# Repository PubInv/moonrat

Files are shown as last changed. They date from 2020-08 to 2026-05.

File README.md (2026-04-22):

DOI: [10.5281/zenodo.17694076](https://zenodo.org/records/17694076) for Release V1.0.1

<h1 align="center">MoonRatII, A Tote-Size Portable Incubator for Rapid Field Work</h1>

Aliases used by other developers include [Moonrat](https://github.com/PubInv/moonrat/tree/main/legacy/moonrat), [Rice MiniCubator](https://github.com/PubInv/moonrat/tree/main/legacy/RiceMiniCubator), and [Rice Petri FI](https://github.com/PubInv/moonrat/tree/main/legacy/RicePetriFI). Visit the [Legacy](https://github.com/PubInv/moonrat/tree/main/legacy) folder for the work of volunteers prior to December 2022 and the hand built prototype.
**MoonratII** development effort began January 2023.   

# Status, March 01, 2026 
| Milestone | Target Date | Status |  
|---|---|---|
| Write and submit paper to *Hardware X*  | Feb 26, 2026  | 🟢 Completed  | 
| Project Closure  | Feb 28, 2026 | 🟢 Completed |

# Status, December 01, 2025  
| Milestone | Target Date | Status |  
|---|---|---|
| Write and submit paper to *Hardware X*  | Dec 04, 2025  | 🟢 Planned  | 
| Project Closure  | Dec 10, 2025 | 🟢 Planned |

# Status, November 17, 2025  
| Milestone | Target Date | Status |  
|---|---|---|
| New 3D printed controller enclosure top ordered from Xometry | Nov 18, 2025  | 🟢 Completed  | 
| Changes to controller enclosure top  | Nov 17, 2025  | 🟢 Completed  | 
| Write and submit paper to *Hardware X*  | Nov 25, 2025  | 🟢 Planned  | 

### Updated controller enclosure top design
- Realigned power port opening with enclosure bottom.
- Shifted and enlarged key cap holes for improved clearance.
Untitled design

# Status, November 02, 2025  
The project build is complete. 




| Milestone | Target Date | Status |  
|---|---|---|
| Write and submit paper to *Hardware X*  | Nov 20, 2025  | 🟢 Planned  | 
| Project Closure  | Nov 21, 2025 | 🟢 Planned |

Screenshot 2025-08-28 at 5 58 10 PM

# Status, August 2025  

The mechanical design phase for the MoonRat II enclosure is officially complete. All recent updates, including finalizing mounting holes, component spacing, and structural parameters, have been committed. The finalized design files are now being test printed. 
Pending a successful print, the enclosure will be ready for assembly.

**Latest Progress -> We’re finalizing all updated FreeCAD 3D models by next week!** This includes:  
- New enclosure design - improved insulation/portability 
- Redesigned controller mounts - 3D-printed, better cable management
- Mechanical optimizations - easier assembly/maintenance

### Next Steps  
| Milestone | Target Date | Status |  
|---|---|---|
| FreeCAD model completion | Aug 20, 2025  | 🟡 In progress |  
| MVP prototype build | Aug 27, 2025 | 🟢 Planned |  
| Write and submit paper to *Hardware X*  | Nov 15, 2025  | 🟢 Planned |  

---  
**Hardware X Paper Focus**:  
- Open-source medical hardware  
- Low-cost neonatal incubator design  
- Reproducibility documentation ([Journal guidelines](https://www.journals.elsevier.com/hardware-x))  

# Status, April 28, 2025  
Created a standalone schematic for heaterboard PCB.

# Status, January 2025  
#### Project presentation on YouTube (Click image to watch)

Watch the video (https://www.youtube.com/watch?v=yTW_BcTsaGw&t=22s)
#### Updated Experiment.com succesful project funding round
In January 2023, 13 generous patrons funded the production of five complete MoonRatII prototypes. we updated them with the [project results](https://experiment.com/projects/tote-size-portable-incubator-for-rapid-field-work
).
#### 2024 field testing resulted in future unit changes:
- Heater board redesign with a Dallas One wire digital temperature thermometer and a 4.7 ohm pull up resistor.
- Design a universal heater board cage to secure the heater board beneath the container lid in any external enclosure.
- Adjust top button spacing in KiCad.
- Add bottom mounting holes to the enclosure.

# Status, November 2024 
A scientific research paper is tentatively scheduled for March 2025 in the HardwareX journal.

# Status, September 2024  
Prototypes of the MoonratII were field tested in two locations - the Galapagos Islands by researcher Auja Bywater and in Tanzania by Dr. Robert Read. The heater features the TMP36 low voltage temperature sensor. A HardwareX scientific research paper is slated for October 2024 publication.

# Status, April 2024  
The MoonRatII team has produced five Printed Circuit Assemblies (Control and Heater) of the Rev 1 PWB for use by the USA team and five Printed Circuit Assemblies (Control and Heater) of the Rev 2 PWB for use by  the Mexico team. Enclosure design for the Controller Assembly of Rev 3 PWB is underway TBA. 

# Status January 2024
[Dr. Robert Read](https://www.pubinv.org) and [Melanie Laporte](https://github.com/melanielaporte) presented the MoonRatII project. Watch the [presentation](https://www.youtube.com/watch?v=yTW_BcTsaGw&t=22s). 

# Current Design Summary
In one schematic and PCB, we have developed a "Control Assembly" and a "Heater Assembly".  
- The Control Assembly will be in an enclosure detachable from the incubation chamber.  
- The Heater Assembly will mounted internal to the incubation assembly under the unit top. Current to a heating pad or pads has changed from the previously used TMP36 low voltage temperature sensor to a digital temperature sensor. 
- A rechargable battery with its recharging station will complete a MoonRatII incubator system.
  
## Image Gallery - Current FreeCAD Assembly Designs
|A |B |C |
| --- | --- | --- |
|  |  | |
|  |  |  |
|  |  |  |  

# 2023 MoonRatII Design

### Fundamental Modularity: The 6-wire appliance 
The connections from the controller to the heater needs only 6 wires:
1. GND (ground, nominally voltage 0).
2. +12V PWR (the heating elements requires approximately 12V power).
3. HEAT ON (Vin).
4. +5V (for the thermometer).
5. SIG - data from the digital "one-wire" format.
6. UNK - a final wire is included for future functionality that is unknown right now.  It is connected as a redundant ground in Rev 1 and Rev 2.

These (esp. the power) should probably be rated for 2 amps, but in practice 1 amp is probably good enough.

## Initial Design Approach Block Diagram
From the 2020 design.  
<a
href="https://user-images.githubusercontent.com/5296671/86680945-b470ad80-bfc4-11ea-9ef6-19c4f70aceba.png">https://user-images.githubusercontent.com/5296671/86680945-b470ad80-bfc4-11ea-9ef6-19c4f70aceba.png  
Basic Structure of Portable Incubator (1)
</a> 

## Motivation
By building a small, portable, intelligent incubator that can maintain constant elevated temperature, a variety of biological experiments and assays can be
performed "in the field" without having access to a electric grid power.

## Origin
This is an offshoot of the [Rapid E. coli project](https://github.com/PubInv/rapid-e-coli). It is an attempt to build a better, smaller, more intelligent
portable incubator that the Armadillo, described [elsewhere](http://jhe.ewb.org.au/index.php/jhe/article/view/127) and buildable from an [instructable](https://www.instructables.com/id/Portable-Petrifilm-Incubator-for-Inexpensive-In-Fi/).

## References (Incomplete)
- Petrifilms [https://www.3m.com/3M/en_US/company-us/all-3m-products/~/ECOLICT-3M-Petrifilm-E-coli-Coliform-Count-Plates/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](https://www.3m.com/3M/en_US/company-us/all-3m-products/~/ECOLICT-3M-Petrifilm-E-coli-Coliform-Count-Plates/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)
- EPA Guidelines [https://19january2017snapshot.epa.gov/sites/production/files/2015-11/documents/drinking_water_sample_collection.pdf](https://19january2017snapshot.epa.gov/sites/production/files/2015-11/documents/drinking_water_sample_collection.pdf)
- Original Incubator Paper [http://jhe.ewb.org.au/index.php/jhe/article/view/127](http://jhe.ewb.org.au/index.php/jhe/article/view/127)
- Construction of a Low-cost Mobile Incubator for Field and Laboratory Use [https://www.jove.com/t/58443/construction-low-cost-mobile-incubator-for-field-laboratory](https://www.jove.com/t/58443/construction-low-cost-mobile-incubator-for-field-laboratory)
- Solar Powered Portable Culture Incubator [https://www.jscimedcentral.com/Pediatrics/pediatrics-3-1063.pdf](https://www.jscimedcentral.com/Pediatrics/pediatrics-3-1063.pdf)
- World Health Organization
- Fuzzy Logic - 

## Acknowledgements
Thanks to [Dr. Sabia Abidi](https://profiles.rice.edu/faculty/sabia-abidi) of Rice University for input and references.

## MoonratII Team
[Robert L. Read - Founder of Public Invention](https://github.com/PubInv/) 

[F. Lee Erickson](https://github.com/ForrestErickson)

[Melanie Laporte](https://github.com/MelanieLaporte)  

[Silvia Castillas](https://github.com/SilviaKarbid)  

[Harshit Kumar](https://github.com/harshit9602)

[Enrique Ruiz](https://github.com/kurama79) 

[Horacio Garcia](https://github.com/HJGV05) 

<hr>
<h6><i> Updated by Melanie Laporte, 20240512</i></h6>

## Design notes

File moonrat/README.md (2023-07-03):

This folder contains information, files and folders, for the hand build Moonrat of 2020.

This folder has work Halimat did including soldering together the board of the incubator which Robert Read took to Tanzania.

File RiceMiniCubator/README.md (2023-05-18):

# RiceMiniCubator  
This folder contains the Moonrat development effort artifacts of Rice University students of 2020.

The RiceMiniCubator  
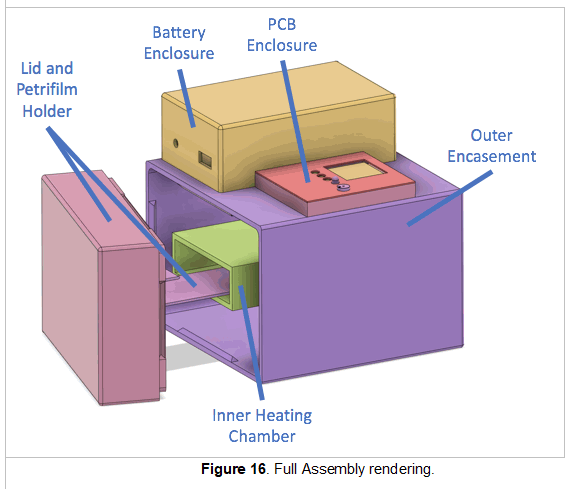
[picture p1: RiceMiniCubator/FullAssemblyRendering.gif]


## Project Summary
Implimented with an Arduino NANO this effort included design of a 3D printed incubation chamber. 
The chamber was insulated with polyurathan expanding foam.

### Electronic Details
The electronics include
* Arduino Nano, Embedded controller assembly
* OLED display, 128x128., User output
* Three buttons, User input
* Piezo Buzzer, User alert
* Termistor, for temprature measurement
* IRLB8721 MOSFET, to switch heater current
* Battery, ???

See: [CircuitHardware_MinicubatorTeam_Cycle5.pdf](CircuitHardware_MinicubatorTeam_Cycle5.pdf) for schematic and PCB screen shots
See: [AssemblyInstructions_MinicubatorTeam_Cycle5.docx](AssemblyInstructions_MinicubatorTeam_Cycle5.docx)

### Project Firmware
See the files in forlder: Code_MinicubatorTeam_Cycle5

### Enclosure Details
See the files in the folder: CAD_MinicubatorTeam_Cycle5

<hr>
<h6><i> This file created by F. Lee Erickson, 20230518</i></h6>

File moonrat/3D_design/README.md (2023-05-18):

# 3D_design
This folder contains artifacts of the design of base to hold a thermos used to incubate samples.

<a
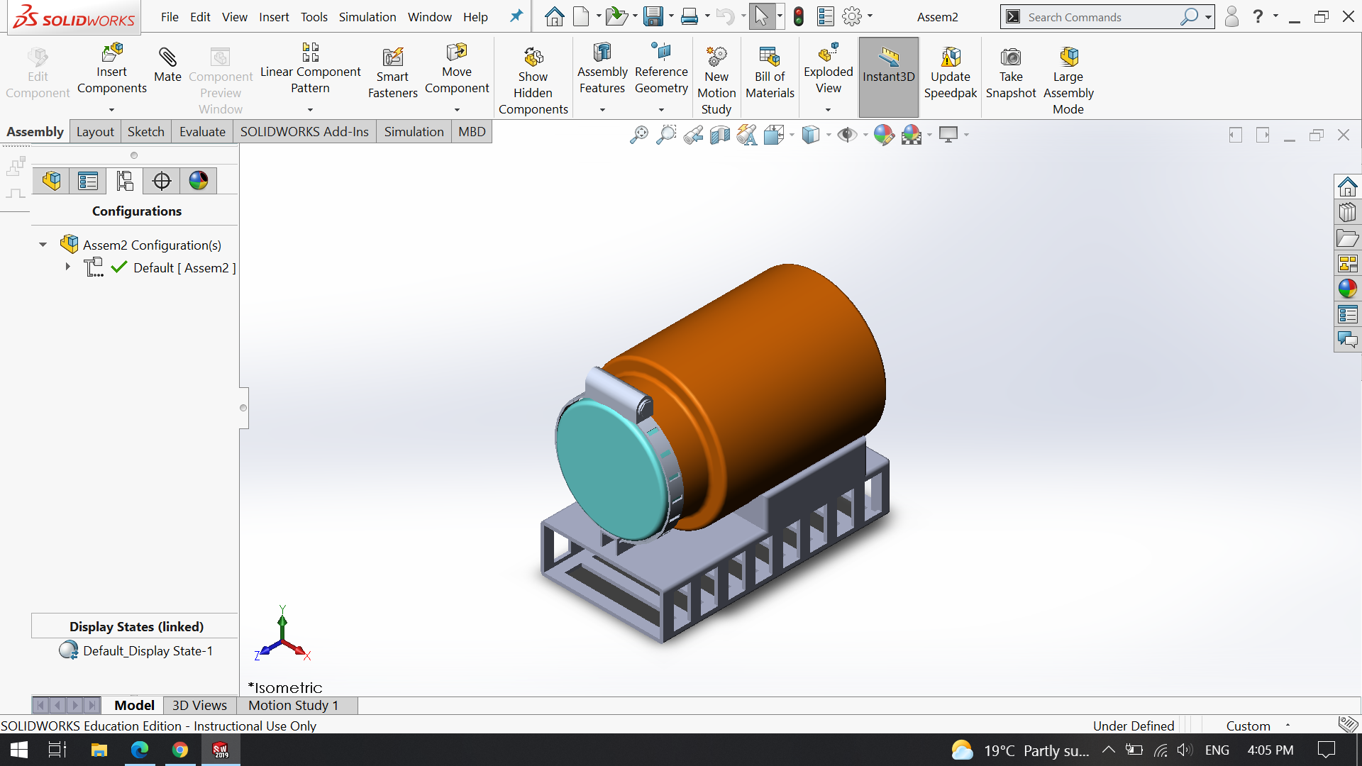
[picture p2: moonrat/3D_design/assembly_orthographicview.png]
href="./assembly_orthographicview.png">
</a> 

<a
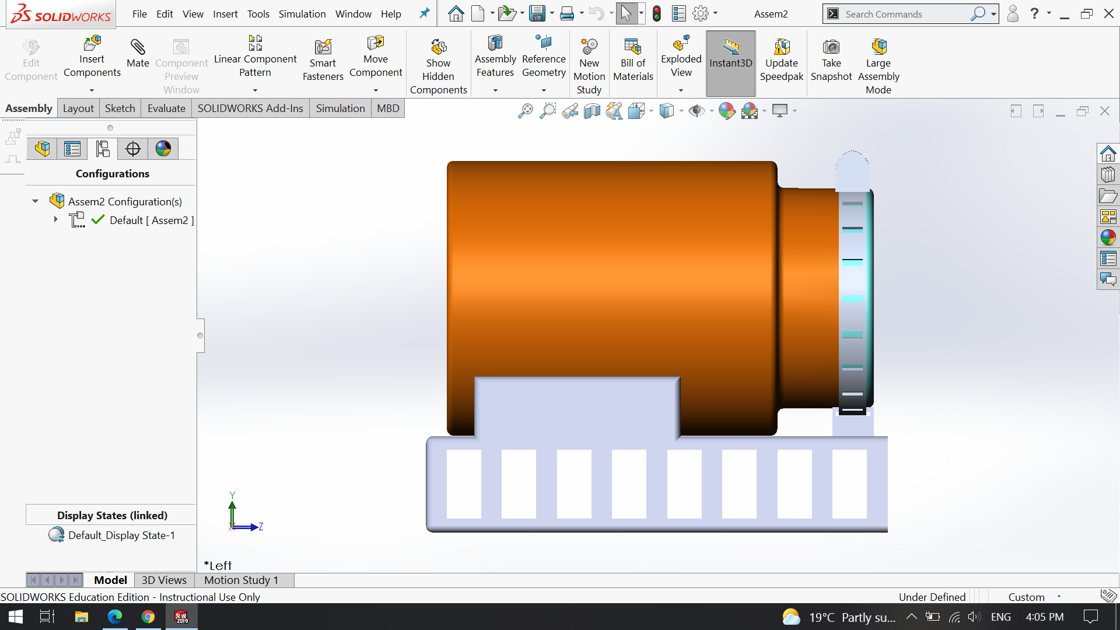
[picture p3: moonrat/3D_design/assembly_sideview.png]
href="./assembly_sideview.png">
</a> 
<a
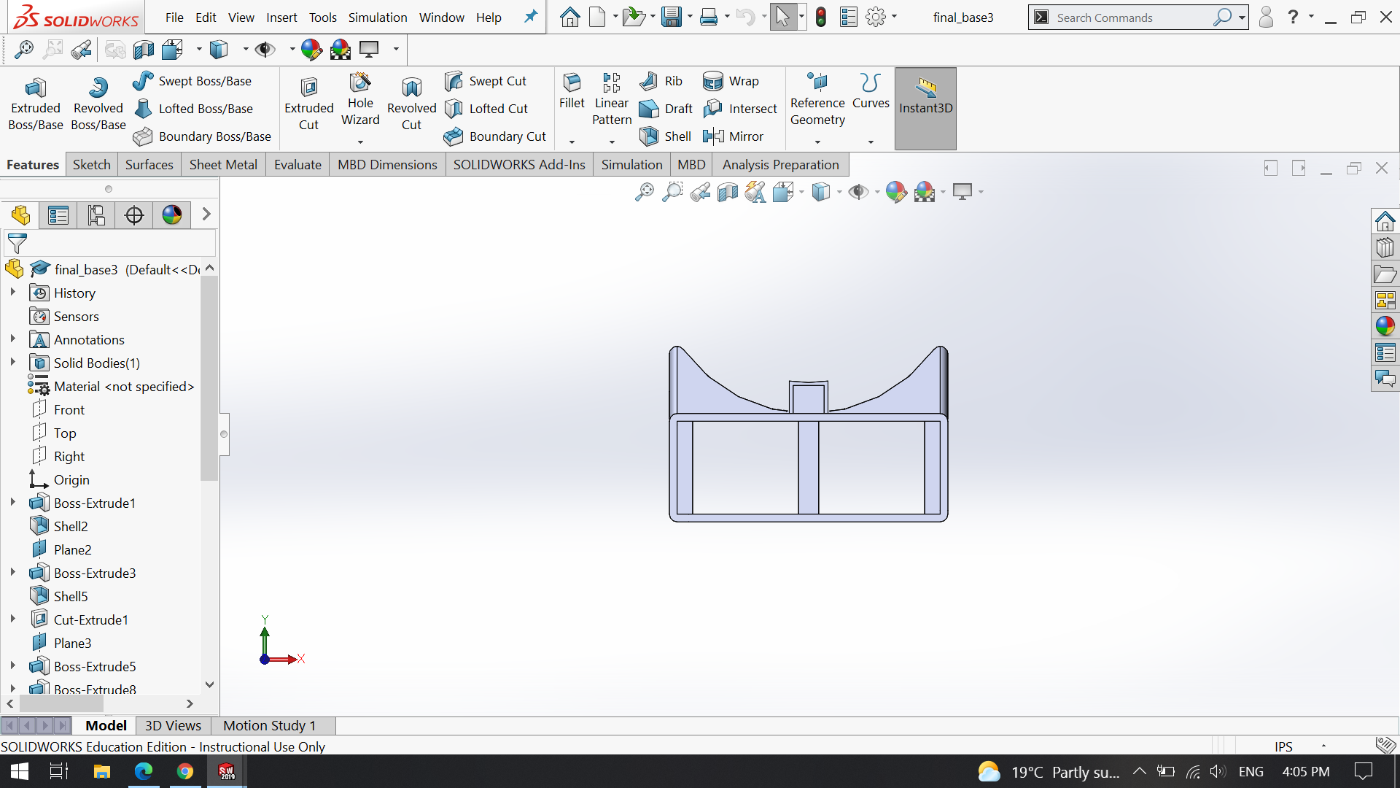
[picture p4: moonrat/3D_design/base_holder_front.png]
href="./base_holder_front.png">
</a> 

<a
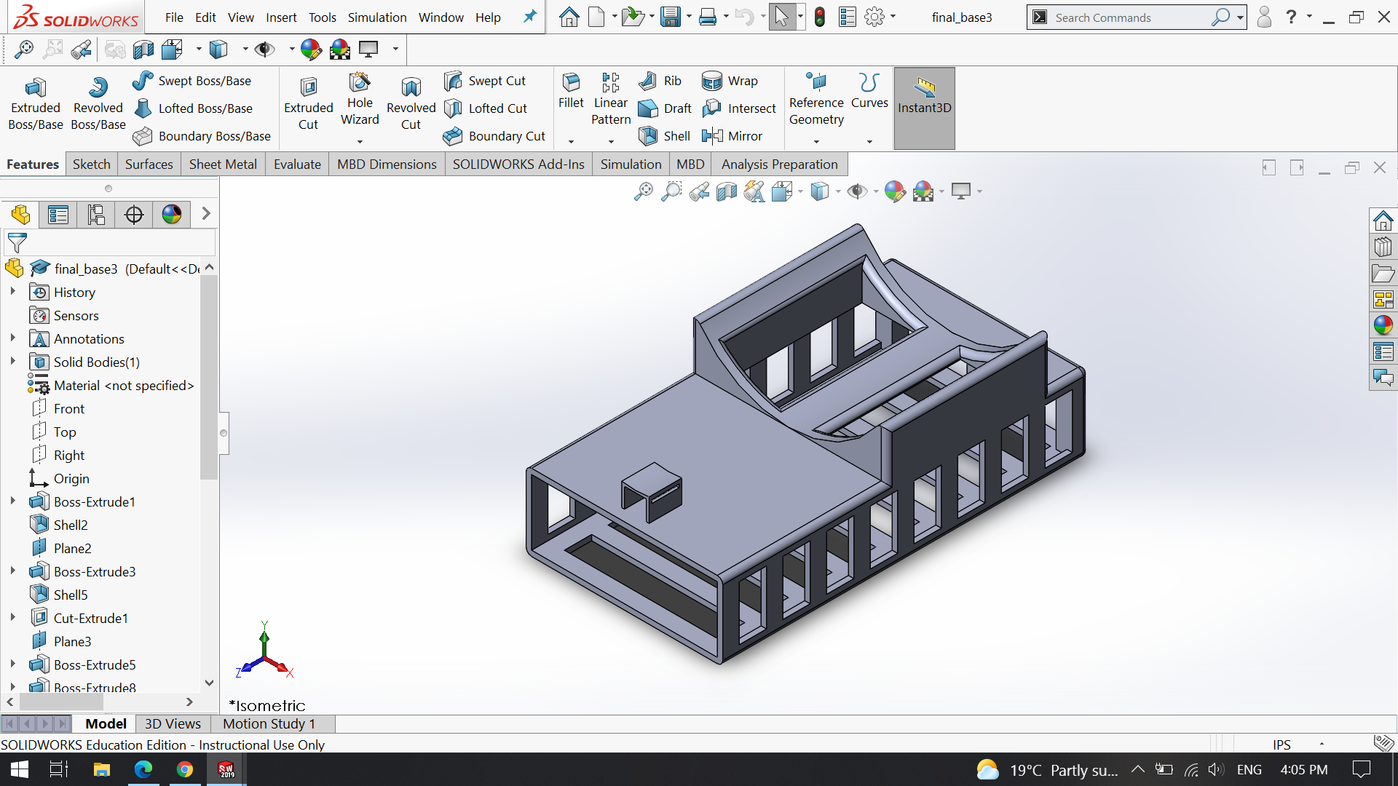
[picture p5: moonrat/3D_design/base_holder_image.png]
href="./base_holder_image.png">
</a> 

<a
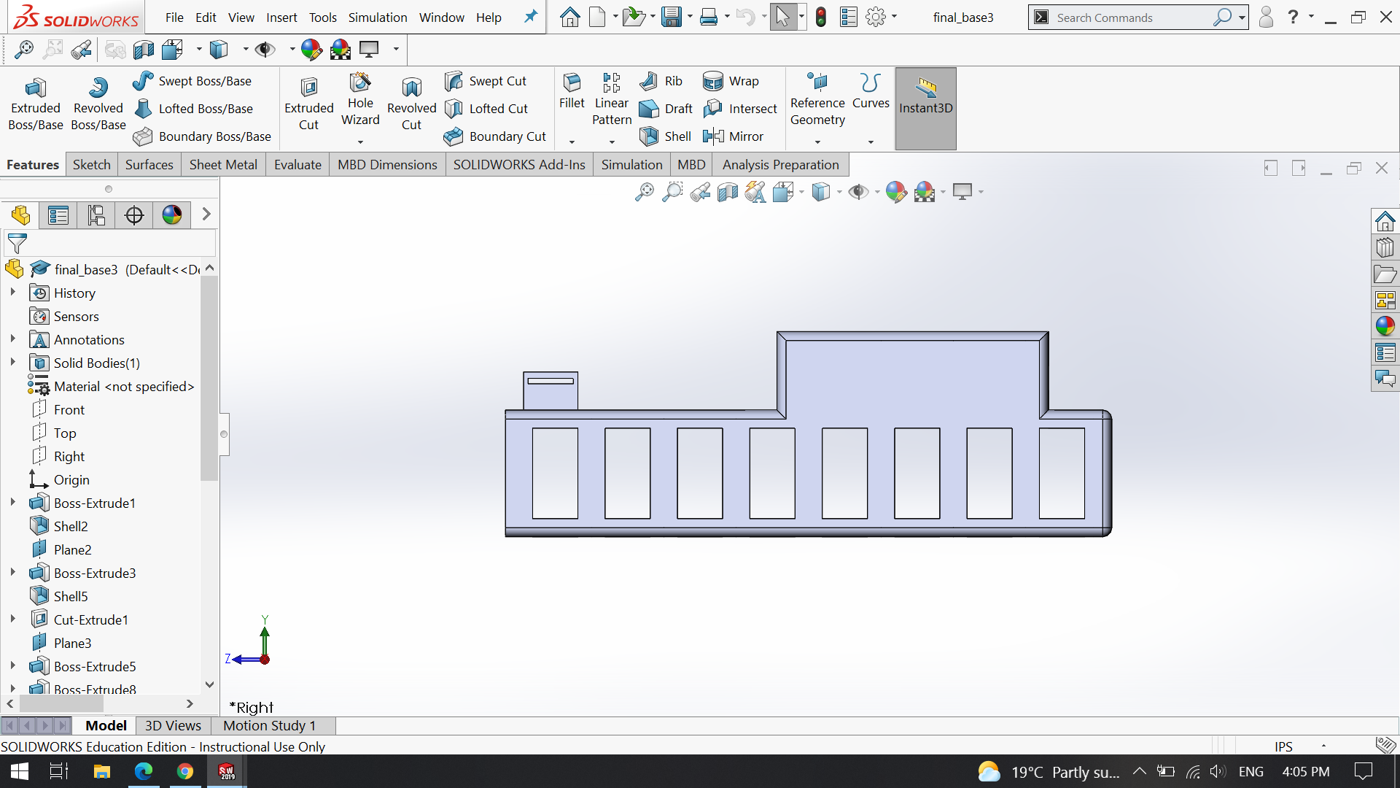
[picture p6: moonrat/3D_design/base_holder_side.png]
href="./base_holder_side.png">
</a> 

[And an animation of the assembly](assembly_animation.mp4)

<hr>
<h6><i> This file created by F. Lee Erickson, 20230518</i></h6>

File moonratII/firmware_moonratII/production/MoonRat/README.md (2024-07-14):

IMPORTANT NOTE: It is necessary to include within the Arduino IDE the eFLL library for the fuzzy controller and the necessary libraries for the Arduino UNO R4 version to be used.

Improvements of this version:
1.- Fixed the temperature conversion needed for the TMP37 sensor embedded in the T6G IC, the ADC reading problems for the Arduino UNO R4 have been fixed.
1.- Added a reset command during incubation by simultaneously pressing the three buttons on the board.
2.- Modified the sample selection screen to directly display the desired incubation temperature (modify if necessary).
3.- A menu was added to select the required incubation hours (modify if necessary).
4.- An acoustic alarm was added to notify that the incubation time has been completed. 
5.- A command was added to exit the completed incubation time alert by simultaneously pressing the up/down buttons.

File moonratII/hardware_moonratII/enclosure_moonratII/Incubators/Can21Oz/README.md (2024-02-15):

# Can21Oz "Incubator"
An experiment in measuring temperature characteristics of a heated system.  


## The incubator, Can21Oz

### Construction
It is fabricated out of a 21oz can which held fruit.  
The can empty weight is 62gm assumed to be steel.  
The can when full of water is 600 to 649 gm.  
The water mass is therefor about 587 gm  
The sides of the can are insulated with a layer of bubble wrap about 3/8 inch think.  
The top is open.  
The can is sitting on a 3 1/2" thick 89 mm polystyrine foam block.  

#### Can Dimensions
Radius = (3 3/8)/2 = 1.6875" = 42.9mm  
Height = 4 1/2 " =  114.3mm  
Volume = Pi * R^2 * H = Pi* 42.9^2 * 114.3 = 331,000 mm^3  
Surface Area = (2 * Pi * R^2) + (2 * pi * R * H) = 11,560 + 30,810 = 42,370 mm^2  

#### System Heater
A relay switched, 120VAC, Immersion heater.   
https://www.amazon.com/dp/B01M0Q84BR?psc=1&ref=ppx_yo2ov_dt_b_product_details  
120 volts and 300 watts. UL approved.  

### The System
| This "incubator" is more like a hot water bath. 	| The 120V AC Heating Element 	| 	|
|---	|---	|---	|
|  	|  	| 	|

## Instruments, Temperature Measurement
Three MAX31850 thermocouple amplifiers with K type thermocouples immersed into the water in the 21Oz can.  
They are held to the side of the can with a wooden cloths pin.  
The exact location of the thermo couple junctions was not well constrained.  
Measurement displayed by a Cumulocity dash board.  

## Experiments
### Near Boiling, Warm Up / Cool Down
**Heat Up**  
At 4:02 PM EST or so plug in heater.  

At about 4:04 the temperature had risen about 23 degrees or about 1/e of the way from 19 to 95C.  
Time rise would be about 120 seconds **but this curve is not a full exponential** so the rise time is longer.

**Cool Down**  
Unplug at about 4:12 PM EST.  
From a peak of about 98 to 19 is 79. About 1/3 of that is 24 so at 98-24 about 75 C which happnes at about 4:25 PM.  
  
4:12 from 4:25 is 13 minutes or 780 seconds for about one time constant.

### One Minute Rectangular Heat / Cool
Heat with a rectantular profile at the full power of the immersion heater.
At 10:34💯 AM EST connect heater to 120V AC.  
At 10:35:00 AM EST disconnect heater from 120V AC.  

**Heat Up Detail**
Just before or at turn on  

About one minute later  


**Cool Down Detail**  


The tempaterature at the start was the ambient of about 18 C.  
The peak temperature on the thermocouple labeled Getter reached 56.25 C.  


On the cool down, the 1/e (One time constant) temperature would be at about 42 degrees which happened at about 10:38. From the 10:35 turn off this is three minutes or 180 seconds.  


## Conclusion.
The system has significantly faster rise time than fall time.  
The time constant for cooling down from near boiling temprature was 780 seconds while the time constant from a peak of 52.25 was only 180 seconds.  
I hypothesize that, for the one minute heating experiment, the heat was not fully distributed through the water in the sample (it was not in equilibrium).

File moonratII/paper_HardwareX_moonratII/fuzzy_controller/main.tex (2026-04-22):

\documentclass{article}
\usepackage{graphicx} % Required for inserting images

\usepackage[backend=biber]{biblatex}
\addbibresource{Bibliography.bib}

\title{The Fuzzy Logic Controller Used in the Moonrat~II}
\author{Horacio García--Vázquez}
\date{April 2026}

\begin{document}

\maketitle

\section{Fuzzy Logic Controller Strategy}

Precise and adaptive temperature control is essential in cultivation chambers for Petrifilm samples. To achieve this, we implemented a \textit{Mamdani--type fuzzy controller}. This approach is efficient and easy to apply to systems with slow dynamic evolution, such as temperature and heat control processes \cite{Sherif2014,Vijayalakshmi2017,Izquierdo2018,Coban2019,Sakaci2021}. 

To enable integration into an embedded system, we employed the \textit{Embedded Fuzzy Logic Library (eFLL)} developed by AJ Alves \cite{eFLL}. This library provides a standardized implementation of fuzzy control for embedded computing platforms.  

The system relies solely on measuring the chamber temperature and a predefined reference value. Consequently, we designed a \textit{Mamdani--based fuzzy control scheme} with two input variables:
\begin{itemize}
\item \textbf{Error} ($e$): The difference between the measured temperature $temp_c$ and the desired temperature $temp_r$:
\begin{equation}
e = temp_c - temp_r
\end{equation}

\item \textbf{Error difference} ($\Delta e$): The discrete change in error between two sampling instants:
\begin{equation}
\Delta e = e(t_k) - e(t_k - 1)
\end{equation}
\end{itemize}

We defined both input variables using three fuzzy sets: \textit{negative, zero, and positive}. We established the relationship between these variables and the controller’s response through a \textit{set of fuzzy rules}, as detailed in Table~\ref{tab:fuzzy_rules}.  

\begin{table}[h]
\centering
\renewcommand{\arraystretch}{1.3}
\setlength{\tabcolsep}{10pt}
\begin{tabular}{cc|ccc}
\hline\hline
\multicolumn{2}{c|}{\multirow{2}{*}{\textbf{Control}}} & \multicolumn{3}{c}{\textbf{Error Difference}} \\ 
\cline{3-5}
\multicolumn{2}{c|}{} & \textbf{Negative} & \textbf{Zero} & \textbf{Positive} \\ 
\hline\hline
\multirow{3}{*}{\textbf{Error}} 
& \textbf{Negative} & P & P & Z \\ \cline{2-5}
& \textbf{Zero}     & P & Z & N \\ \cline{2-5}
& \textbf{Positive} & Z & N & N \\ 
\hline\hline
\end{tabular}
\caption{Fuzzy control rule table. P = Positive, Z = Zero, N = Negative.}
\label{tab:fuzzy_rules}
\end{table}

The system's output variable is the \textit{PWM frequency}, which regulates the power supplied to the thermal pad responsible for heating the chamber. We defined this output using three fuzzy sets: \textit{high, medium, and low frequency}.  

We carried out the fuzzy system design, including the membership functions of the input and output variables, using the \textit{Fuzzy Logic Designer} toolbox in MATLAB.~Figure~\ref{fig:membership_functions} illustrates the configuration of the membership functions and the assigned ranges for each fuzzy set.

\begin{figure}[ht]
\centering
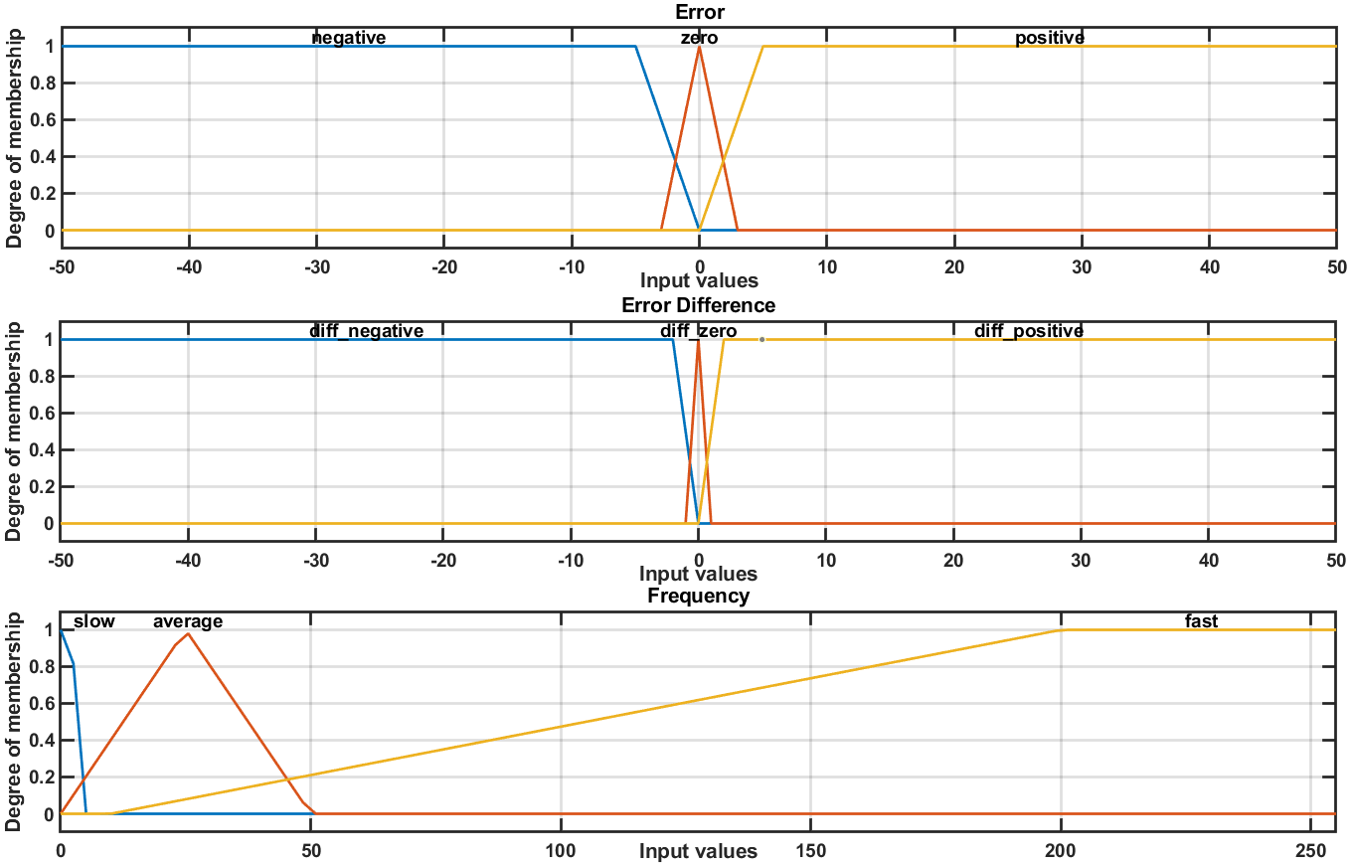
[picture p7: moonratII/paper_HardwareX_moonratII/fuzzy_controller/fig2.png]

\caption{Membership functions for the fuzzy system inputs and outputs, designed using the Fuzzy Logic Designer toolbox in MATLAB.}
\label{fig:membership_functions}
\end{figure}

Finally, we defined the \textit{defuzzification process} and the configuration of membership degrees according to the parameters shown in Figure~\ref{fig:defuzzification_config}.  

\begin{figure}[ht]
\centering
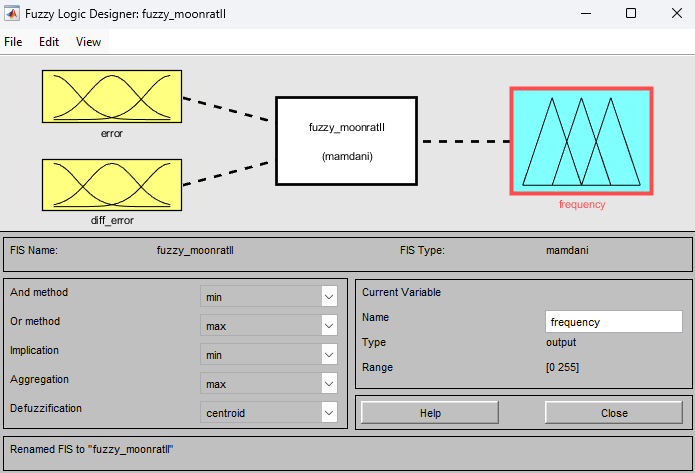
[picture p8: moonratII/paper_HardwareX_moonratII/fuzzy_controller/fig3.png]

\caption{Defuzzification and membership function configuration for the fuzzy control system.}
\label{fig:defuzzification_config}
\end{figure}

\printbibliography

\end{document}

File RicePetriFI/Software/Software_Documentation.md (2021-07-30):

# Team Petri-FI Software Documentation

## Introduction

Team Petri-FI made progress in designing software to perform the incubation of Petrifilms inside of a small heating chamber equipped with a digital thermometer and heating pad(s). The code itself includes contributions from previous student teams as well as the Public Invention Moonrat team. The software’s goal is to provide an intuitive user experience for setting up an incubation and performing that incubation over the desired time period (generally, 48 hours). Team Petri-FI has developed two sketches for the Arduino Uno; these files can be uploaded to the Arduino, and the incubator can be powered with a battery. This documentation will describe the functionality of the existing code and the differences between the two files.

## "PetriFI.ino"

The main Arduino sketch that Team Petri-FI has used is called “PetriFI.ino.” This sketch was the original Team Petri-FI file, and it has undergone the most testing. This sketch makes greater use of Minicubator’s heating algorithm, which makes use of temperature thresholds to control the temperature inside the incubator. For example, this software will wait for the temperature to drop below an appropriate temperature before turning on the heating pad, and waiting to reach the target temperature again. In our own incubation testing, we have observed large temperature oscillations that result from the use of this algorithm (1 to 2 degrees Celsius below the target temperature), in which the temperature swings past the thresholds set by the software. In testing, this software was able to keep the temperature near the target temperature for a full 48-hour incubation, and it was still able to successfully incubate E. coli colonies.

Upon startup, this sketch allows users to set the duration and temperature of the incubation, and start the incubation. Once the incubator reaches the target temperature, it will enter the main incubation phase, and will proceed for the full duration (in hours) set at the beginning. The user interface is still limited, and does not allow interaction during the main incubation phase.

For data logging, this code utilizes a microSD card connected to the OLED screen. Our team struggled to get the SD card working consistently, so further testing is still required. We have written a function to write a single temperature to the SD card (into a .csv file), along with the time at which the temperature was recorded. For testing purposes, this sketch will record a temperature value occasionally, about every minute, but in the future the code should be able to record data at more consistent intervals. It may also be valuable to keep a running average of data points and write the average to the SD card every couple of minutes. Additionally, for testing, we chose to also write some values during the pre-heating phase. Since the “clock” hasn’t started during this phase, and to prevent confusion with legitimate values recorded during the incubation, we have assigned these a time value of -1. Later, these temperature values can be omitted, since they are not as important in evaluating the success of a full incubation.

When adding the capabilities for the SD card, we found that it was important which pins were connected at the Arduino Uno. In particular, the “SPI Bus” (pins 10-13) of the Uno were important for writing to the SD card. Here, we have included a list of pins that we have used with the Uno. Below, the first seven connections are to the OLED screen, which contains both the display and the SD card. The SD Chip Select pin must be the hardware SS pin (pin 10 on the Uno) so that the SD card can use the SPI bus. If possible, all of pins 10-13 should be connected as described below in order to utilize the SD card. The screen itself will work even if the SPI bus is not used, but the SD card requires the SPI bus (SDCS, MOSI, MISO, and SCLK). 

### Arduino Uno Pin Setup

| Connection | Pin Number |
|---|---|
| SD Chip Select (SDCS) | 10 |
| MOSI | 11 |
| MISO | 12 |
| SCLK | 13 |
| DC | 4 |
| OLED Chip Select (OLED CS) | 5 |
| RST | 6 |
| Up Button | 3 |
| Select Button | 8 |
| Down Button | 9 |
| Transistor (Heating Pad) | 2 |
| LED | 0 |
| One-Wire Bus (Digital Thermometer) | 7 |
| Piezo Alarm | A1 (Analog Pin 1) |

## "PetriFI_PID.ino"

The most recent sketch is called “PetriFI_PID.ino,” and it is an attempt to implement a PID controller for temperature. This separate sketch was made to isolate the many changes that would need to be made for the PID controller. The goal of the PID controller is to hold the temperature perfectly steady by controlling the heating pad. This would alleviate the problems that we have observed with temperature oscillations of more than one degree Celsius. This sketch is designed to be almost identical in functionality to the original sketch, but to better control the temperature during the incubation period.

Currently, this PID controller code is not working. This sketch makes use of the “PID_v1.h” Arduino library. In our understanding, the PID controller will update its output as a value between 0 and 255. This value should describe how much the heating pad needs to be turned on after each loop. Then, the sketch can use that value to control the heating pad in a couple of ways. The most fluid way to control the heating pad is to use pulse-width modulation with the 0-255 PID output. However, the time constant of the chamber is fairly high (it takes multiple minutes for the temperature to change by even just one degree Celsius), and pulse-width modulation would mean that duty cycle calculations (what percentage of the time the heating pad is ON) might be less accurate. Additionally, we were somewhat concerned about switching losses associated with switching the heating pad state multiple times each second. Instead, we attempted to convert the PID output (0-255) into either a “heating pad on” or “heating pad off” command, using a threshold. Thus, when the output reaches the threshold, then the heating pad would be turned on until the output fell below the threshold again.

We have not yet been able to use the PID controller, but we have used print statements to perform some troubleshooting. Most recently, the output of the PID controller remained at 0 despite adjustments to various parameters. We believe that once the PID controller is implemented into this sketch, it may require some “tuning” of the threshold and the PID parameters, but that it will be able to control the temperature better than “PetriFI.ino.” Below we have provided some of the resources related to the PID library that were useful to us.

https://playground.arduino.cc/Code/PIDLibrary/

https://github.com/br3ttb/Arduino-PID-Library

## Areas for Further Testing or Improvement

We hope that a few improvements can be made to our software in the future. First, we believe that the PID controller would significantly improve the consistency of incubation. Some debugging is still needed for this, but “PetriFI_PID.ino” should be nearly ready to use if the PID controller is correctly implemented.

We have also worked hard on a new user interface that would help make the device “smarter” and more intuitive to work with. It would also allow users to interact with it during the incubation cycle. We have provided diagrams and many more details within our user interface documentation, but we believe that it would be a great improvement to the user experience. Based on the lifespan of the LEDs inside the OLED screen, it may also be important to create a timer for the screen to turn off during the main incubation period to reduce power consumption and increase the lifespan of the screen.

While the SD card did not work consistently with our system, it was occasionally able to write a temperature value to the SD card. On another system, or with a few adjustments, the SD card may be able to work very consistently. As part of the data display, it may also be useful to provide functions to read desired values from the SD card and display them onto the user interface. Therefore, we have a created part of a function, “readTempFromSD(int seconds),” that could read a single temperature value from the SD card. This could be used to improve data logging and retrieval capabilities, so that the user would not need to remove the SD card from its slot in order to evaluate the success of an incubation.

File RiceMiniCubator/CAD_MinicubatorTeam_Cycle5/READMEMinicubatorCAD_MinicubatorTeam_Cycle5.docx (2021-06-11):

Note: All drawings except for the inner heating chamber remain the same as from Cycle 4. The inner heating chamber has been revised, but can still be represented by the green inner chamber render from the previous cycle as the inner dimensions are equal.

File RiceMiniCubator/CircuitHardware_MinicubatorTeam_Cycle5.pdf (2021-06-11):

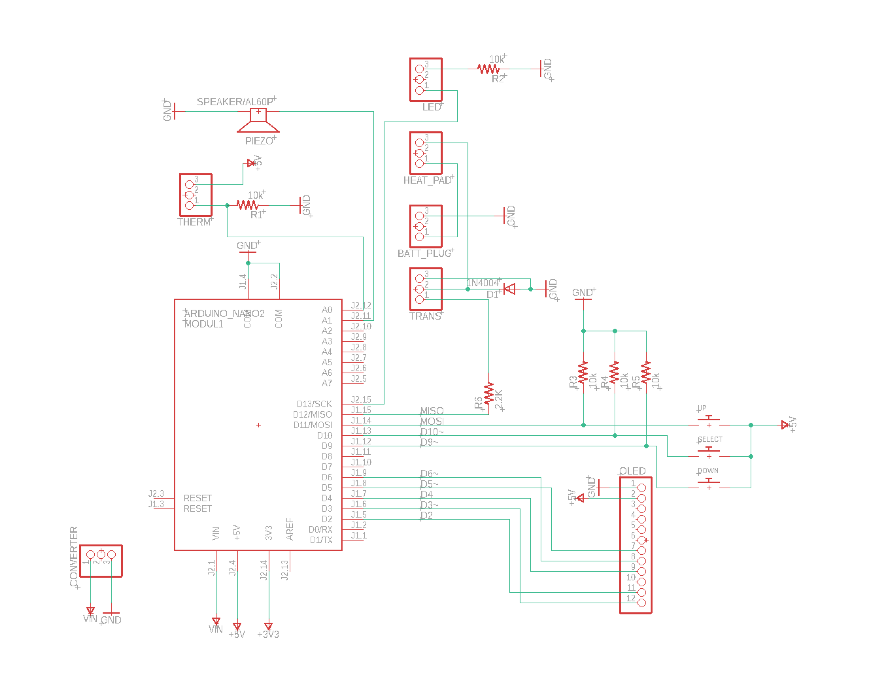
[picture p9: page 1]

Circuit
Diagram

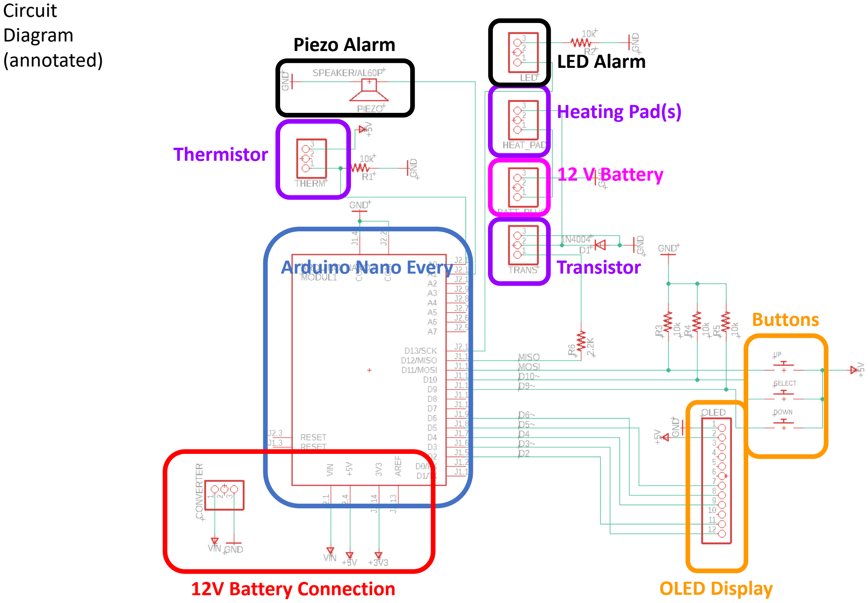
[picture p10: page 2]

Circuit
Diagram
(annotated)

Buttons

OLED Display

### 12 V Battery

Heating Pad(s)
Thermistor

Piezo Alarm
LED Alarm
Arduino Nano Every | Transistor

12V Battery Connection

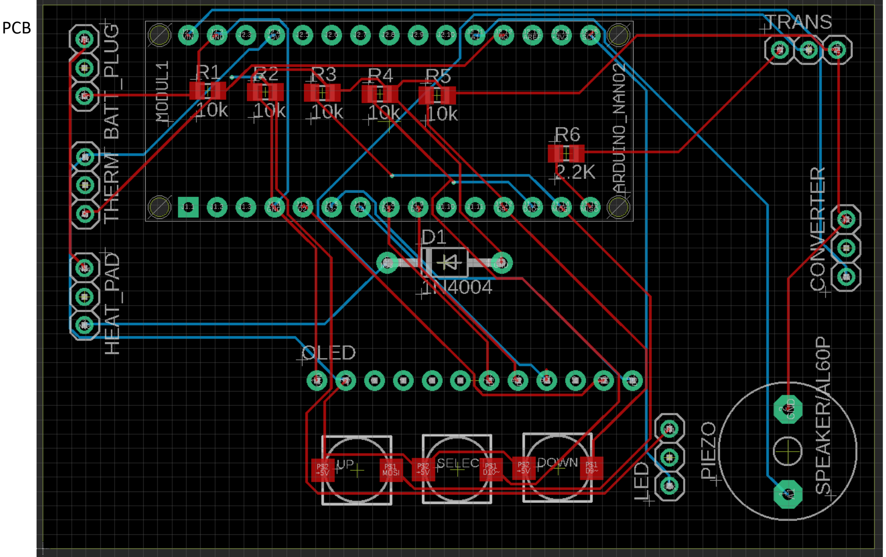
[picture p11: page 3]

PCB

## Temperature Control

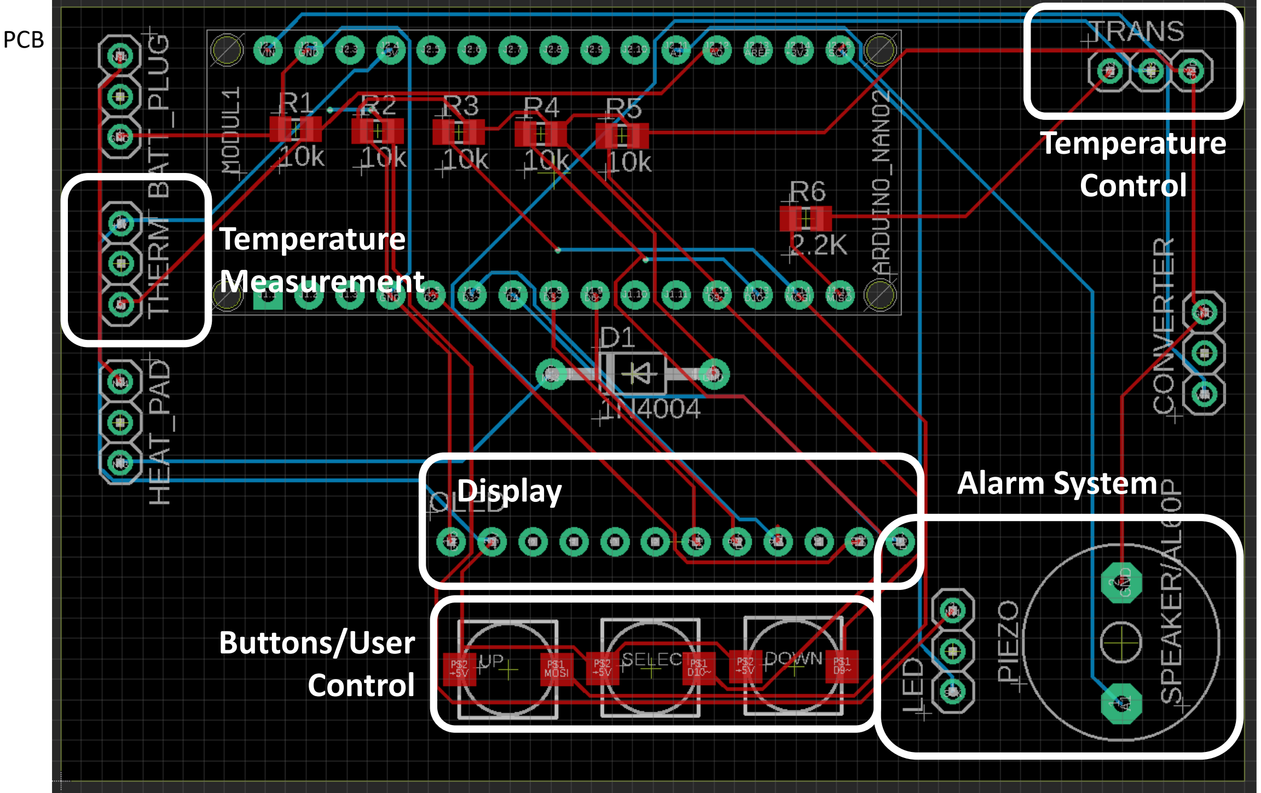
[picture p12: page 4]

PCB

## Alarm System

## Buttons/User Control

## Display

## Temperature Measurement

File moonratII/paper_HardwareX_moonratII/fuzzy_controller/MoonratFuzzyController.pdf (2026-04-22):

# The Fuzzy Logic Controller Used in the Moonrat II

Horacio Garc´ıa–V´azquez

April 2026

## 1 Fuzzy Logic Controller Strategy

Precise and adaptive temperature control is essential in cultivation chambers for Petrifilm samples. To achieve this, we implemented a Mamdani–type fuzzy controller. This approach is efficient and easy to apply to systems with slow dynamic evolution, such as temperature and heat control processes [1, 6, 4, 3, 5].
To enable integration into an embedded system, we employed the Embedded Fuzzy Logic Library (eFLL) developed by AJ Alves [2]. This library provides a standardized implementation of fuzzy control for embedded computing platforms.
The system relies solely on measuring the chamber temperature and a predefined reference value. Consequently, we designed a Mamdani–based fuzzy control scheme with two input variables:
- Error (e): The difference between the measured temperature tempc and the desired temperature tempr:
e = tempc − tempr | (1)
- Error difference (∆e): The discrete change in error between two sampling instants:
∆e = e(tk) − e(tk − 1) | (2)

We defined both input variables using three fuzzy sets: negative, zero, and positive. We established the relationship between these variables and the controller’s response through a set of fuzzy rules, as detailed in Table 1.
The system’s output variable is the PWM frequency, which regulates the power supplied to the thermal pad responsible for heating the chamber. We defined this output using three fuzzy sets: high, medium, and low frequency. We carried out the fuzzy system design, including the membership functions of the input and output variables, using the Fuzzy Logic Designer toolbox in MATLAB. Figure 1 illustrates the configuration of the membership functions and the assigned ranges for each fuzzy set.

1

2*Control | Error Difference
| | Negative | Zero | Positive
3*Error | Negative | P | P | Z
| Zero | P | Z | N
| Positive | Z | N | N

Table 1: Fuzzy control rule table. P = Positive, Z = Zero, N = Negative.

Finally, we defined the defuzzification process and the configuration of membership degrees according to the parameters shown in Figure 2.

## References

[1] S. M. Abuelenin. “Decomposed interval Type–2 fuzzy systems with application to inverted pendulum”. In: International Conference on Engineering and Technology (ICET) (2014), pp. 1–5. doi: 10 . 1109 / ICEngTechnol . 2014.7016752.
[2] AJ Alves. Embedded Fuzzy Logic Library (eFLL). GitHub repository. Accessed: 2024-08-12. 2016. url: https://github.com/alvesoaj/eFLL.
[3] M. Coban and M. Fidan. “Fuzzy Logic Based Temperature Control”. In: 2019 3rd International Symposium on Multidisciplinary Studies and Innovative Technologies (ISMSIT) (2019), pp. 1–4. doi: 10.1109/ISMSIT. 2019.8932906.
[4] S. S. Izquierdo and L. R. Izquierdo. “Mamdani Fuzzy Systems for Modelling and Simulation: A Critical Assessment”. In: Journal of Artificial Societies and Social Simulation 21.3 (2018). doi: 10.18564/jasss.3660.
[5] F. H. Sakaci and S¸. C¸ . Yener. “Design of a Microcontroller-Based Heating System Controller Using Fuzzy Logic”. In: 2021 Innovations in Intelligent Systems and Applications Conference (ASYU) (2021), pp. 1–4. doi: 10. 1109/ASYU52992.2021.9599011.
[6] V. Vijayalakshmi. “Design of superheated steam temperature control using fuzzy logic controller”. In: 2017 Third International Conference on Science Technology Engineering & Management (ICONSTEM) (2017), pp. 1076– 1084. doi: 10.1109/ICONSTEM.2017.8261365.

2


Figure 1: Membership functions for the fuzzy system inputs and outputs, designed using the Fuzzy Logic Designer toolbox in MATLAB.


Figure 2: Defuzzification and membership function configuration for the fuzzy control system.

3

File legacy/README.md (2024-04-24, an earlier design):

This folder is legacy files and folder for Moonrat prior to January 2023.  
See each folder for fuller explination.
# The Legacy README.md 
<hr>  

# Tote-Size Portable Incubator for Rapid Field Work
Aliases used by other developers include Moonrat, Rice MiniCubator, and Rice Petri FI. 

# 2020 Status
A single device was hand fabricated by Public Invention Volunteers in about 2020.
This device was field tested in Tanzania.
This 2020 device became the starting point for further development of the Moonrat II starting in 2023

## Motivation

By building a small, portable, intelligent incubator that can maintain constant elevated temperature, a variety of biological experiments and assays can be
performed "in the field" without having access to a electric grid power.

## Origin

This is an offshoot of the [Rapid E. coli project](https://github.com/PubInv/rapid-e-coli). It is an attempt to build a better, smaller, more intelligent
portable incubator that the Armadillo, described [elsewhere](http://jhe.ewb.org.au/index.php/jhe/article/view/127) and buildable from an [instructable](https://www.instructables.com/id/Portable-Petrifilm-Incubator-for-Inexpensive-In-Fi/).

## Hand Built 2020 Design

Our current (2020) design uses a soup thermos to have good insulation. 3D printed parts hold the Petrifilms inside the thermos and way from the metal edges.
Additional parts hold the heating cloth and thermometer, which our powered and sensed by an external Arduino.

<a
href="https://user-images.githubusercontent.com/5296671/130527922-66cce437-a89f-4815-a980-bc79295f1a5a.JPG">https://user-images.githubusercontent.com/5296671/130527922-66cce437-a89f-4815-a980-bc79295f1a5a.JPG
IMG-2511
</a> 

Our previous design use a "casette" which is bolted to the inside of the lid of a thermos bottle, shown below. Our circuit is on a breadboard, and we have not yet designed the enclosure for the electronics integrated into the cap or as a holder for the bottle. We use a 3D printed bracket to hold the Thermos bottle. We believe this is the most compact design which will be thermally efficient.

### 2020 Design Thermos Bottle in Bracekt With Battery in Place
<a
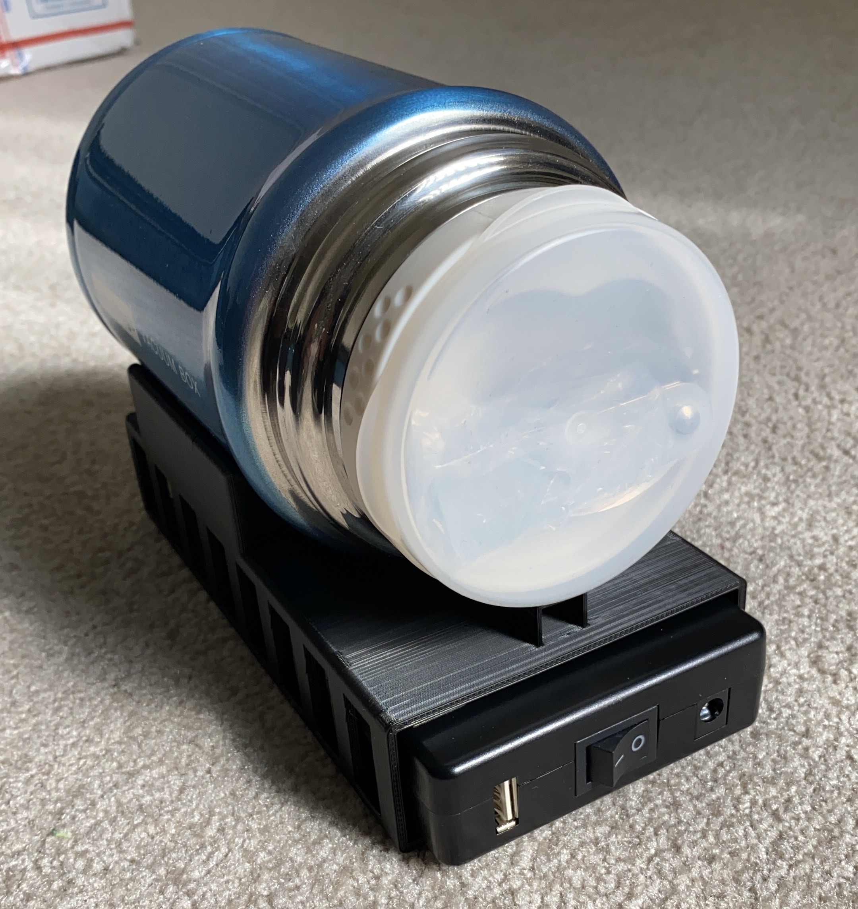
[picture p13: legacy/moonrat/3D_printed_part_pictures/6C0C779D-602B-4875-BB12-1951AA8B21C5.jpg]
href="./moonrat/3D_printed_part_pictures/6C0C779D-602B-4875-BB12-1951AA8B21C5.jpg">
Thermos Bottle In Bracket With Battery
</a> 

### Bracket by Itself
<a
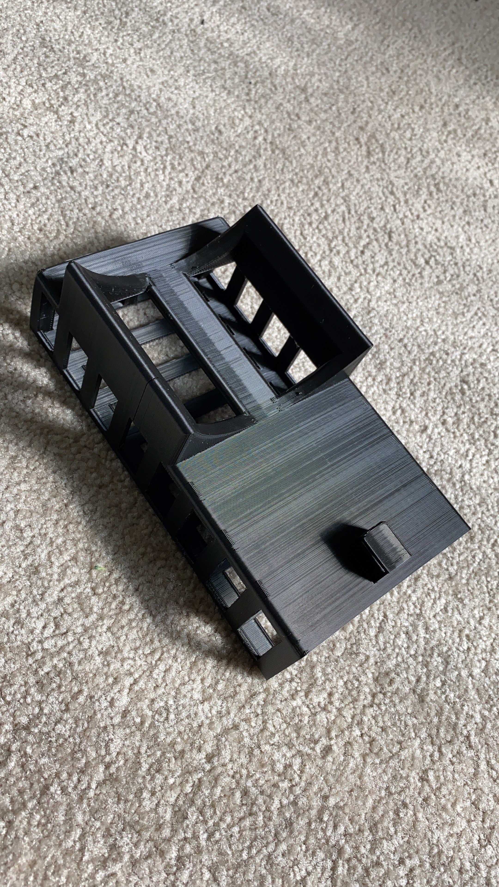
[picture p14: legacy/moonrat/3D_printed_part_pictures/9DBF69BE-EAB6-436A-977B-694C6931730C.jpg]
href="./moonrat/3D_printed_part_pictures/9DBF69BE-EAB6-436A-977B-694C6931730C.jpg">
Bracket by itself
</a> 

Our analysis is preliminary, but our current tests show we at 25C ambient temperature we can hold the needed 35C incubation temperature with only
(12V * 12V / 8 Ohms * 6% duty cycle * 48 hours) = 51.84 Watt Hours.  This will have to be supplied by a battery pack, which will be about the same size as the Thermos bottle.

<a
href="https://user-images.githubusercontent.com/5296671/110479740-580de280-80ab-11eb-90c4-a859c0519b3d.png">https://user-images.githubusercontent.com/5296671/110479740-580de280-80ab-11eb-90c4-a859c0519b3d.png
MoonratWithBreadBoard
</a> 

## Initial Design Approach

<a
href="https://user-images.githubusercontent.com/5296671/86680945-b470ad80-bfc4-11ea-9ef6-19c4f70aceba.png">https://user-images.githubusercontent.com/5296671/86680945-b470ad80-bfc4-11ea-9ef6-19c4f70aceba.png
Basic Structure of Portable Incubator (1)
</a> 

## References (Incomplete)

1. Petrifilms: [https://www.3m.com/3M/en_US/company-us/all-3m-products/~/ECOLICT-3M-Petrifilm-E-coli-Coliform-Count-Plates/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](https://www.3m.com/3M/en_US/company-us/all-3m-products/~/ECOLICT-3M-Petrifilm-E-coli-Coliform-Count-Plates/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)
1. EPA Guidelines: [https://19january2017snapshot.epa.gov/sites/production/files/2015-11/documents/drinking_water_sample_collection.pdf](https://19january2017snapshot.epa.gov/sites/production/files/2015-11/documents/drinking_water_sample_collection.pdf)
1. Original Incubator Paper - [http://jhe.ewb.org.au/index.php/jhe/article/view/127](http://jhe.ewb.org.au/index.php/jhe/article/view/127)
1. Construction of a Low-cost Mobile Incubator for Field and Laboratory Use [https://www.jove.com/t/58443/construction-low-cost-mobile-incubator-for-field-laboratory](https://www.jove.com/t/58443/construction-low-cost-mobile-incubator-for-field-laboratory)
1. Solar Powered Portable Culture
Incubator [https://www.jscimedcentral.com/Pediatrics/pediatrics-3-1063.pdf](https://www.jscimedcentral.com/Pediatrics/pediatrics-3-1063.pdf)

## Acknowledgements
Thanks to Dr. Sabia Abidi of Rice University for input and references.

<hr>
<h6><i> This file created by Melanie Laporte and F. Lee Erickson, 20231217</i></h6>
<h6><i> Udated by copying much of the original landing page README.md into this document the by F. Lee Erickson, 20240424</i></h6>

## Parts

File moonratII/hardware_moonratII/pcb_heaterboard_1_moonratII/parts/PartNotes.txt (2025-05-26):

20250520 
KF128 Screw Terminal (2.54 mm pitch)
https://grabcad.com/library/kf128-screw-terminal-2-54-mm-pitch-1

Added a folder of step files.
------
X
Screw terimonal file: KF128-2.54-6P.step
From: https://grabcad.com/library/kf128-screw-terminal-2-54-mm-pitch-1/details?folder_id=11526606

Opossum from: 
https://www.thingiverse.com/thing:2978135
License
Opossum byAmnsonis licensed under theCreative Commons - Attributionlicense.
Post a Make!
Remember to come back and post what you've printed as a Make. It's good for the designer and the community (that means you)!

OLED Display
File: SSD1306_OLED_Display(128x64).step
https://grabcad.com/library/pantalla-oled-0-96-128x64-1

File: OLED Display 0.96_.step from
https://grabcad.com/library/0-96-oled-display-module-new-1

Pantella OLED Display from
https://grabcad.com/library/pantalla-oled-0-96-128x64-1

1.7 mm screws
https://www.mcmaster.com/products/screws/jis-steel-pan-head-screws/thread-size~m1-7/length~6-mm/?s=screws

2x3x3 mm spacer made in FreeCAD.

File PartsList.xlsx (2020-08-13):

Part | Number | Special Instructions | Link
TMP36 | 1 | Can be found cheaper on sparkfun | https://www.amazon.com/gp/product/B01GH32AQU/ref=ppx_od_dt_b_asin_title_s00?ie=UTF8&psc=1 | https://www.sparkfun.com/products/10988
OLED Screen | 1 | Must be 128x64, and support adafruit GFX | https://www.amazon.com/gp/product/B072Q2X2LL/ref=ppx_yo_dt_b_asin_title_o06_s00?ie=UTF8&psc=1
Battery | 1 | Solar charging, at least 10 Ah | https://www.amazon.com/gp/product/B085RX1L7W/ref=ppx_yo_dt_b_asin_title_o03_s00?ie=UTF8&psc=1
Digital Switch | 1 | Functionally equivalent to a transistor, just more user friendly | https://www.amazon.com/gp/product/B01I1J14MO/ref=ppx_yo_dt_b_asin_title_o05_s00?ie=UTF8&psc=1
Heating Pad | 1 | Sparkfun 5x10 cm heating pad | https://www.sparkfun.com/products/11288
Arduino Uno | 1 | Can buy these together | https://www.amazon.com/ELEGOO-Starter-Tutorial-Compatible-Official/dp/B01DGD2GAO?creativeASIN=B01DGD2GAO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
Buttons | 3
1k resistor | 4
Buzzer | 1 | Similar item can be found cheaper on sparkfun | https://www.amazon.com/gp/product/B075PT19J2/ref=ppx_yo_dt_b_asin_title_o01_s00?ie=UTF8&psc=1 | https://www.sparkfun.com/products/13940
Additionally:
Small box
Wire
USB cables

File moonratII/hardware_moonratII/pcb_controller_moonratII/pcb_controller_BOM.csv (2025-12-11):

Reference | Value | Datasheet | Footprint | Qty | DNP | Description
A1 | Arduino_UNO_R3 with uUSB and Cable | https://www.arduino.cc/en/Main/arduinoBoardUno | GeneralPurposeAlarmDevicePCB:Arduino_UNO_R3_NoMountingHoles3D_Text_Top_&_Bottom | 1 |  | Arduino UNO EXCEPT with micro USB
BZ1 | Buzzer_D12mm_H9.6mm_LS7.6mm | https://jlcpcb.com/partdetail/ss-SUN_12095_5VPA76/C360615 | PubInv_KiCad_PCB:Buzzer_12.2mm_9.7mm_7.62mm | 1
C1 | 0.1uF | ~ | Capacitor_SMD:C_0603_1608Metric_Pad1.08x0.95mm_HandSolder | 1 |  | 50V 100nF X7R ±10% 0603 Multilayer Ceramic Capacitors MLCC - SMD/SMT ROHS
Cable_MoldedFemale1 | Cable_02x06_Female | https://www.amazon.com/807-Connectors-Extension-Connector-Way-Socket/dp/B07SR28CG4/ref=sr_1_1?th=1 |  | 1 |  | 807 Square 6-Way Trailer Wiring Harness Connectors,6 pin Square Trailer Wire Extension for LED Brake Tailgate Light Bars,Hitch Light Trailer Wiring Harness Extension Connector (6 Way-Socket)
Cable_MoldedMale1 | Cable_02x06_Male | https://www.amazon.com/807-Connectors-Extension-Connector-Way-Socket/dp/B07SR2H8GH/ref=sr_1_1?th=1 |  | 1 |  | Cable_02x06_Male
Cable_Ribbon1 | Cable_02x05 | https://www.amazon.com/gp/product/B01DP13EDA/ref=ox_sc_saved_title_2?smid=A64W1E1ZZHST0&th=1 |  | 1 |  | Cable_02x05
D1 | Schottky 2A | SS210.pdf | Diode_SMD:D_SMB | 1
F1 | Polyfuse 6A | BSMD1812-300-16V.pdf | GeneralPurposeAlarmDevicePCB:Fuse_BSMD_1812 | 1 |  | 16V 3A 40A 6A 1812 Resettable Fuses ROHS
H1,H2,H3,H4,H5,H6 | MountingHole_Pad_3.5mm | ~ | GeneralPurposeAlarmDevicePCB:MountingHole_3.5mm_Pad_Via | 6 |  | MountingHole_Pad_3.5mm
J1 | Barrel_Jack_Switch_SMT | https://tensility.s3.amazonaws.com/uploads/pdffiles/54-00164.pdf | GeneralPurposeAlarmDevicePCB:BarrelJack_CLIFF_FC681465S_SMT_Horizontal | 1 |  | Power Barrel Connector Jack 2.10mm ID (0.083"), 5.50mm OD (0.217") Surface Mount, Right Angle
J2 | HS96L03W2C03_0.96_Oled | ~ | GeneralPurposeAlarmDevicePCB:OLED_HS96L03W2C03_0.96_WithNuts | 1 |  | OLED Displays Modules ROHS
J5,J10 | Conn_02x05_Odd_Even | C5665.pdf | Connector_IDC:IDC-Header_2x05_P2.54mm_Vertical | 2 |  | 2.54mm Straight 2x5P 5 Push - Pull 2.54mm 2 Plugin,P=2.54mm IDC Connectors ROHS
J6,J9 | Screw_Terminal_01x06 | https://jlcpcb.com/partdetail/Cixi_KefaElec-KF128_2_546P/C474924 | GeneralPurposeAlarmDevicePCB:1x6P 20A -40℃~+105℃ 300V Green 12~30 Straight pin 5.08mm 2.5 1 6 Plugin,P=5.08mm Screw terminal ROHS | 2 |  | 1x6P -40℃~+105℃ 8A 130V Green 18~26 Straight 2.54mm 1 1 6 Plugin,P=2.54mm Screw terminal ROHS
J11 | Screw_Terminal_01x02 | XY308-2.54-2P.pdf | TerminalBlock_TE-Connectivity:TerminalBlock_TE_282834-2_1x02_P2.54mm_Horizontal | 1 |  | 1x2P 6A 150V Green 18~26 Straight 2.54mm 1 1 2 Plugin,P=2.54mm Screw terminal ROHS
MF1,MF2,MF3 | CAP TACTILE ROUND IVORY 6.00mm Dia | https://omronfs.omron.com/en_US/ecb/products/pdf/en-b32.pdf | B32-2000 | 3 |  | Round Tactile Switch Cap Ivory Slip On, 6.00mm Dia x 5.50mm H
MF4,MF5,MF6,MF8 | SMD_round_nut_M2*4*5+1.5 | file:///Users/melanielaporte/Downloads/TH162050CTJ.pdf | TH162050CTJ | 4
MF7,MF9,MF10,MF11 | Steel Pan Head Phillips Screw M2 x 0.4 mm Thread, 6 mm Long | https://www.mcmaster.com/92005a023/ |  | 4
MF12 | 250V 3A Straight Square Pins 2.5mm 4P 6mm -40℃~+105℃ 3mm 2.54mm Plugin Black 1x4P Plugin,P=2.54mm Pin Headers ROHS | https://jlcpcb.com/partdetail/Xfcn-PZ254V_1104P/C2691448 | PZ254V-11-04P | 1
Q1 | IRF540N | http://www.irf.com/product-info/datasheets/data/irf540n.pdf | Package_TO_SOT_THT:TO-220-3_Horizontal_TabDown | 1 |  | 100V 33A 44mΩ@10V,16A 130W N Channel TO-220 MOSFETs ROHS
Q2 | BSS138 | https://www.onsemi.com/pub/Collateral/BSS138-D.PDF | Package_TO_SOT_SMD:SOT-23 | 1 |  | N-Channel Enhancement Mode Field Effect Transistor
R1,R7 | 1R | https://www.amazon.com/Momentary-Tactile-Through-Breadboard-Friendly/dp/B07WF76VHT/ | Resistor_SMD:R_0603_1608Metric_Pad0.98x0.95mm_HandSolder | 2 |  | 0.1W ±5% 1Ω 0603 Chip Resistor - Surface Mount ROHS
R3,R4,R5,R6,R9 | 1K | RMC06031K1%N.pdf | Resistor_SMD:R_0603_1608Metric_Pad0.98x0.95mm_HandSolder | 5 |  | 0.1W ±1% 1kΩ 0603 Chip Resistor - Surface Mount ROHS
R8 | Heater | https://www.sparkfun.com/products/11288 |  | 1 |  | Heating Pad - 5x10cm
R10 | 10K | RMC06031K1%N.pdf | Resistor_SMD:R_0603_1608Metric_Pad0.98x0.95mm_HandSolder | 1 |  | 100mW ±1% 10kΩ 0603 Chip Resistor - Surface Mount ROHS
SW1,SW2,SW3 | 6mm 2 Pin Tact NO Breadboard Friendly | http://www.apem.com/int/index.php?controller=attachment&id_attachment=1371 | GeneralPurposeAlarmDevicePCB:Switch_Tactile_THT_6x6mm | 3
U1 | TMP36GRTZ-REEL7 | https://www.analog.com/media/en/technical-documentation/data-sheets/TMP35_36_37.pdf | Package_TO_SOT_SMD:SOT-23-5 | 1

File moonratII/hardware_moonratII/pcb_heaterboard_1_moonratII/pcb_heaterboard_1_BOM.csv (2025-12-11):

Reference | Value | Datasheet | Footprint | Qty | DNP
C1 | 0.1uF | ~ | Capacitor_SMD:C_0603_1608Metric_Pad1.08x0.95mm_HandSolder | 1
J7 | Screw_Terminal_01x03 | ~ | GeneralPurposeAlarmDevicePCB:GeneralPurposeAlarmDevicePCB_282834-3_1x03_P2.54mm_Horizontal | 1
J9 | Screw_Terminal_01x06 | https://jlcpcb.com/partdetail/Cixi_KefaElec-KF128_2_546P/C474924 | GeneralPurposeAlarmDevicePCB:GeneralPurposeAlarmDevicePCB_282834-6_1x02_p254mm_Horizontal | 1
J10 | Conn_02x05_Odd_Even | C5665.pdf | Connector_IDC:IDC-Header_2x05_P2.54mm_Vertical | 1
J11,J12 | Screw_Terminal_01x02 | XY308-2.54-2P.pdf | GeneralPurposeAlarmDevicePCB:GeneralPurposeAlarmDevicePCB_282834-2_1x02_P2.54mm_Horizontal | 2
R2,R5 | Heating Pad - 5x10cm | https://www.sparkfun.com/products/11288 |  | 2
R7 | 4K7 | https://jlcpcb.com/api/file/downloadByFileSystemAccessId/8588894533715169280 | Resistor_SMD:R_0603_1608Metric_Pad0.98x0.95mm_HandSolder | 1
TP1 | +5P | ~ | TestPoint:TestPoint_Loop_D2.54mm_Drill1.5mm_Beaded | 1
TP2 | TP_GND | ~ | TestPoint:TestPoint_Loop_D2.54mm_Drill1.5mm_Beaded | 1
TP3 | TempOut_IB | ~ | TestPoint:TestPoint_Loop_D2.54mm_Drill1.5mm_Beaded | 1
TP4 | HeaterDrive_IB | ~ | TestPoint:TestPoint_Loop_D2.54mm_Drill1.5mm_Beaded | 1
TP5 | VCCQ | ~ | TestPoint:TestPoint_Loop_D2.54mm_Drill1.5mm_Beaded | 1

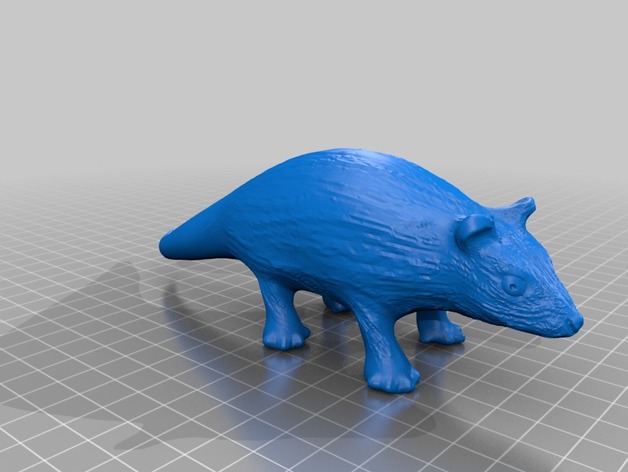
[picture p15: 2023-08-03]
moonratII/hardware_moonratII/pcb_controller_moonratII/parts/Opossum_2978135/images/Opossum.jpg

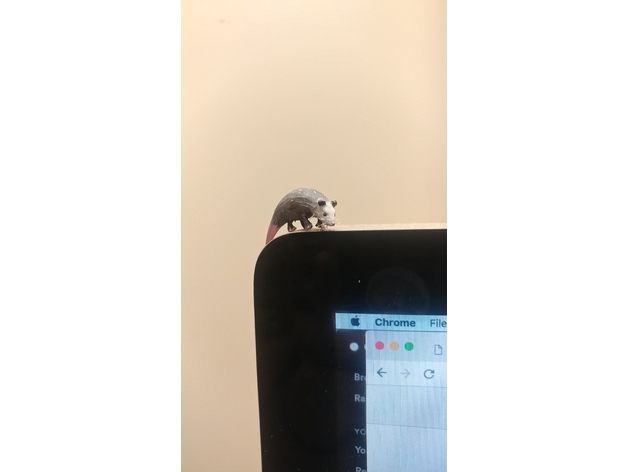
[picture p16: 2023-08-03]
moonratII/hardware_moonratII/pcb_controller_moonratII/parts/Opossum_2978135/images/260d312acec6ecbcb5101b8ec56546b6.jpg

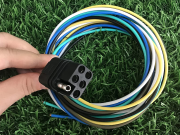
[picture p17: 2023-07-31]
moonratII/hardware_moonratII/pcb_controller_moonratII/parts/DELETE Cable_MaleGND_2x3.png

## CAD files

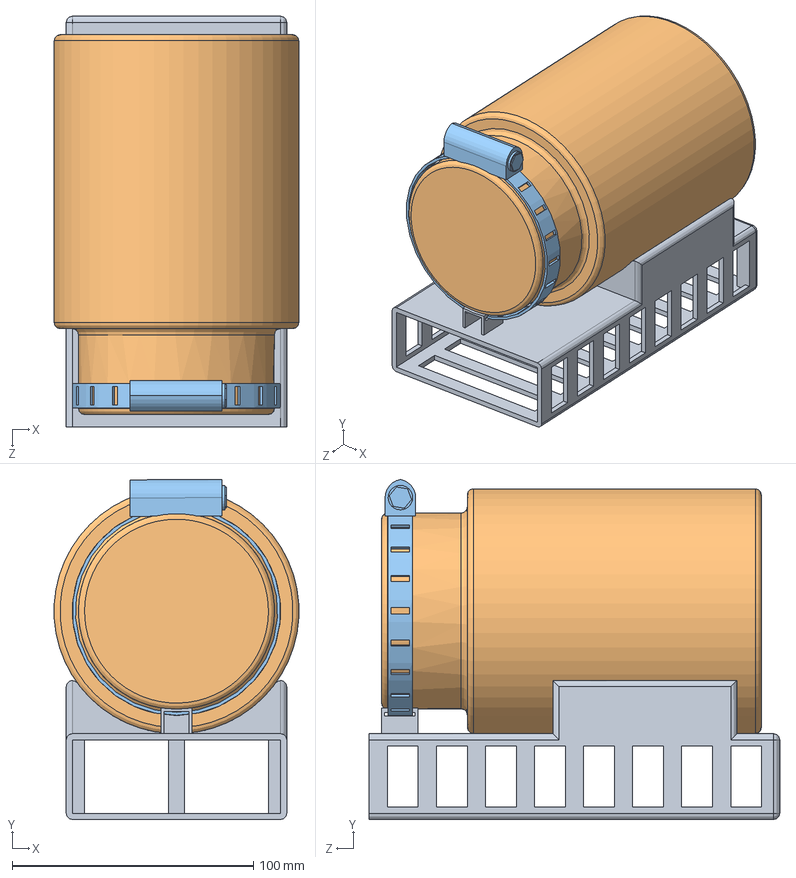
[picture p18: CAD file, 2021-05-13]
moonrat/3D_design/assembly_solidworks.SLDASM
101.4 x 140.9 x 170.2 mm
final_base3
thermos2
hose_clamp

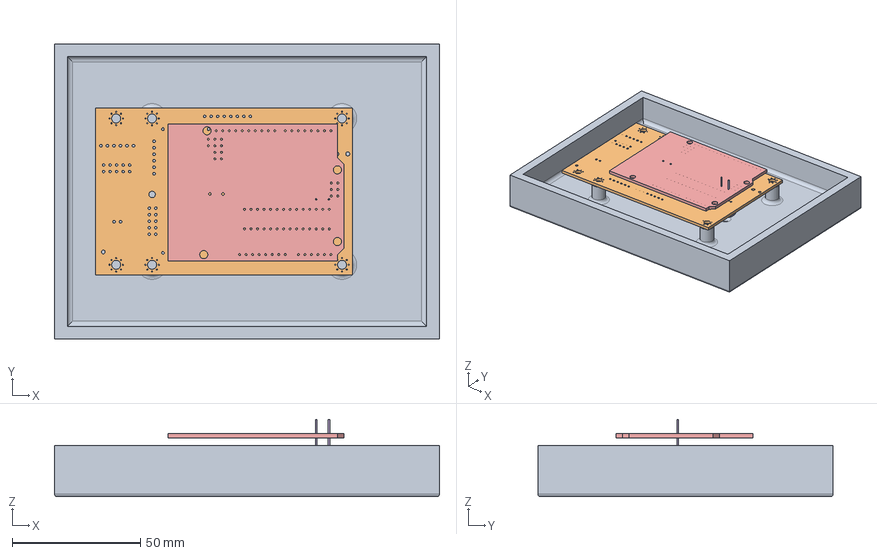
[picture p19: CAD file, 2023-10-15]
moonratII/enclosure_mooonratII/assembly_moonratII.FCStd
150.0 x 115.0 x 30.1 mm
enclosure_moonratii_Top_Body_moonratii_Top_001
Assembly 2_Pcb_836_001
Assembly 2_SW2_SW_PUSH_6mm_053ba29955b0_001
Assembly 2_SW3_SW_PUSH_6mm_c7033e5b1802_001
Assembly 2_unoboard blue_001
Assembly 2_BZ1_Buzzer_TDK_PS1240P02BT_D122mm_H65mm_76327d02d399_001

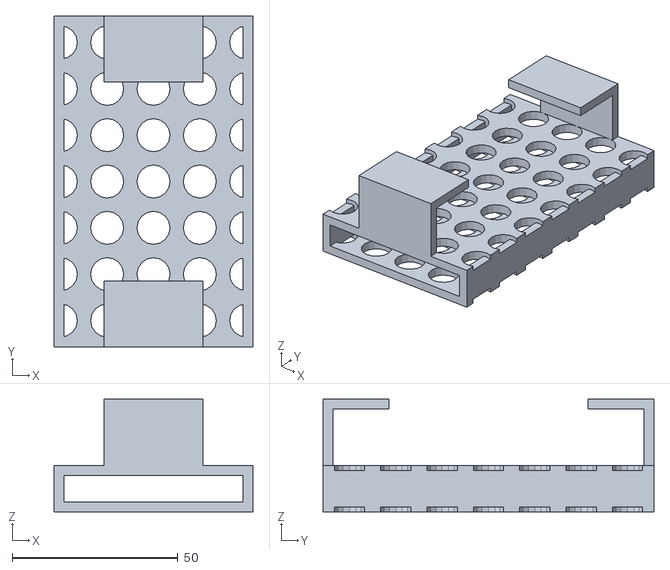
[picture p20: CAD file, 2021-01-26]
moonrat/ThermosCassette.stl
60.0 x 100.0 x 34.0

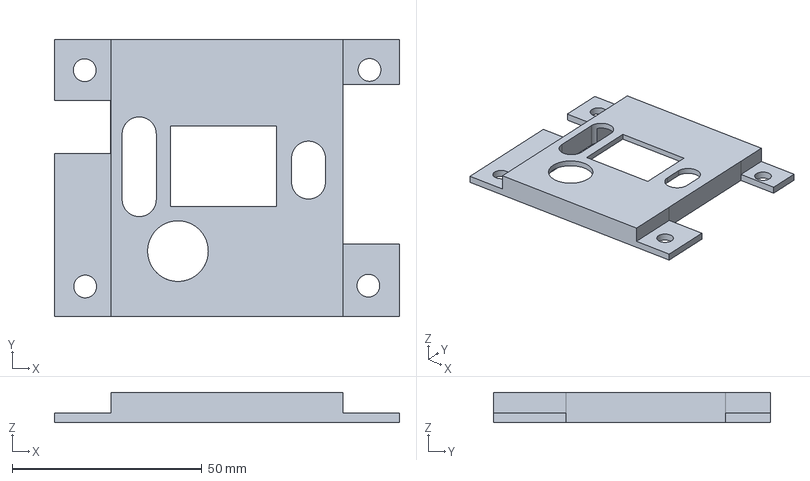
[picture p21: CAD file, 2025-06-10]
moonratII/enclosure_mooonratII/cover.FCStd
91.0 x 73.0 x 8.00 mm

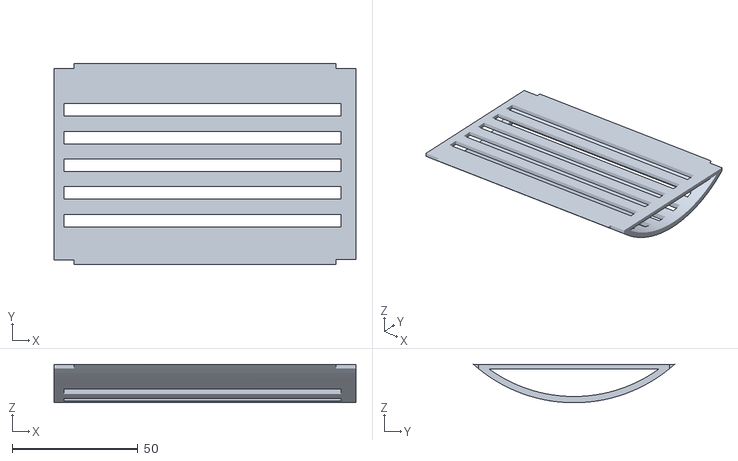
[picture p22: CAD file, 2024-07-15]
moonratII/hardware_moonratII/culture_holders/base_petri-BodyPocket002.stl
120.0 x 80.0 x 15.3

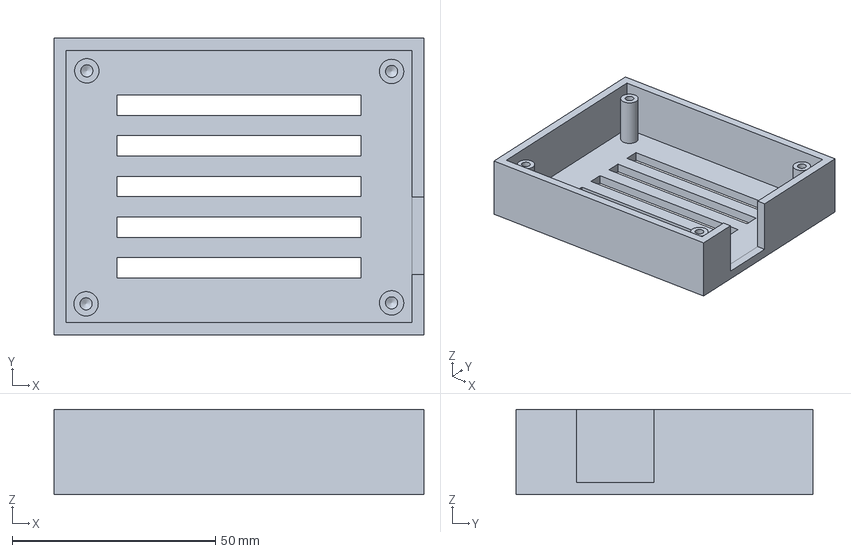
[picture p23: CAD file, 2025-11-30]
moonratII/hardware_moonratII/enclosure_moonratII/controller_base.FCStd
91.0 x 73.0 x 21.0 mm

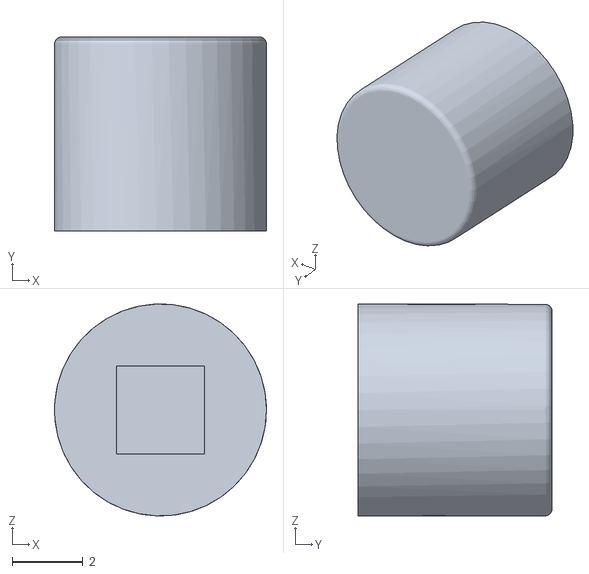
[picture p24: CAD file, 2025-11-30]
moonratII/hardware_moonratII/enclosure_moonratII/Parts/switch_cap_b32-2010.stl
6.00 x 5.50 x 6.00

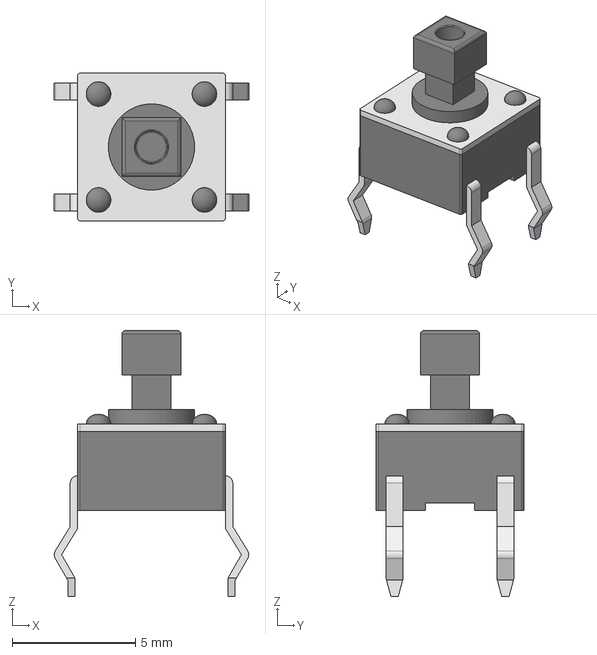
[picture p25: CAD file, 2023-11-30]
moonratII/hardware_moonratII/pcb_controller_moonratII/parts/TS6-THT-SQ.step
7.90 x 6.00 x 10.8 mm

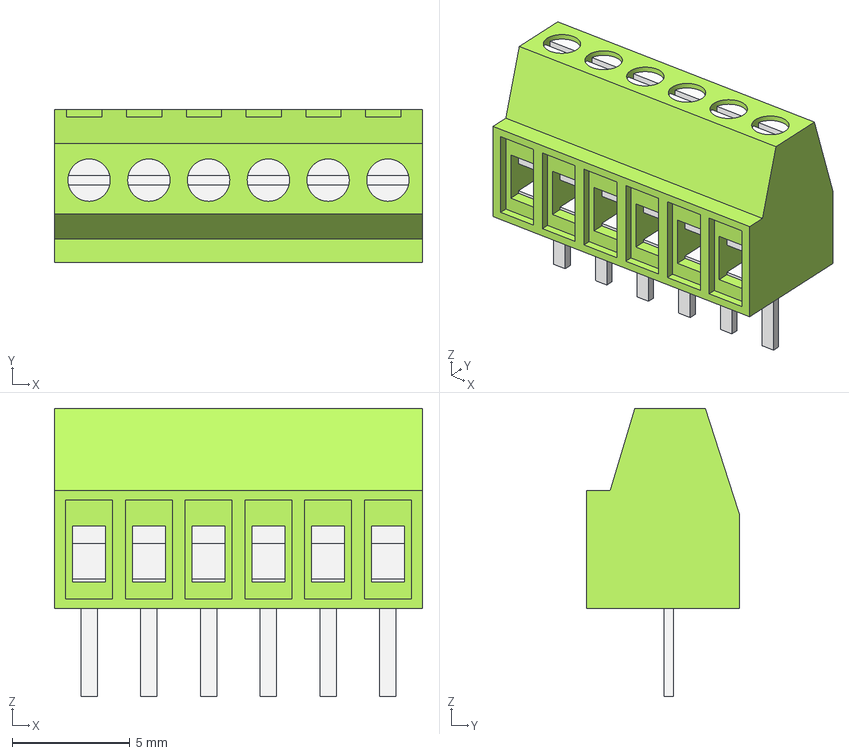
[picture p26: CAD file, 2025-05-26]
moonratII/hardware_moonratII/pcb_heaterboard_1_moonratII/parts/KF128 2.54mm/KF128-2.54-6P.step
15.6 x 6.50 x 12.3 mm
Housing
PlasticBody

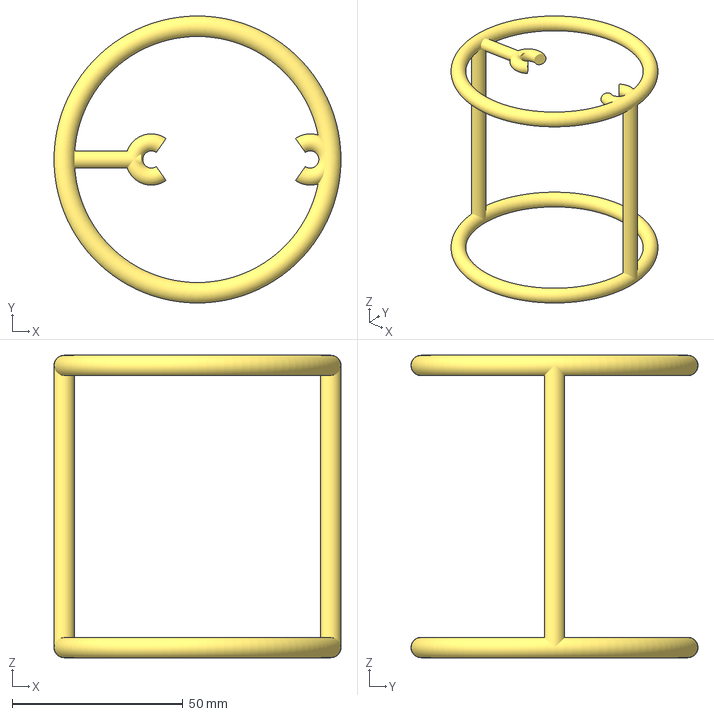
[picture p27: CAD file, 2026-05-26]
moonratII/hardware_moonratII/tempSensorClip/tempSensorClip.3mf
84.0 x 84.0 x 88.5 mm

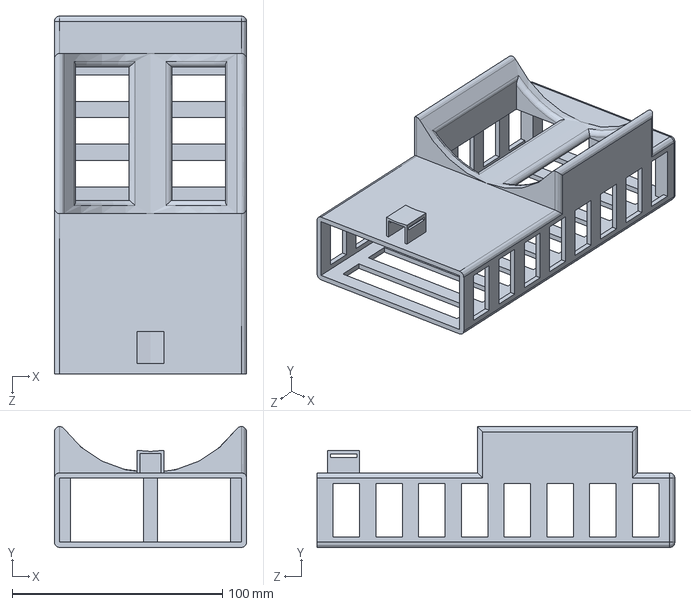
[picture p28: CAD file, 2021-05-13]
moonrat/3D_design/base_holder_solidworks.SLDPRT
91.4 x 57.6 x 170.2 mm

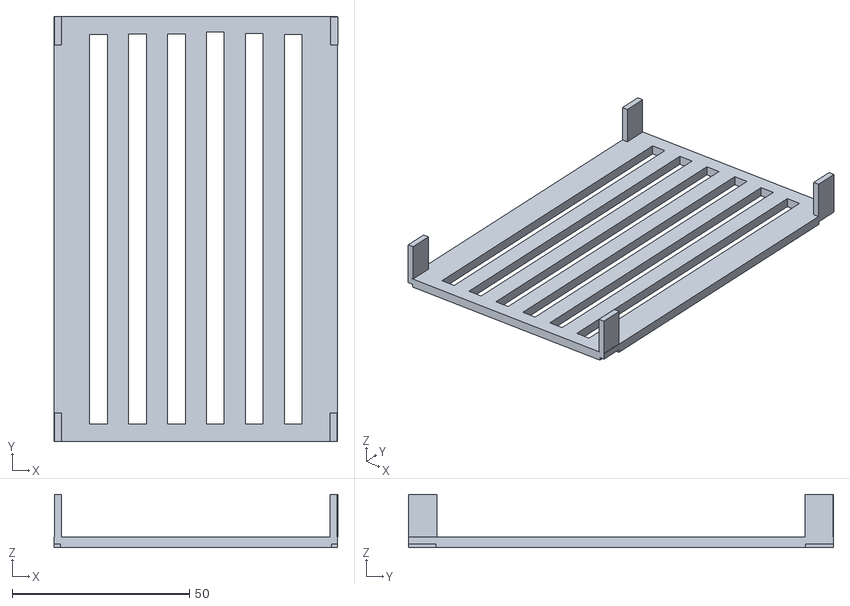
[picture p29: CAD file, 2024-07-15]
moonratII/hardware_moonratII/culture_holders/rack_petri-BodyPad001.stl
80.0 x 120.0 x 15.0

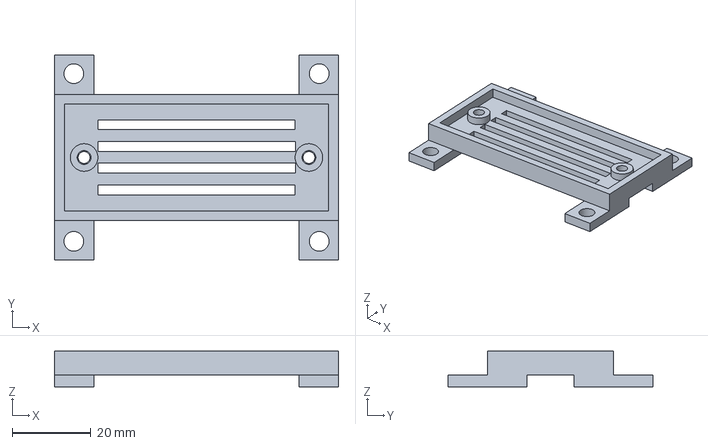
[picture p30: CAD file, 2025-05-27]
moonratII/hardware_moonratII/enclosure_moonratII/heater_platform.FCStd
72.0 x 52.0 x 9.00 mm

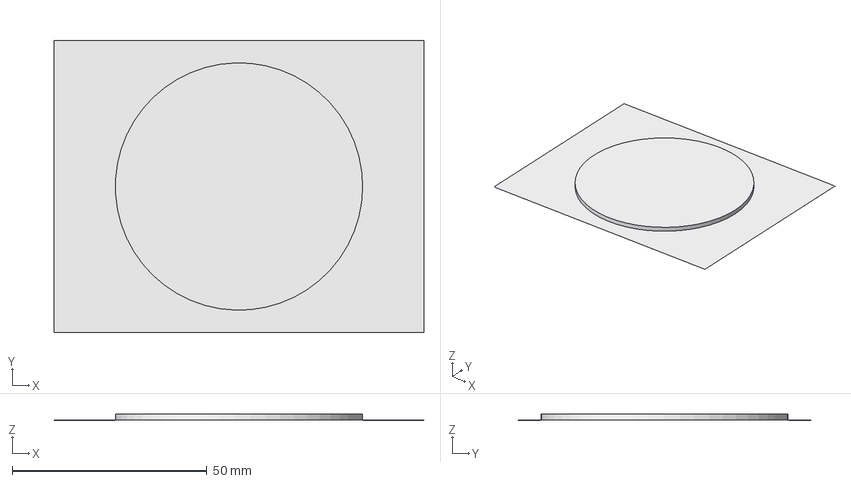
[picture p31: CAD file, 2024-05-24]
moonratII/hardware_moonratII/enclosure_moonratII/Parts/Petrifilm_Ecoli.FCStd
95.0 x 75.0 x 1.59 mm

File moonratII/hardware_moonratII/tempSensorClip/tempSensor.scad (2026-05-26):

// Simple torus in OpenSCAD

minor_radius = 3;    // Radius of the tube
major_radius = 84/2 - minor_radius;   // Distance from center to tube center
chamber_height = 6.5*25.4; // approximately 6.25" high
shaft_radius = 3;
chamber_half_height = chamber_height/2;
harp_major_radius_interior = 5/2;

module chamberFit() {
    rotate_extrude($fn=100)
    translate([major_radius, 0, 0])
    circle(r = minor_radius, $fn=60);
}

module harp() {
    harp_minor_radius = 5/2;
    harp_major_radius = harp_minor_radius+harp_major_radius_interior;
    gap_angle = 110;
    translate([major_radius-shaft_radius*2,0,chamber_half_height])
    rotate([0,0,180+gap_angle/2])
    rotate_extrude($fn=100,angle = 360-gap_angle)
    translate([harp_major_radius, 0, 0])
    circle(r = harp_minor_radius, $fn=60);
}

module tempSensorHolder() {
    translate([0,0,chamber_half_height])
        chamberFit();
    chamberFit();
    // connecting shaft
    translate([major_radius,0,0])
        cylinder(r=shaft_radius,h=chamber_half_height, $fn=60);
    translate([-major_radius,0,0])
        cylinder(r=shaft_radius,h=chamber_half_height, $fn=60);
    // add holding clip
    harp();
    // add additional clip more toward the center
    clip_shaft_length = major_radius/2;
    rotate([0,0,180])
    translate([-clip_shaft_length,0,0])
        harp();
    // clip holding shaft
    translate([-major_radius+clip_shaft_length/2 + minor_radius,0,chamber_half_height])
    rotate([0,90,0])
    cylinder(h = clip_shaft_length,r = harp_major_radius_interior, center = true,$fn=100); 
}

tempSensorHolder();

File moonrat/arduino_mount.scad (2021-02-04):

//case bottom dimensions
arduino_width=80;
arduino_length=60;
case_height=30;

slope_angle=10;

box_thickness=3;
port_width=30;
port_length=15;
port_height=60;
cap_diameter=30;
mount_pos=(cap_diameter/2)-3;

//case top dimensions
top_height=10;

top_length= arduino_length/cos(slope_angle);


lengthOLED=25;

widthOLED=15;
depthholes=top_height+10;

dbuttons=5;
buttonspace=15;

dOLED_to_butt=-18;

length2hole=40;

height22=16;
width2hole= 30;
heighthole=8;
//screws
dscrews=2;



//Creates screw mounts
module screw_mount(mount_height){
    difference(){
        cube(size=[dscrews+2,dscrews+2,mount_height], center=true);
        cylinder(mount_height+1,dscrews/2,dscrews/2,center=true);
    }
}

//creates cube to cut the box bottom at an angle
module rotated_cube(angle){
    rotate([angle, 0, 0]){
        cube(size=[arduino_width+10,arduino_length+50,case_height+1], center=true);
    }
}

//create bottom
module  createCaseBottom() {
    difference(){
    union(){
        difference(){
            cube(size=[arduino_width,arduino_length,case_height], center=true);
        
            
       
                cube(size=[arduino_width-(2*box_thickness),arduino_length-(2*box_thickness),case_height-(2*box_thickness)], center=true);
        
                cube(size=[port_width,port_length,port_height],center=true);
        
                //mounting screws
                translate([0,mount_pos,0]){
                    cylinder(port_height,dscrews/2,dscrews/2,center=true);
        
                    }
                translate([0,-mount_pos,0]){
                    cylinder(port_height,dscrews/2,dscrews/2,center=true);
        
                }
            }
            //screw mounts
            translate([((arduino_width/2)-(dscrews+2)/2)-box_thickness,((arduino_length/2)-(dscrews+2)/2)-box_thickness,0]){
            screw_mount(case_height);
            }
            translate([-(((arduino_width/2)-(dscrews+2)/2)-box_thickness),((arduino_length/2)-(dscrews+2)/2)-box_thickness,0]){
            screw_mount(case_height);
            }
            translate([-(((arduino_width/2)-(dscrews+2)/2)-box_thickness),-(((arduino_length/2)-(dscrews+2)/2)-box_thickness),0]){
            screw_mount(case_height);
            }
            translate([(((arduino_width/2)-(dscrews+2)/2)-box_thickness),-(((arduino_length/2)-(dscrews+2)/2)-box_thickness),0]){
            screw_mount(case_height);
            }
        }
        translate([0,0,20])
             rotated_cube(slope_angle);
    }
        
}


        
//creates hole for the screw       
module screw_hole(d_of_screw){
     cylinder(depthholes,(d_of_screw)/2,(d_of_screw)/2,center=true);
        
     translate([0,0,2]){
           cylinder(1.5,(d_of_screw+2)/2,(d_of_screw+2)/2,center=true);
     }
     //Todo, Add screw thread
}


module Case_top(){
    difference(){
        cube(size=[arduino_width,top_length,box_thickness+2], center=true);
        
        translate([0,0,0])
                cube(size=[lengthOLED,widthOLED,depthholes], center=true);
     
    //buttons
        translate([0,dOLED_to_butt,0]){
          cylinder(depthholes,dbuttons/2,dbuttons/2,center=true);
        }
        translate([buttonspace,dOLED_to_butt,0]){
          cylinder(depthholes,dbuttons/2,dbuttons/2,center=true);
        }
        
        translate([-buttonspace,dOLED_to_butt,0]){
          cylinder(depthholes,dbuttons/2,dbuttons/2,center=true);
        }
     //OLED screws
         translate([(lengthOLED/2)+2,(widthOLED/2)+2,0]){
          screw_hole(dscrews);
        
        }
        translate([-((lengthOLED/2)+2),(widthOLED/2)+2,0]){
          screw_hole(dscrews);
        
        }
        translate([-((lengthOLED/2)+2),-((widthOLED/2)+2),0]){
          screw_hole(dscrews);
        
        }
        translate([((lengthOLED/2)+2),-((widthOLED/2)+2),0]){
          screw_hole(dscrews);
        
        }
         translate([((arduino_width/2)-(dscrews+2)/2)-box_thickness,((arduino_length/2)-(dscrews+2)/2)-box_thickness,0]){
          screw_hole(dscrews);
        }
       
         translate([-(((arduino_width/2)-(dscrews+2)/2)-box_thickness),((arduino_length/2)-(dscrews+2)/2)-box_thickness,0]){
          screw_hole(dscrews);
        }
        
         translate([-(((arduino_width/2)-(dscrews+2)/2)-box_thickness),-(((arduino_length/2)-(dscrews+2)/2)-box_thickness),0]){
          screw_hole(dscrews);
        }
        
         translate([((arduino_width/2)-(dscrews+2)/2)-box_thickness,-(((arduino_length/2)-(dscrews+2)/2)-box_thickness),0]){
          screw_hole(dscrews);
        }
        
    }
        

}



translate([150,0,0])
//rotate([slope_angle, 0, 0]){
 Case_top();
//}
translate([0,0,0])
 createCaseBottom();

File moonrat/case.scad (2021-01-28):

//    Copyright 2021, Robert L. Read and Halimat Farayola
//    This program is free software: you can redistribute it and/or modify
//    it under the terms of the GNU General Public License as published by
//    the Free Software Foundation, either version 3 of the License, or
//    (at your option) any later version.
//
//    This program is distributed in the hope that it will be useful,
//    but WITHOUT ANY WARRANTY; without even the implied warranty of
//    MERCHANTABILITY or FITNESS FOR A PARTICULAR PURPOSE.  See the
//    GNU General Public License for more details.
//
//    You should have received a copy of the GNU General Public License
//    along with this program.  If not, see <https://www.gnu.org/licenses/>.




// This is a quick customizable way to make an array of holes of any size in a cylindrical plate - specifically for use in a Buchner funnel.



// TODO:
// A) The module for the electronics needs to be designed so that it 
// can be fitted onto or mates with the heating chamber design in such 
// a way that the electronics can be inserted. - 2 hours
// B) We need to choose a Bill of Materials for standoffs and design the
// holes for that - 2 hours
// C) We need to choose the hinge and get the precise dimensions. - 2 hours
// D) We need to decide on latching hardware and make sure it is mountable. - 2 hours
// E) We need to design a platform to support the materials - 2 hours
// F) We need to add a pipette holder - 2 hours
// G) We need to design some sort of battery attachment underneath - 2 hours
// H) We need to decide the dimensions of the inner chamber carefull - 1 hour

// I think we can define a basic "interface" the electronics module which will
// be a standard physical mount. This will allow us to use a standard inteface
// with a variety of boxes. Possibly this can be done with pillow mounts.

// MEDIA DIMENSIONS
// Petrifilms and other media vary in size.
// https://www.3m.com/3M/en_US/company-us/all-3m-products/~/ECOLICT-3M-Petrifilm-E-coli-Coliform-Count-Plates/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
// However, E. coli Petrifilms are precisely:
ecoli_pf_width_mm = 74;
ecoli_pf_length_mm = 100+2;
ecoli_pf_height_mm = 1; // This is not a precise measumrent, but close.
// Note that Petfilims are allows to be stacked no more than 20 high.
ecoli_stack_number = 20;
// I suggest that we base the interior dimentions on this.

heatingClothGap=5;
plateWidth=3;
cassetteHeight=heatingClothGap+2*plateWidth;// 
throatDiameter=60;
backWallHeight=20;

include <Perforated_plate.scad>

// Note this site:
// https://www.shoppopdisplays.com/CS004/clear-acrylic-box-with-hasp-lock-hinged-lid-custom-size.html
// sells custom boxes with hasps and hinges which could be acceptable for the
// out box if we bolt something on; the other parts we can 3D print

include <rcube.scad>

// These are for the inner heat chanber dimensions
// I'm going to add some padding so the chamber won't be to cramped
hc_margin_mm = 10;
hc_len = ecoli_pf_length_mm + hc_margin_mm;
hc_wid = ecoli_pf_width_mm + hc_margin_mm;
// NOTE : This currently does not take account of the tray and heatin pad height.
hc_hgt = ecoli_stack_number*ecoli_pf_height_mm+hc_margin_mm;

// These are the outer dimensions; they could be 
// computed from the hc dimensions
hc_ins_width = 50; // an empty insulation width

hc_olen = hc_len+hc_ins_width;
hc_owid = hc_wid+hc_ins_width;
hc_ohgt = hc_hgt+hc_ins_width;
inner_shell_width = 3;
outer_shell_width = 3;
outer_shell_radius = 3;

// hinge specifcation (assume two holes)
hinge_hole_distance = 10;
hinge_hole_radius = 1.5; // for the screw shaft, not the head!
hinge_hole_distance_from_pin = 5;
hinge_leaf_width = 5; // for "recessing"
hinge_leaf_length = hinge_hole_distance*3; // length along hinge axis
hinge_leaf_thickness = 2;
hinge_screw_length = 15;
hinge_screw_barrel_radius = hinge_hole_radius+3;


// flange specification

flange_thickness = 10;
flange_length = hinge_leaf_width*3;

// Comment these
length = 86;
width= 46;

// outside box dimension
height = 19;
length2=30;
lengtho2=44;
width2=40;
lengthtwo=80;

// Possibly height of cutting tool
height2=18;


height20 = 19;


height22=16;
lengthhole=25;
length2hole=40;
widthhole=15;
width2hole= 30;
heighthole=8;
dhole=5;
depthhole=8;

// Create basic shell width
shellWidth = 3;
dividerFromTop = 30;

// Here we create two open boxes; these should be printed as two distinct parts!
module  createHeatChamber(ilen,iwid,ihgt,olen,owid,ohgt,ish,osh,fl,ft) {
    // outer box, which has "lips" cut off for lid
    difference() {
        union() {
        open_box(olen,owid,ohgt,osh,outer_shell_radius,0);
        createHingeFlange(olen,owid,ohgt,fl,ft);
        }
        // here I need to cut out the edges
        translate([-osh,0,ohgt/2])
        cube(size=[olen+osh*2, owid-osh*2, osh*2],center=true);
    }

}
// This is printed separately!!!
module innerChamber(ilen,iwid,ihgt,ish) {
    color([1,0,0])
    open_box(ilen,iwid,ihgt,ish,0,0);
}

module hingeleaf(olen,owid,ohgt,fsh) {
        color([1,0.5,0.5])
        scale([2,2,2])
        rcube([hinge_leaf_width*2,hinge_leaf_length,hinge_leaf_thickness],1);
}
// LID -- This needs to have a place for the latch hardware
module lid(olen,owid,ohgt,osh,fsh) {
    difference() {
        union() {
        difference() {
            union() {
                translate([0,0,ohgt/2-osh/2])
                cube(size=[olen,owid-osh*2,osh],center=true);
            } 
            translate([olen/2+-hinge_hole_distance_from_pin,0,ohgt/2 - hinge_screw_length/2]) 
             { 
                translate([0,hinge_hole_distance/2,0])     
                cylinder(hinge_screw_length*2,hinge_screw_barrel_radius,hinge_screw_barrel_radius,true);
                translate([0,-hinge_hole_distance/2,0])
                cylinder(hinge_screw_length*2,hinge_screw_barrel_radius,hinge_screw_barrel_radius,true);
             }                   
    
        }
        translate([olen/2+-hinge_hole_distance_from_pin,0,ohgt/2 - hinge_screw_length/2]) 
        dualBarrels();
        }
        // now we cut away the hinge_leaf....
        // we first translate it an then rotate it....
        translate([olen/2,0,ohgt/2 - hinge_leaf_thickness/2]) 
        rotate([0,180,0])
        hingeleaf(olen,owid,ohgt,fsh);
    }
}

module screwBarrel(len,od,id) {
    difference() {
        cylinder(len,od,od,true, $fs = 0.01);
        cylinder(len*2,id,id,true,  $fs = 0.01);
    }
}
module dualBarrels() {
    // now we create two "barrels" to receive the screws (with holes in those!)
    color([0,0,1])
    translate([0,hinge_hole_distance/2,0])
    screwBarrel(hinge_screw_length,hinge_screw_barrel_radius,hinge_hole_radius);
    color([0,0,1])
    translate([0,-hinge_hole_distance/2,0])
    screwBarrel(hinge_screw_length,hinge_screw_barrel_radius,hinge_hole_radius);
}

// Now we create a "flange" which is a place to bolt one half of the hinge.
// fsh is the "flange thickness"
module createHingeFlange(olen,owid,ohgt,flen,fsh) {
    
    // We want to add two "barrels" for the screws, but first we use that 
    // tool to cut out the holes!!
    difference() {
        union() {
            difference() {
                    translate([olen/2+flen/2,0,ohgt/2 - fsh/2])
                    cube(size=[flen, owid, fsh],center=true);
                    translate([olen/2+hinge_hole_distance_from_pin,0,ohgt/2 - hinge_screw_length/2]) 
                // This cuts the screw holes
                    {    
                        translate([0,hinge_hole_distance/2,0])     
                        cylinder(hinge_screw_length*2,hinge_screw_barrel_radius,hinge_screw_barrel_radius,true);
                        translate([0,-hinge_hole_distance/2,0])
                        cylinder(hinge_screw_length*2,hinge_screw_barrel_radius,hinge_screw_barrel_radius,true);
                    }      
                }

        translate([olen/2+hinge_hole_distance_from_pin,0,ohgt/2 - hinge_screw_length/2]) 
        dualBarrels();
            }
               // now we cut away a "recession" for the hinge...
            // this is mostly to make it easier to see how pieces fit together!!!
            // this is mostly to make it easier to see how pieces fit together!!!
        translate([olen/2,0,ohgt/2 - hinge_leaf_thickness/2]) 
        hingeleaf(olen,owid,ohgt,flen,fsh);
    }

}


module  open_box(olen,owid,ohgt,sh, or=4,ir =2) {   
    // inside
    difference() {
        difference() {             
                rcube([olen, owid, ohgt],or, center=true); 
                rcube([olen-2*sh, owid-2*sh, ohgt-2*sh],ir,center=true); 
        }
        // This makes the box "open"
        translate([0,0,sh])
        cube(size=[olen-2*sh, owid-2*sh, sh + ohgt-2*sh],center=true); 
    }
// Now we will cut the top out, which makes this slightly assymetric...    
}
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

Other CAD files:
moonratII/hardware_moonratII/pcb_controller_moonratII/parts/Omron/b32-2010.stp
moonratII/hardware_moonratII/pcb_heaterboard_1_moonratII/parts/Omron/b32-2010.stp
moonratII/hardware_moonratII/pcb_controller_moonratII/parts/Omron/B3F-6050--3DModel-STEP-273799.STEP
moonrat/Perforated_plate.scad
legacy/moonrat/Perforated_plate.scad
legacy/moonrat/rcube.scad
moonrat/rcube.scad
moonratII/hardware_moonratII/enclosure_moonratII/controller_base.stl
moonratII/hardware_moonratII/pcb_controller_moonratII/parts/92005A023_Steel Pan Head Phillips Screw.STEP
moonratII/hardware_moonratII/pcb_controller_moonratII/parts/BarrelJackSMD v3.step
moonratII/hardware_moonratII/pcb_controller_moonratII/parts/KF128-2.54-2P.step
moonratII/hardware_moonratII/pcb_controller_moonratII/parts/KF128-2.54-6P.step
moonratII/hardware_moonratII/pcb_controller_moonratII/parts/Pantalla OLED 0.96'' 128x64.stp
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

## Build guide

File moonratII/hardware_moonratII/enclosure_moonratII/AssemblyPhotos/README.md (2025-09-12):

# Assembly of An Enclosure for the MoonratII Controller

Designed in Free CAD V0.19 - 1.0
Designed by Sylvia, Melanie Laporte, (Forrest) Lee Erickson

## Image Gallery - Current FreeCAD Assembly Designs
|A |B |C |
| --- | --- | --- |
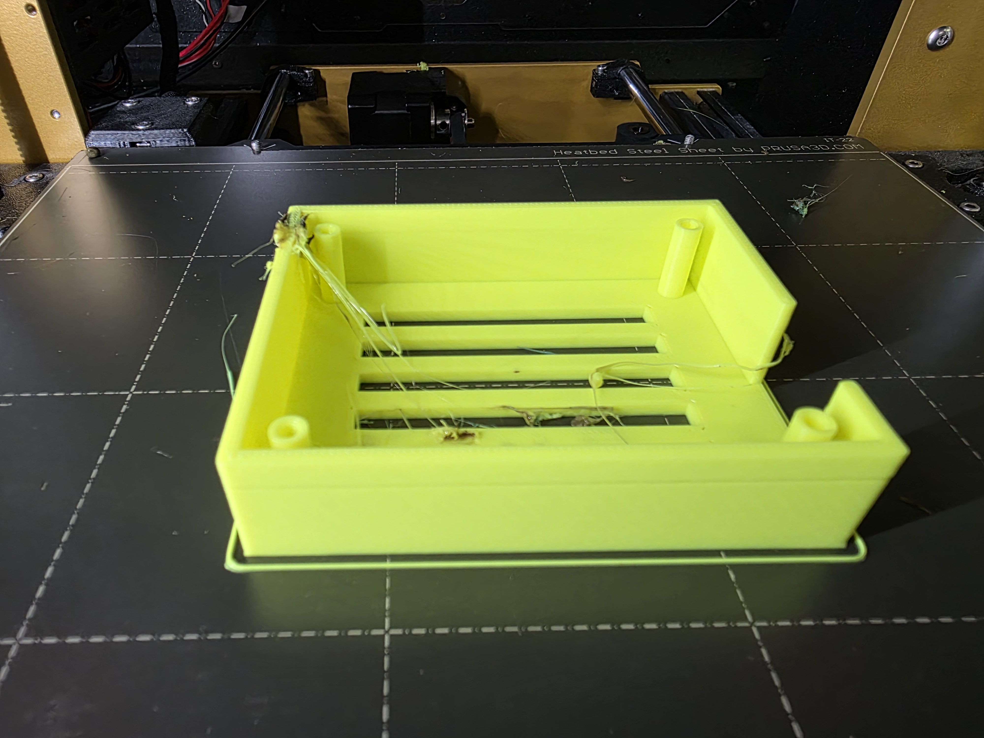
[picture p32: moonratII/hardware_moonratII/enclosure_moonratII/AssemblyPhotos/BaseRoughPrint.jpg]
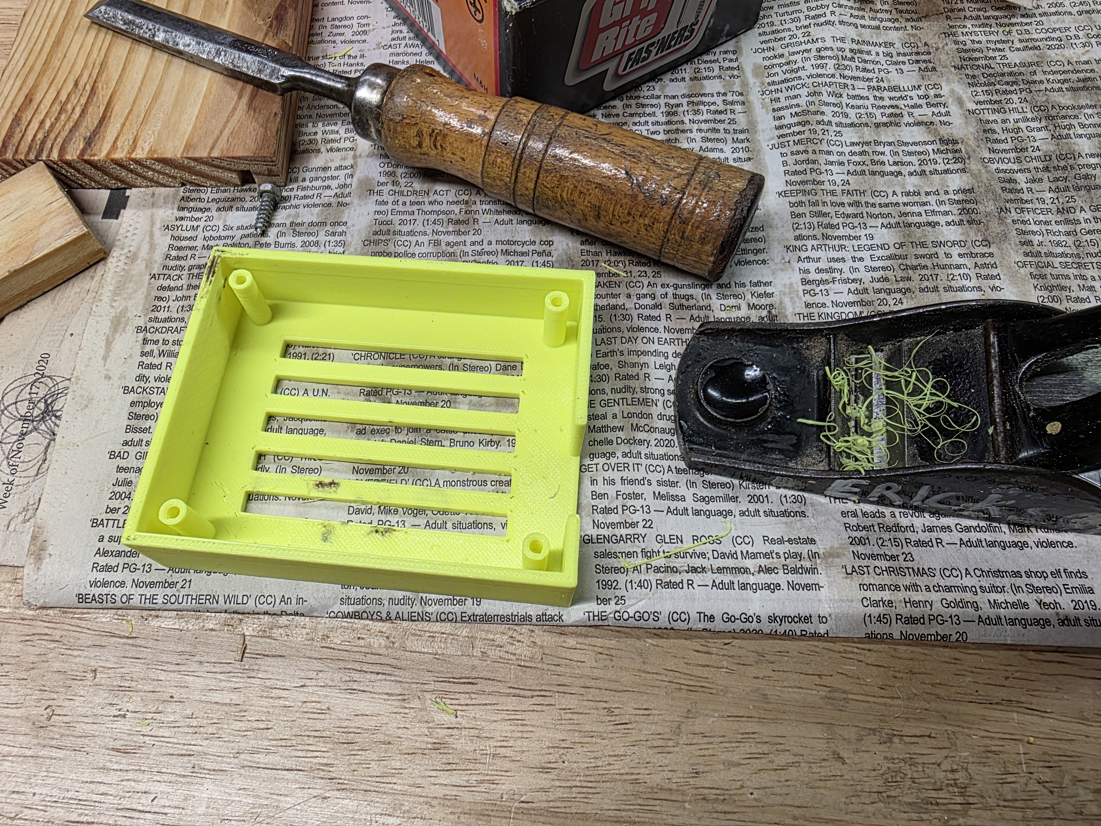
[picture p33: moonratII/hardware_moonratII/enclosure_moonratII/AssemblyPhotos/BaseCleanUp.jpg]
|  <br>Base rough print.|  <br>Base clean up with chisel| NA|
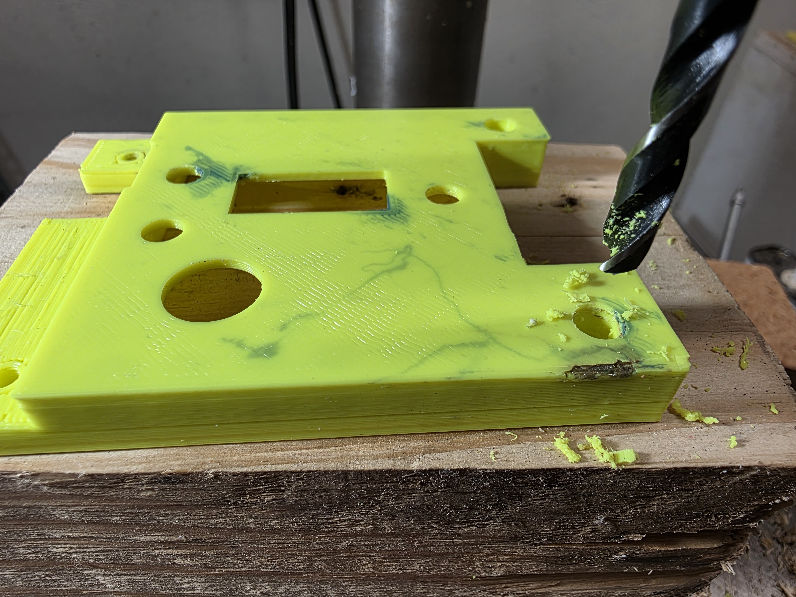
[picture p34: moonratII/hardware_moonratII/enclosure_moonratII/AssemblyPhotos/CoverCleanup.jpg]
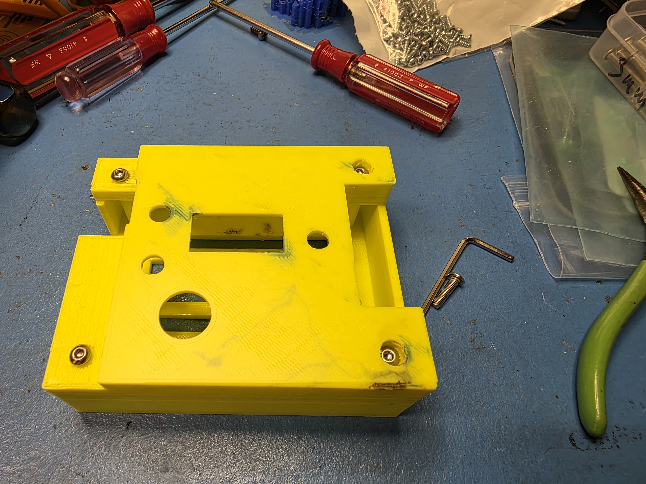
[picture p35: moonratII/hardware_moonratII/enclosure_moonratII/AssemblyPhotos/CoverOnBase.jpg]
| <br>Cover clean up.|  <br>Cover on base. No PWAs.| NA|
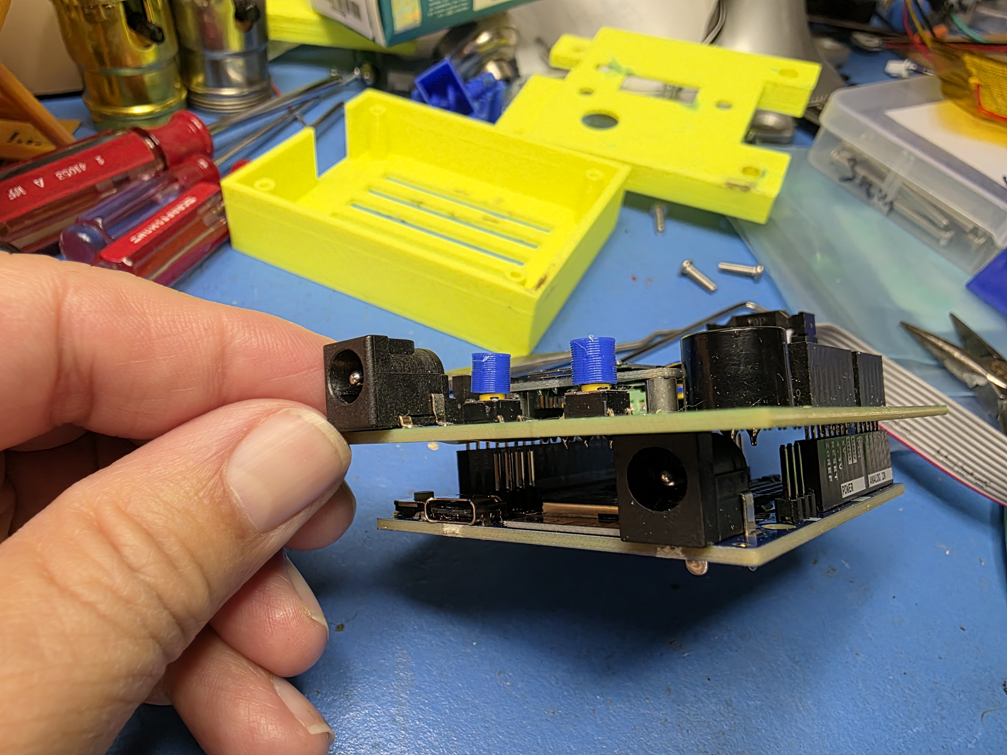
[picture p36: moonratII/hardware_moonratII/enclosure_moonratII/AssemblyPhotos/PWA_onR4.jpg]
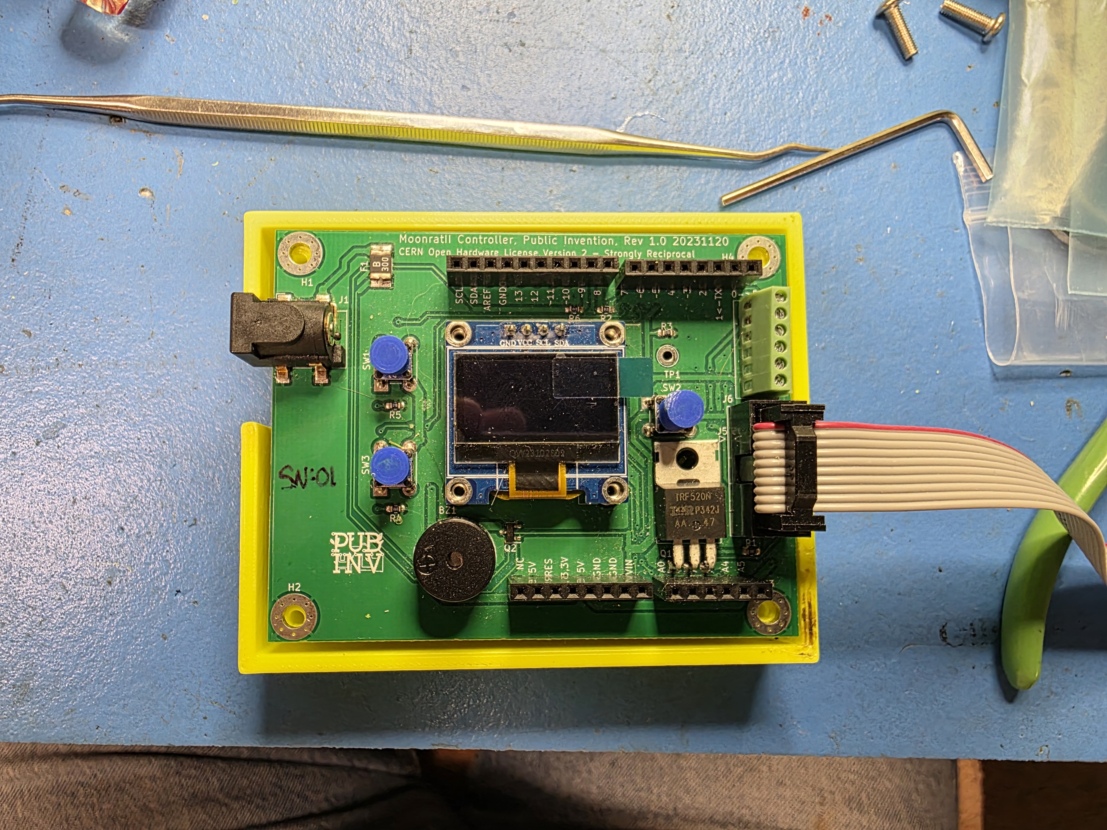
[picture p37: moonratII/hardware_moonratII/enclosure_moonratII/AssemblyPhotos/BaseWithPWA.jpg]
| <br>MoonRatII PWA onto R4.|  <br>Base with PWAs.| NA|
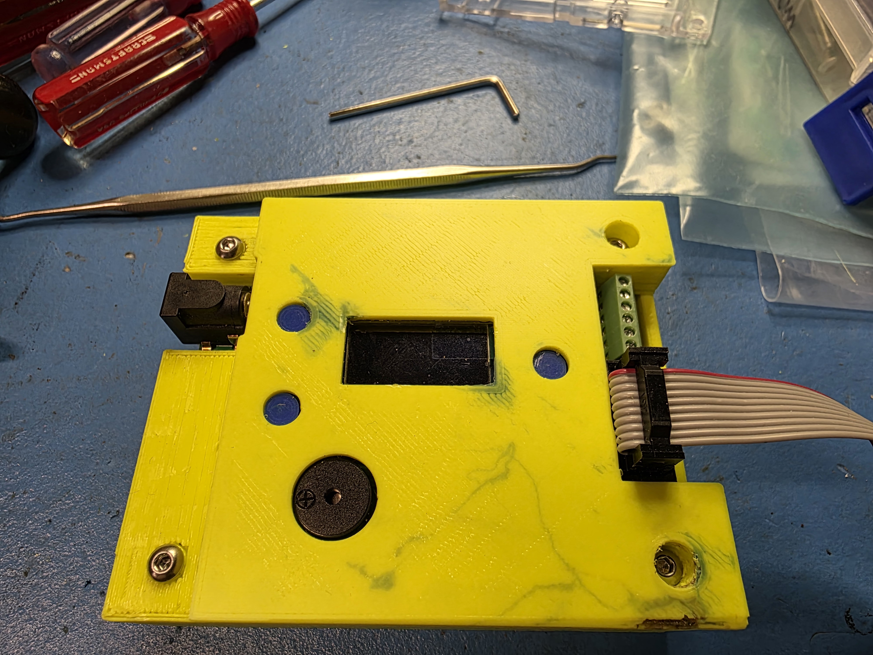
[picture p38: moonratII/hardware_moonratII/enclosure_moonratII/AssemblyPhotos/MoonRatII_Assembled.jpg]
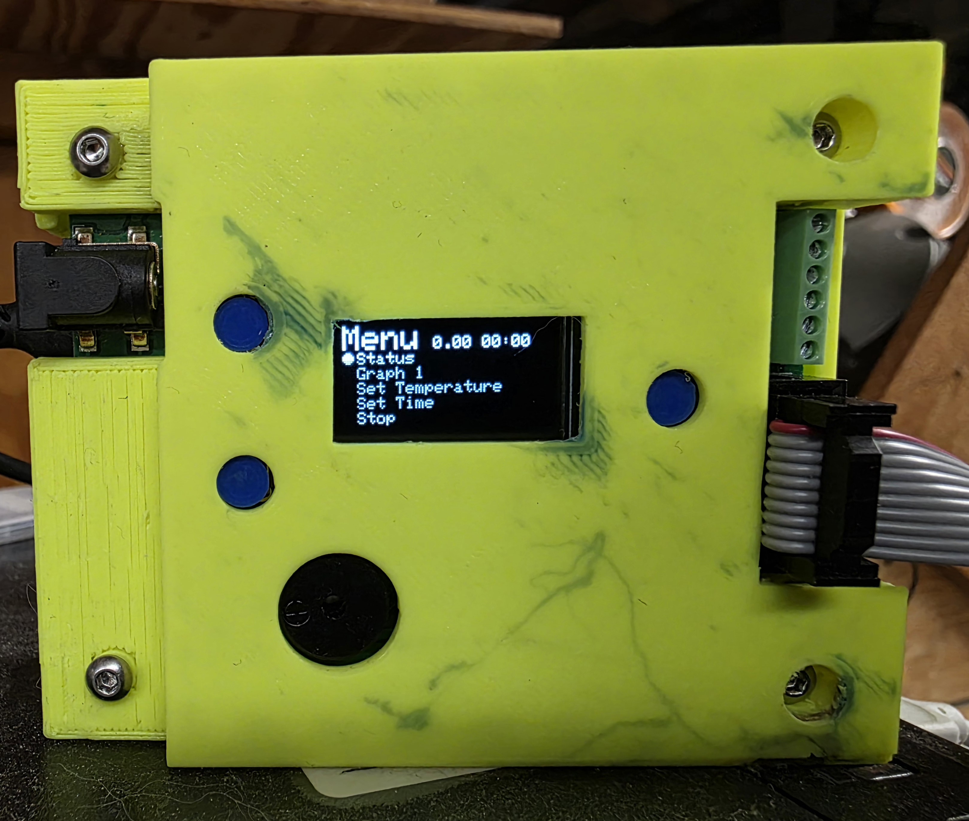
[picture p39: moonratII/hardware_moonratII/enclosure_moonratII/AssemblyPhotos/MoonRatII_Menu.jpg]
| <br>MoonRateII assembled.|  <br>MoonRatII with Menu Display.| NA|

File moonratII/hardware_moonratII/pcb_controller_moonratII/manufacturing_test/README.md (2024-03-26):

# Factory Test Plan, MoonRat V1, Printed Wiring Assembly
Journal of tests for assemblies of silk screen 20231120.  
PCB assembly by JLCPCB with some finish work in Connecticut.  

Five Assemblies assigned SN 1-5.  Lable with sharpie.  


## Update 20230123 -> Link to the Moonrat II Wokwi simulator: 
https://wokwi.com/projects/384727010846638081  
_TODO: get up to date from Horacio_

## Resources
12V @ 1.5 A power supply. Color the plug Red. 
Multi meter to measure voltage and resistance.  (Actual Multimeter: AstroiAI  DM6000AR )  
PC with Arduino IDE to connect to USB programing port of UNO.
Firmware: https://github.com/PubInv/NASA-MCOG/tree/develop/elec/Control%20Board/Control_1v1/FactoryTest  
Arduino Sketches: 
1. Foo
2. Bar

## Test Procedure
### Before Test, Finish Assembly
Photos of received assemblies at in folder at:
https://github.com/PubInv/moonrat/tree/main/moonratII/pcb_moonratII/manufacturing_test/Assembly_photos_Rev1
See also testing notes and rework against short of USB to SW1 at https://github.com/PubInv/moonrat/issues/209

These tests make sure we can plug the device into power with out letting out magic smoke.
**Check polarity on:**
1. Buzzer
2. D1  Look for the laser mark across the part. This is the Cathode.


3. Connectors: J5, J6, J9, J10, J11
4. U1

Install M2x6 screws at the four corners of the OLED. Manufacturier:  ________,  Partnumber: ____________, Steel Pan Head Phillips Screw M2 x 0.4 mm Thread, 6 mm Long

De-panalize the Heater from the Controller.  Place the Controller over a hard surface. Hold it. Hold it down against the hard surface. Press the Heater side down to break it clear.

Install (Solder) the feed through headers for the UNO connections which make this assembly become a shield for a UNO.

### Unpowered Test of PWA.

**Summary and data capture table**

Tester Name ____ Melanie Laporte ________________
Date of Test _____ 20220126 _____________________

| Test ID 	| Test Name 	| Setup 	| Test Location 	| Requirements 	| Results SN 1 	| Results SN 2 	| Results SN 3 	| Results SN 4 	| Results SN  	|
|---:	|---	|---	|---	|---	|---	|---	|---	|---	|---	|
| 1 	| Inspection 	| Inspect correct orientation on polarized parts 	| 	| 	| D1 and D2 Probably backwards. | 	| 	| 	| 	|
| 3 	| +12In In No Short 	| Set ohm meter 20M. Com to GND 	| J1 pin 1 to GND | > 100K 	 | Open  |  Open 	| Open | Open 	| Open 	|
| 4 	| NA 	| Set ohm meter 20M. Com to GND 	| J8 Pin 1 | Open or > 1 Meg 	| Open | Open 	| Open 	| Open 	| 	|
| 5 	| NA 	| Set ohm meter 20M. Com to GND 	| J3 Pin 4 | Open or > 1 Meg 	| 12.1 Meg | Open 	| Open 	|  foo | 	|
| 6 	| NA 	| Set ohm meter 20M. Com to GND 	| J3 Pin 5 | Open or > 1 Meg 	| 11.7 Meg | Open 	| Open 	| Open 	| 	|

### Program UNO with Firmware
Before connecting to the MoonRatII V1 Assembly, program the Uno with the factory test firmware "?????.ino" 

## Finish Assembly

#### Build Up MAX31850 Thermocouple Amplifier Sub Assemblies
.....

### Apply power. 
....

### Temperature Measurements.
....

**Results continued...**
A table of results here...

### End of Test
Power off the unit under test.
Remove all connections 
Box up unit.

## Rejoice another great MoonRatII has been born!

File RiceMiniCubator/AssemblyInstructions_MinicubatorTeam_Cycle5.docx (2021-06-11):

Full Minicubator assembly is broken into four parts -- enclosure sub-assembly, electronics sub-assembly, code uploading, and final assembly.

Enclosure Sub-assembly

1. 3D print outer encasement from the enclosed .stl file (shown in Figure 1)

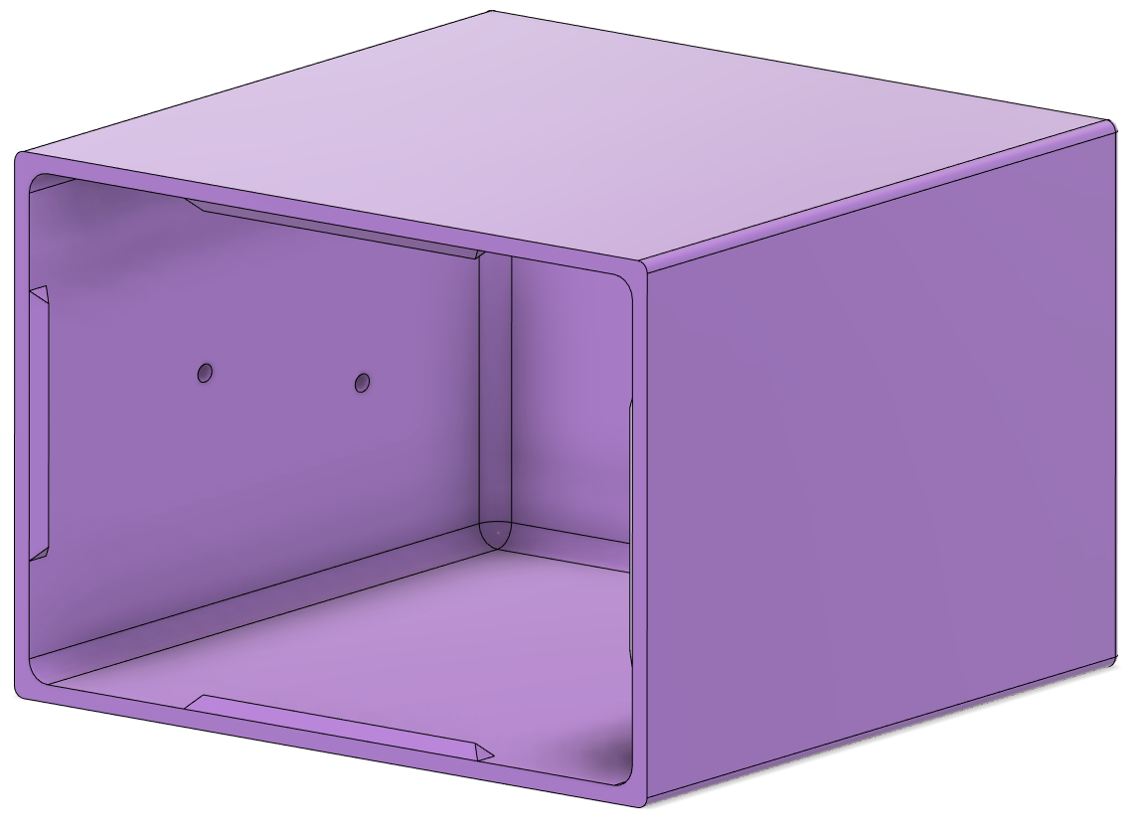
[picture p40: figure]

Figure 1. Outer encasement 3D print.

2. 3D print peg from the enclosed .stl file (Figure 2)

Figure 2. Peg to mount inner heating chamber to outer encasement. There is a flat end on each of the two sides.

3. 3D print inner heating chamber from the enclosed .stl file (Figure 3)

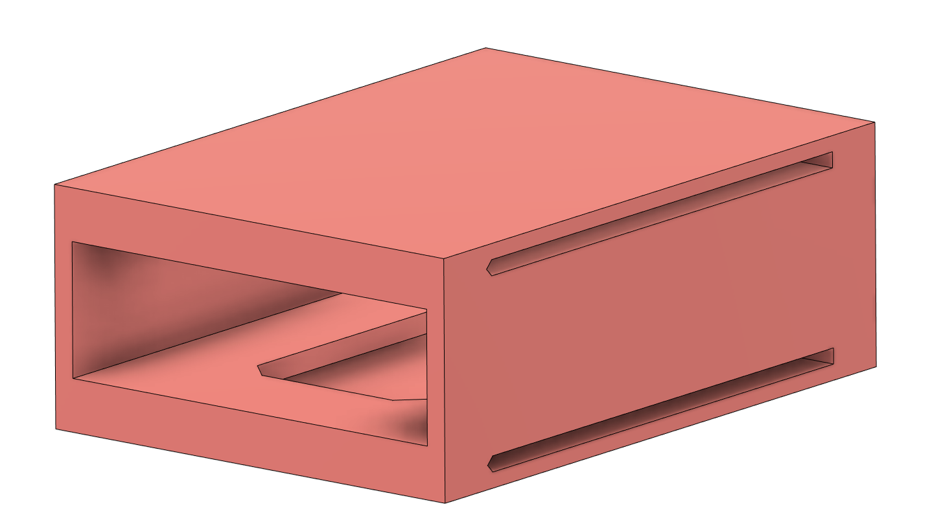
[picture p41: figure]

Figure 3. Inner heating chamber. Note that this will be a green box representation in future steps.

4. 3D print lid/petrifilm holder from the enclosed .stl file (Figure 4)

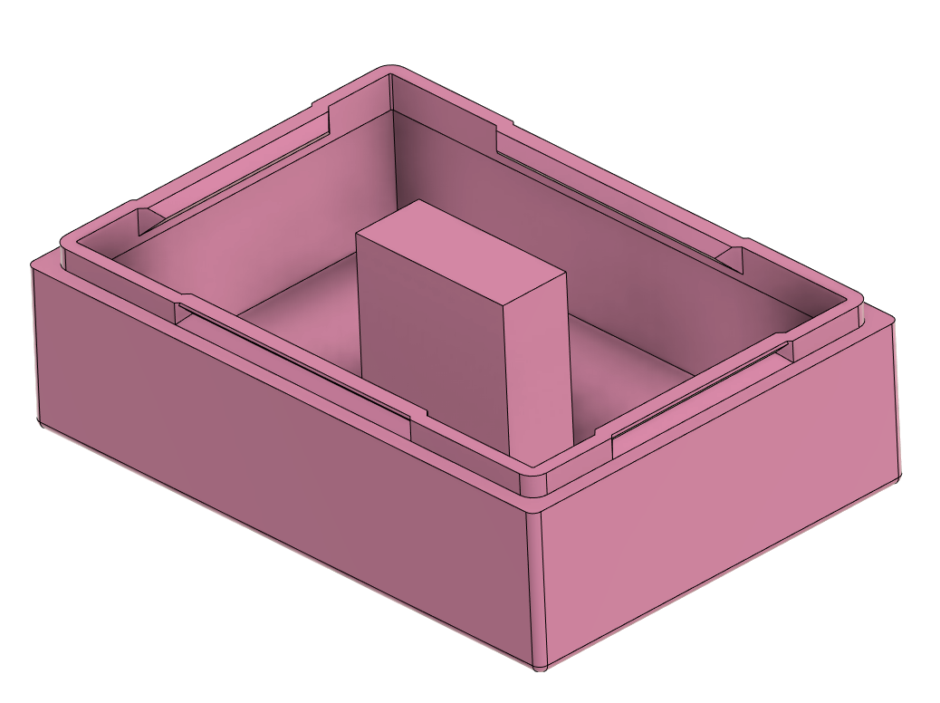
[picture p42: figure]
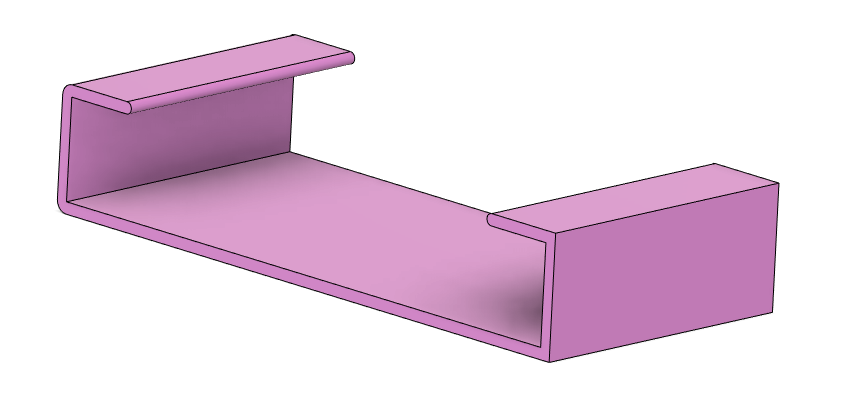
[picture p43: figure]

Figure 4. Designs of the lid and petrifilm holder.

5. Using super glue, apply a single layer (approximately one pea-sized dab) of superglue or cyanoacrylate (generic superglue) to one of the flat ends of the peg and adhere the peg onto the center of the outer wall of the inner heating chamber (Figure 5).

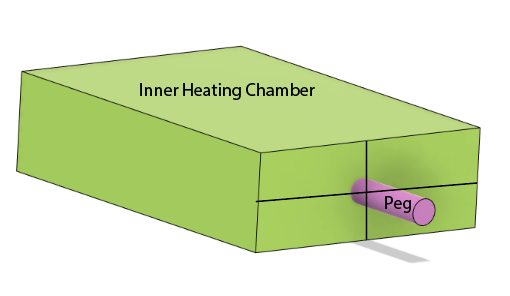
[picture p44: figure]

Figure 5. Attachment of peg to inner heating chamber. Note that this is the same as the orange print shown in Figure 3.

6. Apply a layer of glue to the other (open) end of the peg and insert into the center of the interior wall of the outer encasement, as depicted below (Figure 6).

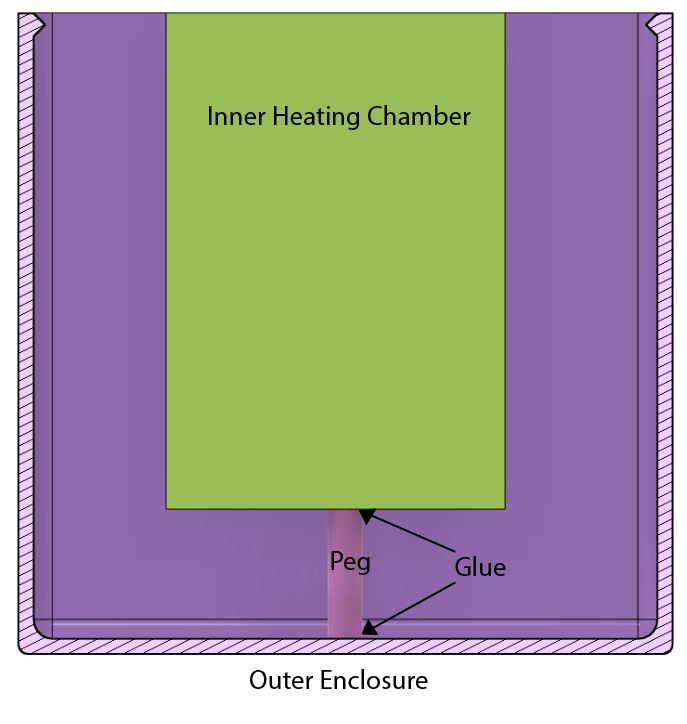
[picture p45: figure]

Figure 6. Attachment of inner heating chamber and peg to outer encasement.

7. Bond inner heating chamber and outer encasement gap with polyurethane foam.
  a. Hold the 3D print of the inner heating chamber
  b. Aim nozzle of polyurethane foam canister into the gap between inner heating chamber wall and outer encasement. The foam will expand to fill all of the cracks and crevices.

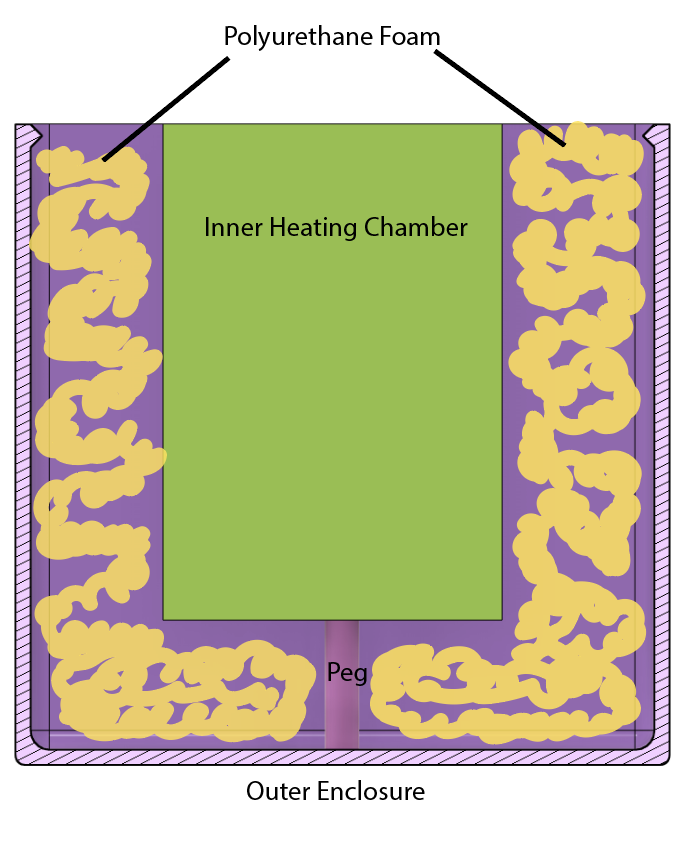
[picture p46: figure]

Figure 7. Qualitative filling of the inter enclosure space with polyurethane foam.

  c. Fill with polyurethane by pressing on the nozzle and releasing the polyurethane foam into the intermediate chamber between the inner heating chamber and outer encasement. Move in a circular manner around the intermediate chamber to ensure even spread of foam. Let sit to dry. (Figure 7)
8. Fill the lid with polyurethane as done for the outer chamber (Figure 8). The polyurethane will expand as before. Once the polyurethane expands, the excess will need to be cut away using a band saw or standard tooth saw.

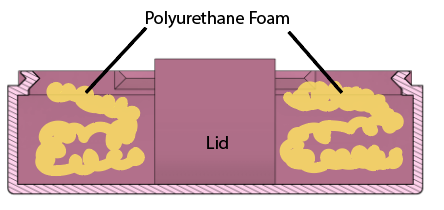
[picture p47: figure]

Figure 8. Filling of polyurethane foam into the lid material.

9. Glue the petrifilm holder to the top of the lid using approximately 1 mL of superglue or cyanoacrylate (generic superglue), as depicted below. Glue should be applied to the front end of the petrifilm holder as shown below, and adhered to the abutment on the lid.

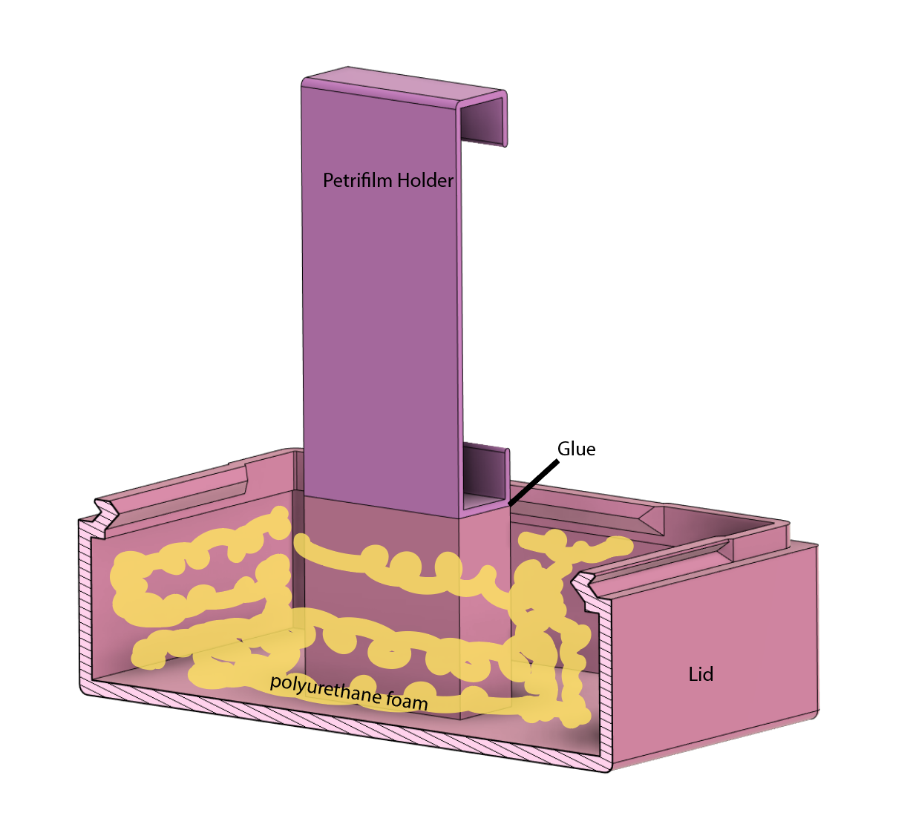
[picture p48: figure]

10. Once the petrifilm holder dries and adheres to the lid, then the lid assembly is finished. The lid should now slide into the inner chamber and snap into the enclosure.

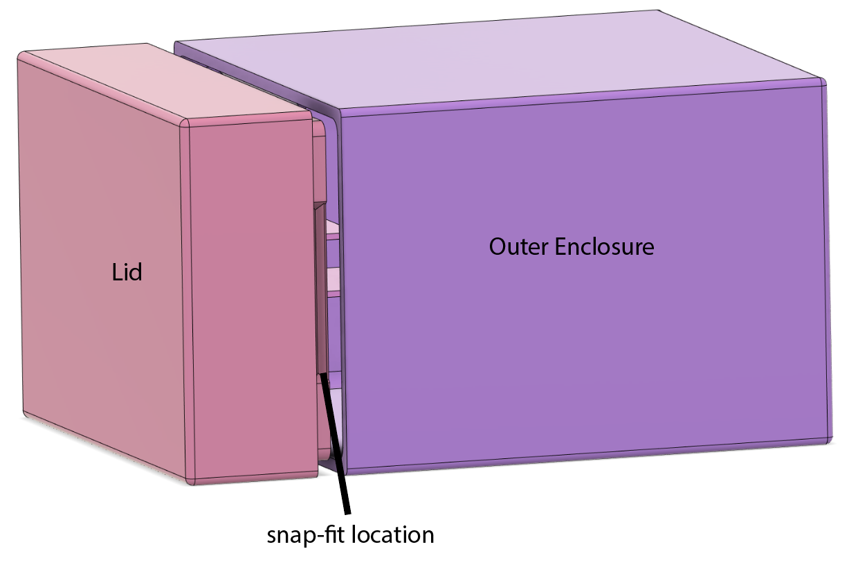
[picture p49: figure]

Electronics Assembly

Materials: PCB, Arduino Nano Every, Buttons (x3), Piezo, LED, Heating Pad with wire, Thermistor with wire, MOSFET, OLED breakout board.

1. Remove Arduino Nano Every and the two sets of header pins enclosed with the Arduino Nano Every from packaging.
2. Insert the header pins into the Arduino Nano Every such that the short ends of the pins are inserted into the circular holes embedded on each side of the Arduino, and the long ends of the pins are located on the side opposite that with all circuit elements.
3. Insert Arduino Nano Every into the port for the Arduino in the configuration as denoted in Figure 9 below, and solder all header pins to the board as well as the arduino. The footprint on the board matches that of the Arduino, so the pins should line up correctly.

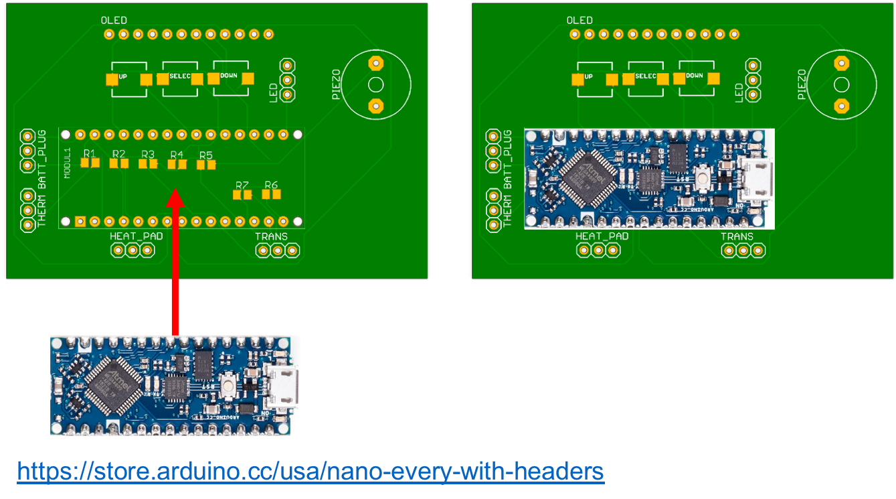
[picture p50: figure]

Figure 9. Orientation and positioning of the Arduino with the PCB. Arduino from [1].

4. Attach the button to the PCB in the following manner, and solder the buttons in place (Figure 10).

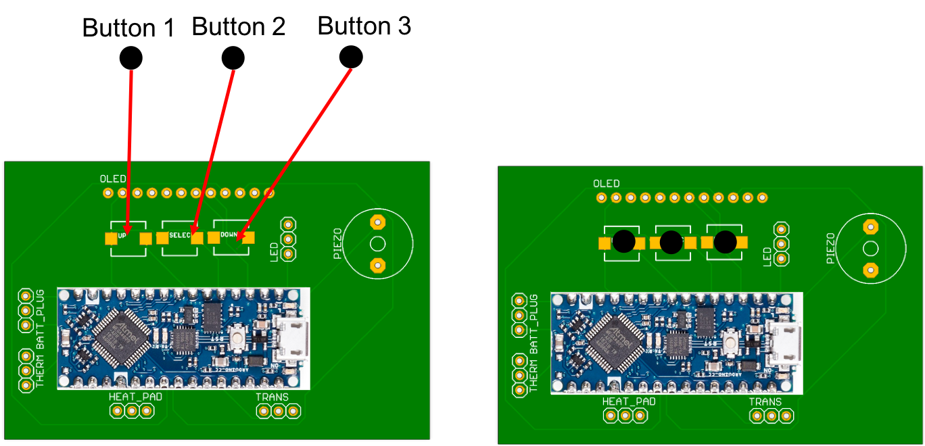
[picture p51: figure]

Figure 10. Mount of each of the three (indistinguishable) buttons onto the respective locations on the PCB.

5. Attach the piezo on the PCB in the following manner, and solder the piezo in place (Figure 11).

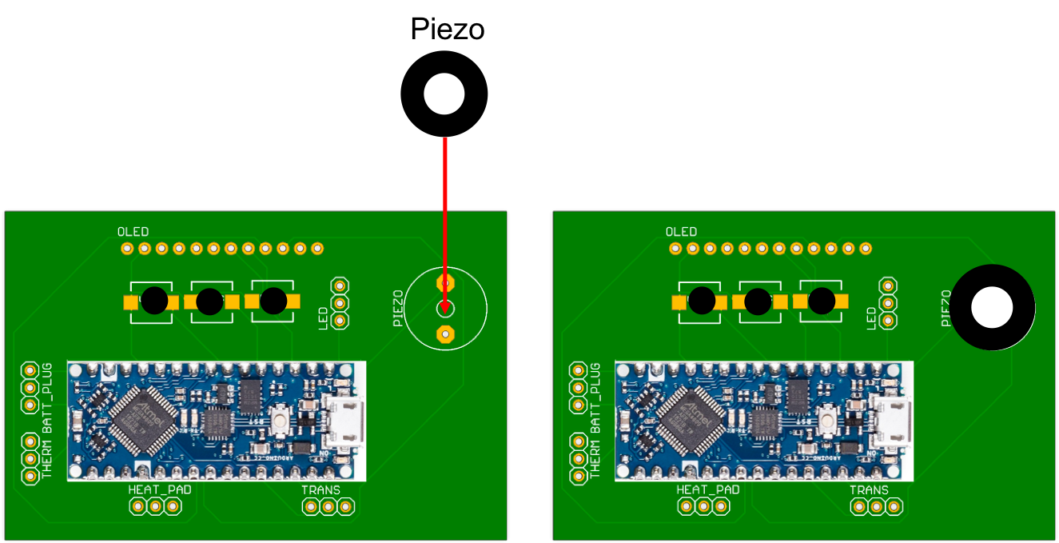
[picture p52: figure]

Figure 11. Piezo placement.

6. Remove the temperature measurement device and heating pad of the device. Solder them to the following port as follows (Figure 12).

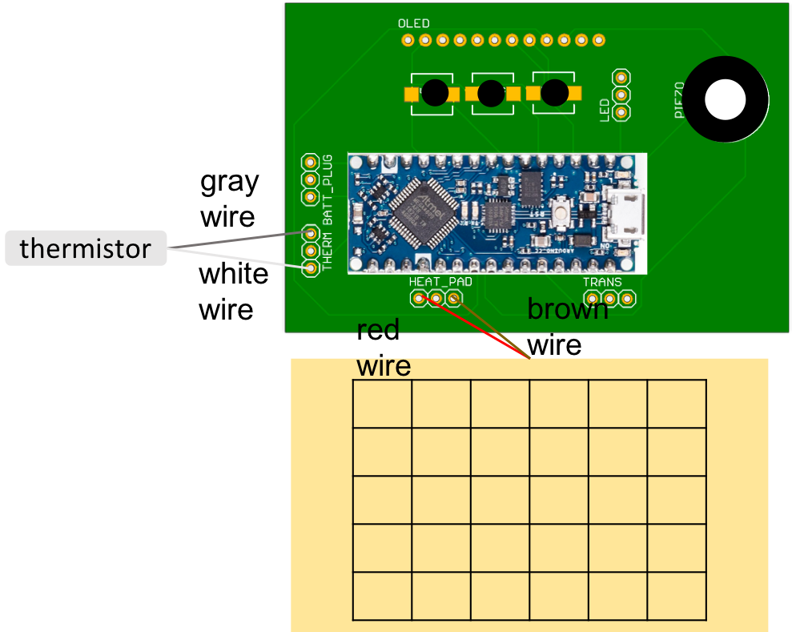
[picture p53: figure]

Figure 12. Thermistor (gray) and heating pad (goldenrod with grid) placement, with wire color connections to the PCB.

7. Solder the transistor in the following connections, in the shown orientation (Figure 13).

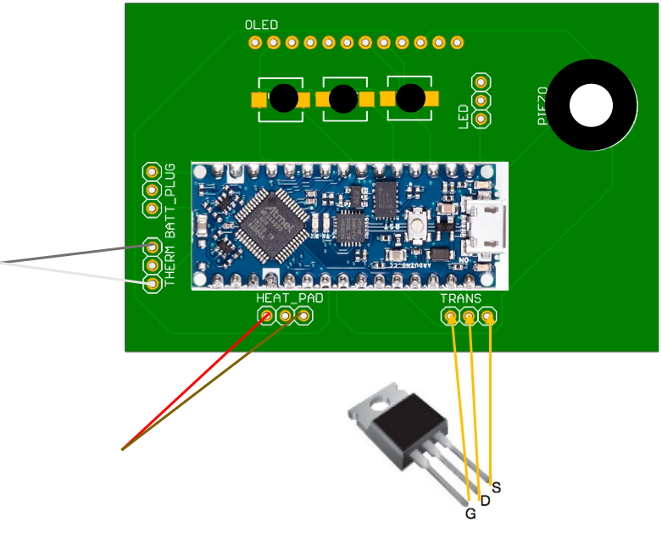
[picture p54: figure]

Figure 13. Connections of the N-channel transistor to the PCB as shown [2].

8. Remove the OLED and the header pin from its packaging. Attach the header pin into the OLED ports as follows, with the short end of the header pin connecting to the port on the OLED, and solder all pins in place.
9. Solder the long end of the header pin into the board of the PCB (Figure 14).

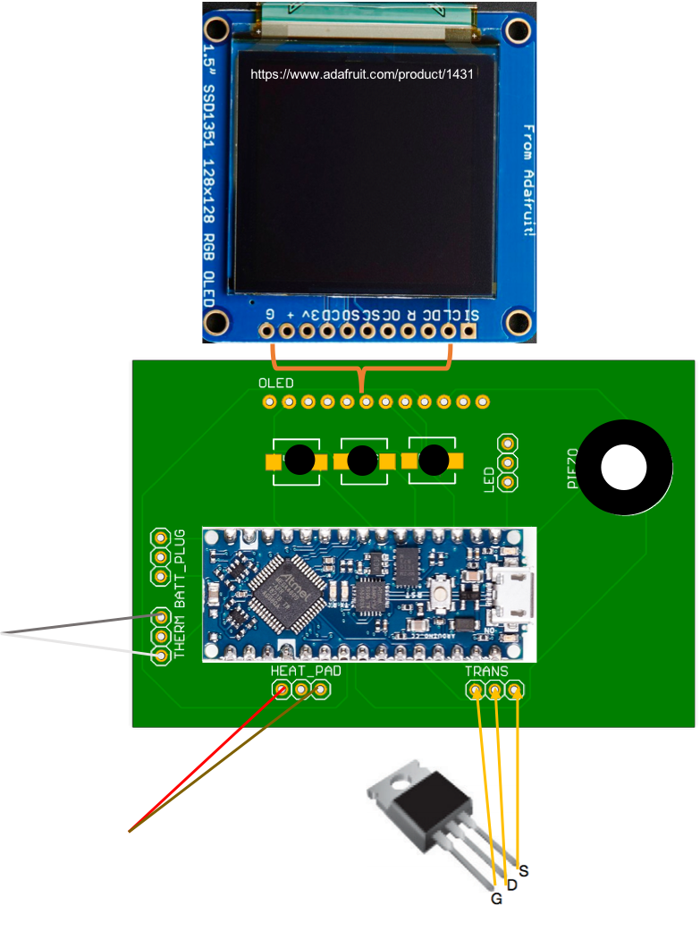
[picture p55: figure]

Figure 14. Connection of OLED to the PCB. OLED photo taken from [3].

Code Uploading

1. Download the enclosed software onto a personal computer.
2. Using a microUSB-USB adaptor, connect the Arduino to the computer.
3. Open the Arduino code downloaded in (1). Open the Arduino code, and click on “Upload” in the top right corner of the Arduino Interface.
4. Once the upload is complete as signaled by the computer, remove the connection by removing the microUSB from the adaptor of the Arduino.

Full Minicubator Device Assembly:

1. Place the PCB as shown into the mounting plate of the electronics enclosure.
2. Close the electronics enclosure and snap the upper lid shut.
3. Insert the thermistor and heating pad connections into the enclosure through the associated holes (Figure 15).

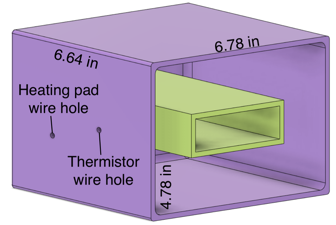
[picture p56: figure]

Figure 15. Site of insertion of heating pad wire hole and thermistor wire hole.

4. Glue the electronics enclosure onto the top of the main enclosure, as follows using superglue or cyanoacrylate (generic superglue) (Figure 16).

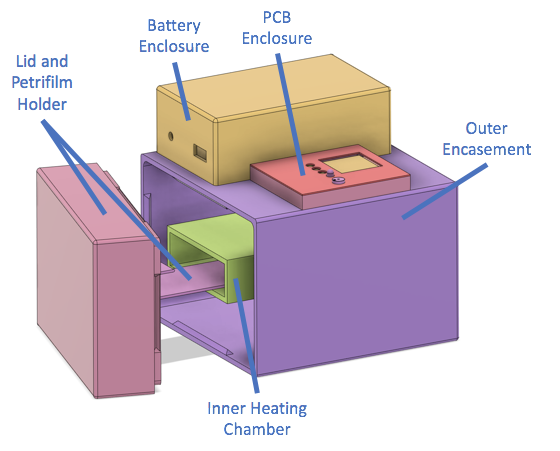
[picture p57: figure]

Figure 16. Full Assembly rendering.

References

[1] “Arduino Nano Every with headers | Arduino Official Store.” https://store.arduino.cc/usa/nano-every-with-headers (accessed May 05, 2021).

[2] “N-channel power MOSFET.” https://www.adafruit.com/product/355 (accessed May 05, 2021).

[3] “OLED Breakout Board - 16-bit Color 1.5" w/microSD holder.” https://www.adafruit.com/product/1431 (accessed May 06, 2021).

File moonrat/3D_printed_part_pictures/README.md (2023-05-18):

# 3D_design
This folder contains photographs of the fabricated 3D base to hold a thermos used to incubate samples.  
The Solidworks desing files are in the folder: 3D_design

<a
href="./6C0C779D-602B-4875-BB12-1951AA8B21C5.jpg">
</a> 

<a
href="./9DBF69BE-EAB6-436A-977B-694C6931730C.jpg">
</a> 
<a
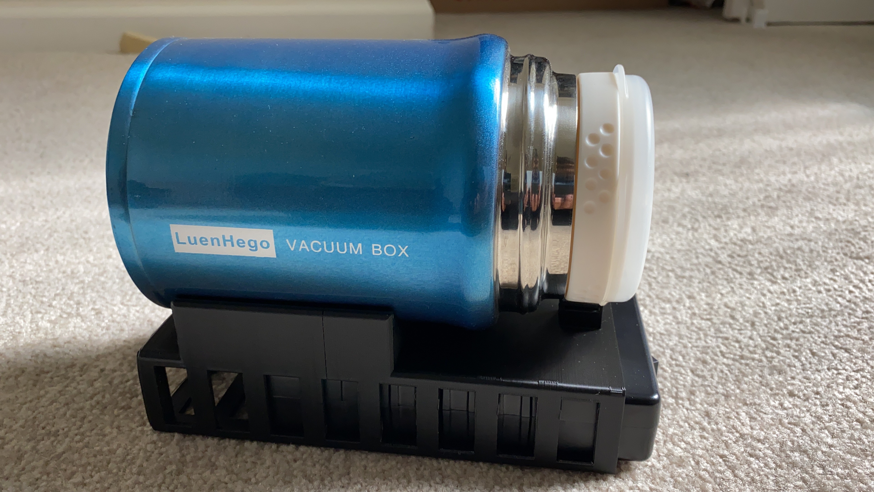
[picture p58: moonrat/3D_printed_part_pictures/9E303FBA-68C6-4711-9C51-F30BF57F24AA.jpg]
href="./9E303FBA-68C6-4711-9C51-F30BF57F24AA.jpg">
</a> 

<a
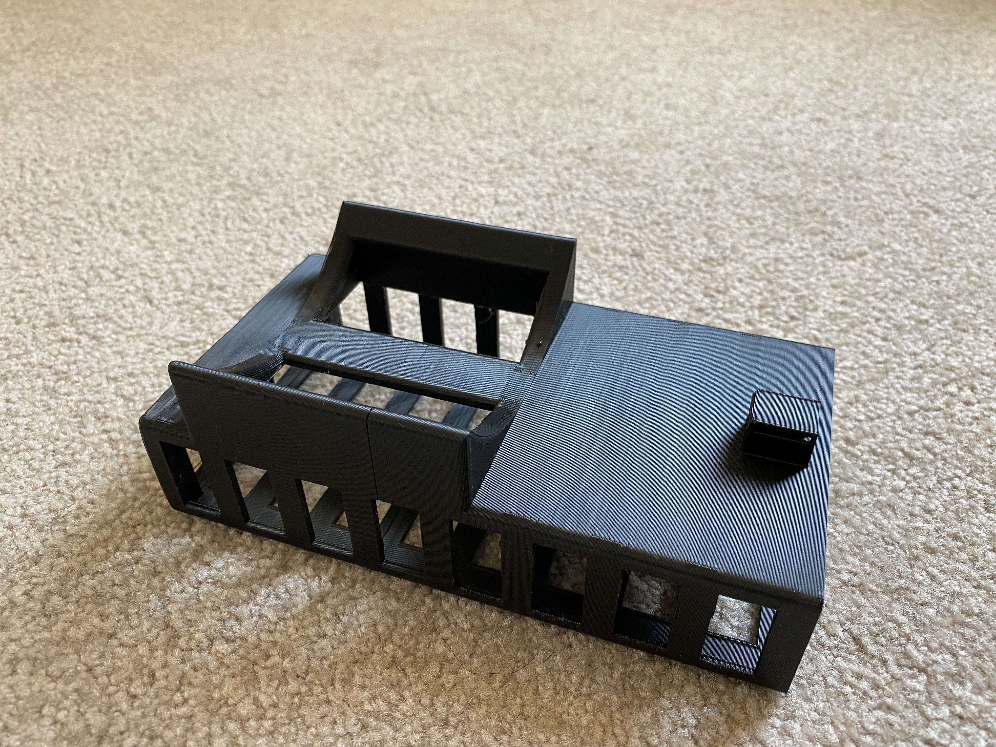
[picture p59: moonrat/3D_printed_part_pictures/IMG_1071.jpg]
href="./IMG_1071.jpg">
</a> 

<a
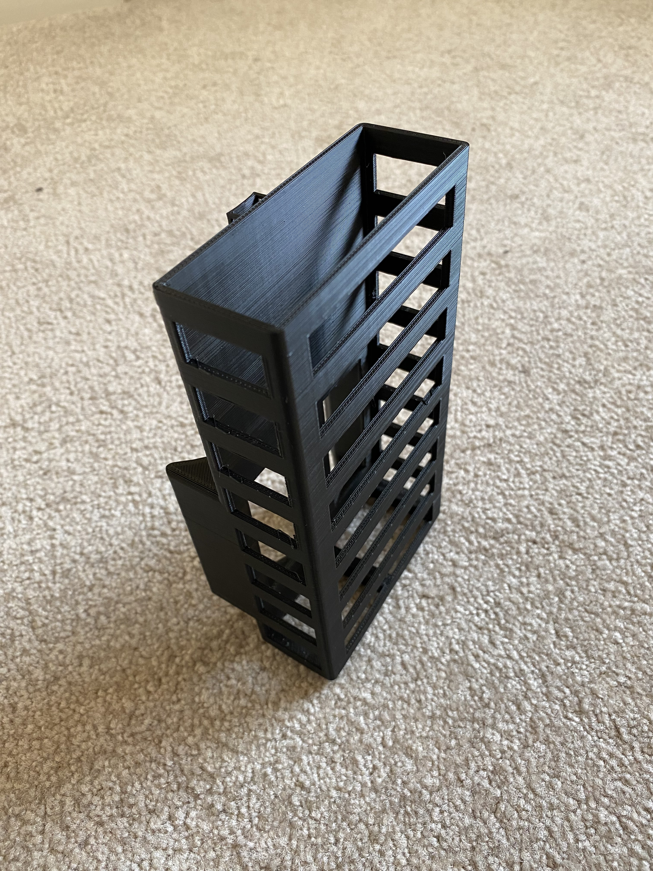
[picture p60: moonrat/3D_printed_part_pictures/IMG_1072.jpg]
href="./IMG_1072.jpg">
</a> 

<a
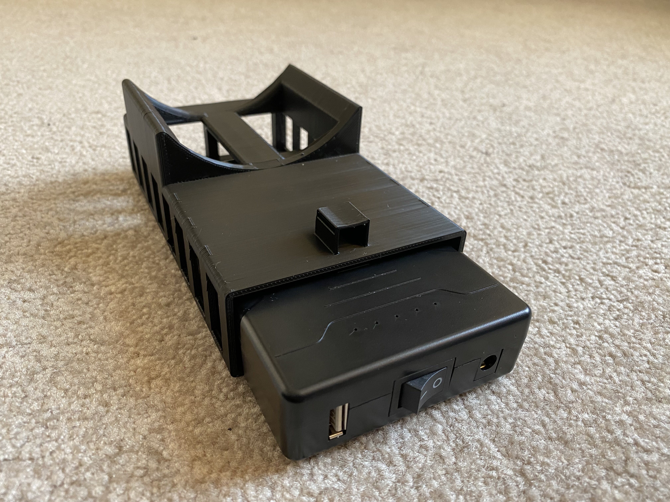
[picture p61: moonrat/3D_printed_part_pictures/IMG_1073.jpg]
href="./IMG_1073.jpg">
</a> 

<a
href="./IMG_1073.jpg">
</a> 

<a
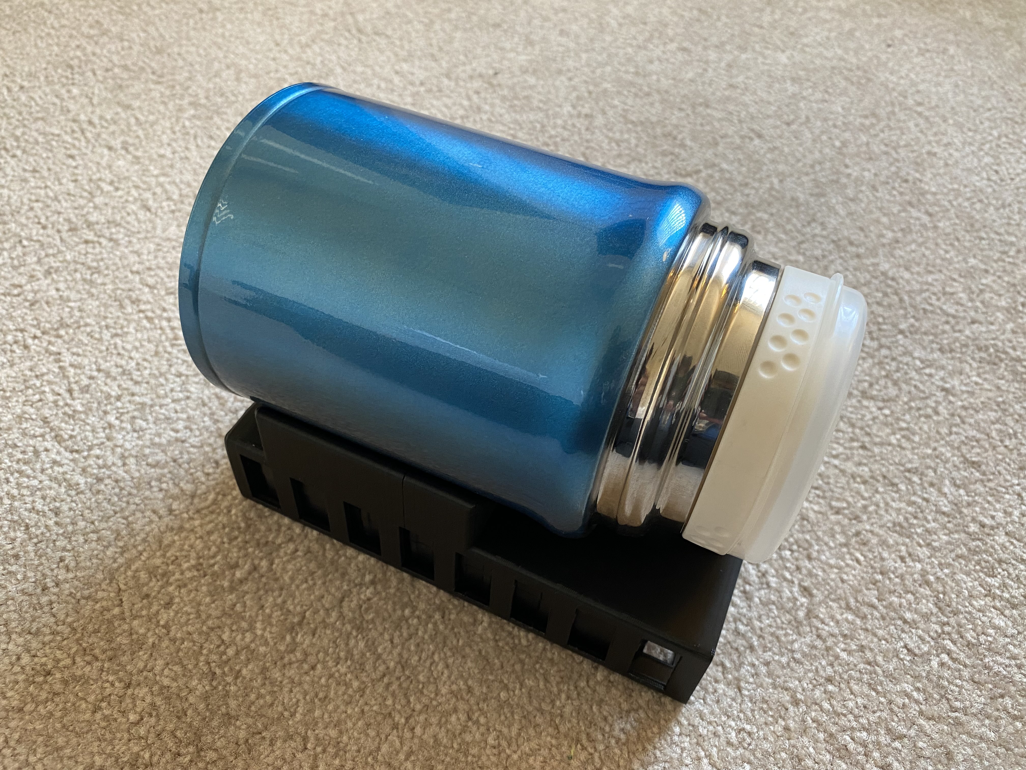
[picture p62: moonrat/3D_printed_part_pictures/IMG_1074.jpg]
href="./IMG_1074.jpg">
</a> 

<a
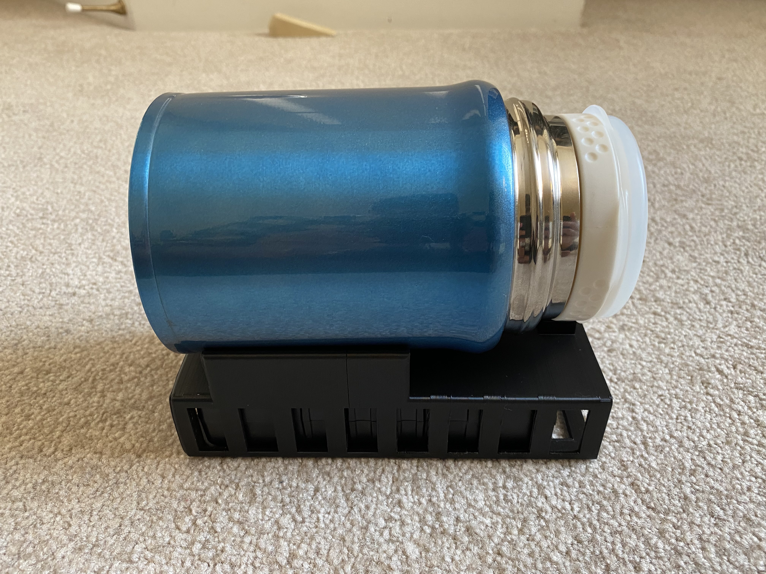
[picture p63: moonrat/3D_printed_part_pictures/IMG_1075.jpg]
href="./IMG_1075.jpg">
</a> 

<hr>
<h6><i> This file created by F. Lee Erickson, 20230518</i></h6>

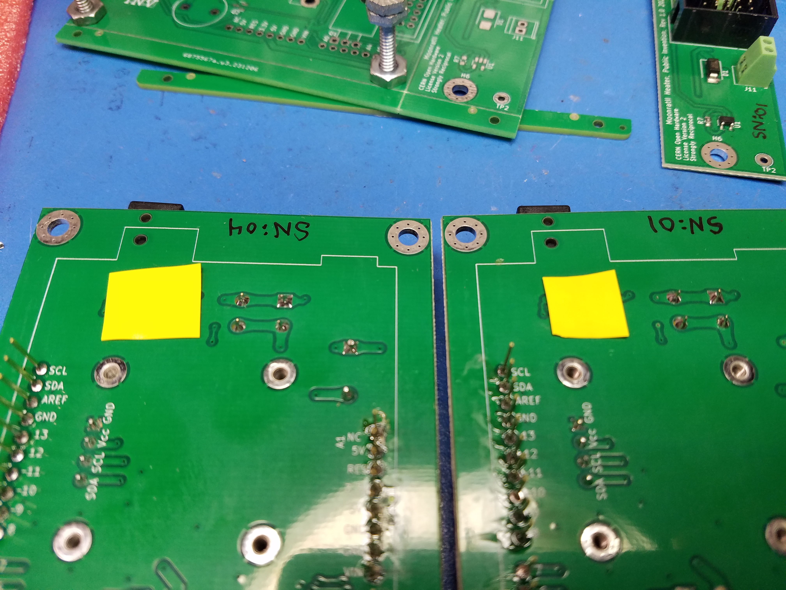
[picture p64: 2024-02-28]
moonratII/hardware_moonratII/pcb_heaterboard_1_moonratII/manufacturing_test/DELETE Assembly_photos_Rev1/20240217_200030.jpg

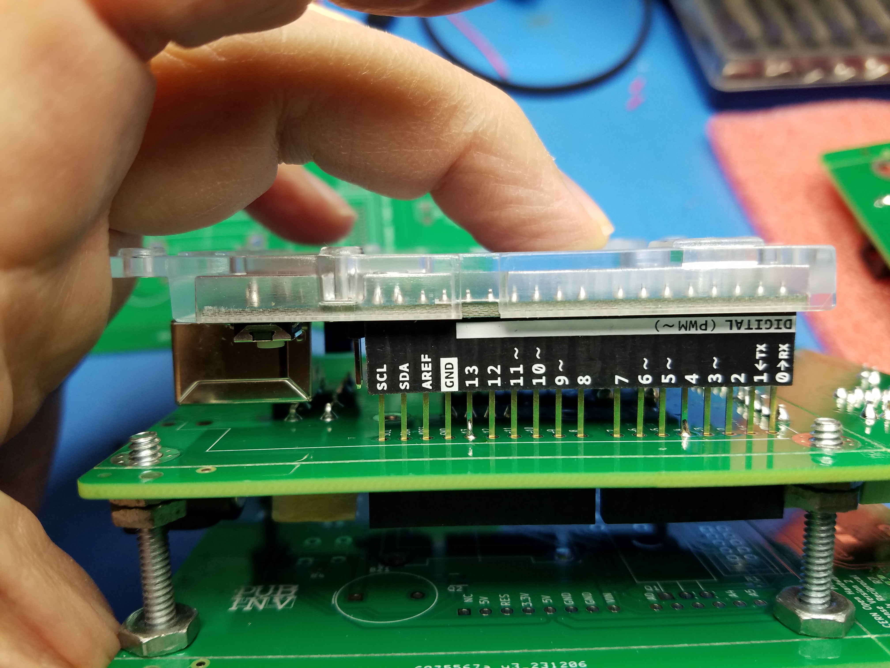
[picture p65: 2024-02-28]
moonratII/hardware_moonratII/pcb_heaterboard_1_moonratII/manufacturing_test/DELETE Assembly_photos_Rev1/20240217_185215.jpg

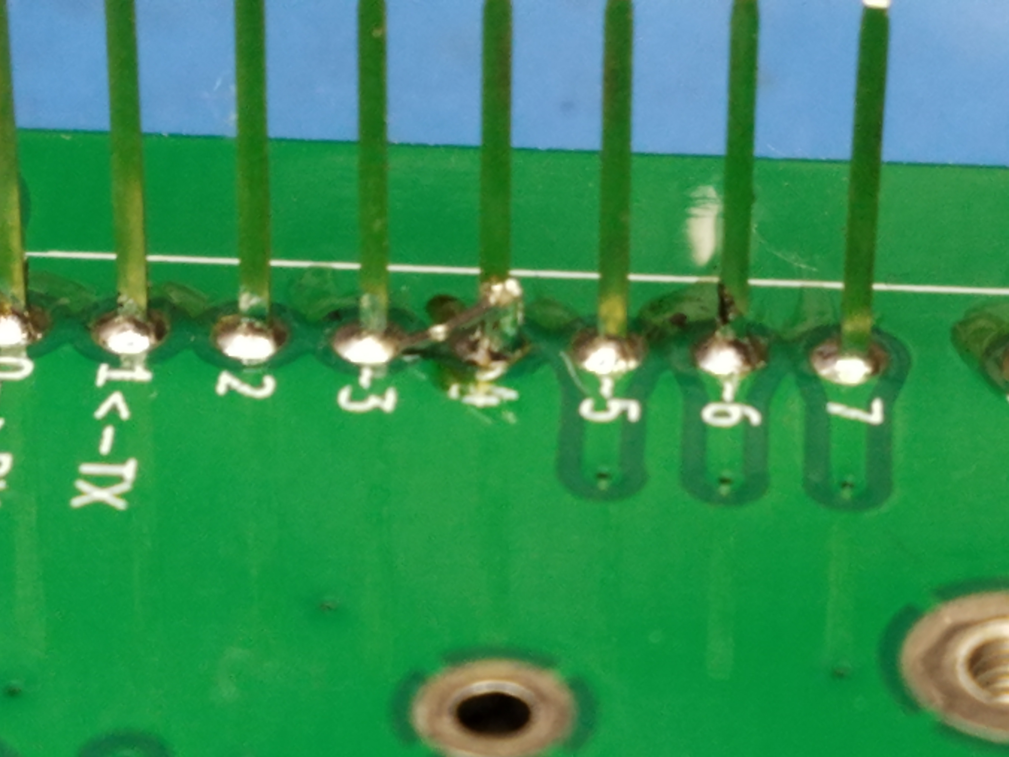
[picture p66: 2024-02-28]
moonratII/hardware_moonratII/pcb_heaterboard_1_moonratII/manufacturing_test/Assembly_photos_Rev1/20240217_200458.jpg

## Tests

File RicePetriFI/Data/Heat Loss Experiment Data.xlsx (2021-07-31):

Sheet: Variable Voltage
Voltage (V) | Current at Temp (mA) | Chamber Temperature (C) | Temperature from Ambient (C) | Heat Loss near Steady-State (W) | Estimated Ambient Temperature (C): | 20
3 | 247.5 | 25.6 | 5.6 | 0.7425
4
5 | 407.8 | 34 | 14 | 2.039
6 | 471.3 | 38.3 | 18.3 | 2.8278
7 | 555.4 | 46 | 26 | 3.8878

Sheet: "Pink Box" Testing
Trial 1 - no aluminum inside
Starting temp (C) | 20
current at beginning (mA) | 850 | (estimate) | current dropped quickly at the beginning, then slowed down
Time to heat to 35C | 8:12:00
current at 35C (mA) | 664.2 |  | temperature went up to 37C even after turning it off - this is because heating pad itself was warmer than the actual 35 that the air being measured was
highest temp | 37
time to start going down from 37C | 6:08:00
Time to cool to 35C | 6:53:00 | (not sure what this time was referring to) |  | petrifilms read as 32 when we pulled them out - because thermal "inertia" of petrifilms kept it near 35 even when the air was cooling down
Trial 2 - aluminum foil partially covering inner top and sides |  |  | stop at 35
Starting temp (C) | 20
current at beginning | 850 | (estimate)
time to get to 35C | 7:38:00 |  |  | wires in heating pad resistor are stainless steel - we should look up resistance heating curve to find the temperature of the heating pad itself
current at 35C | 664
highest temperature (C) | 37
time to get to 33 | 13:19:00
Letting the chamber get as hot as possible
current at 51C | 645 | reaching max temperature with this heating chamber - current is plateuing
current at 59C | 640 |  |  |  | idea: create a temperature profile - for each heating chamber, show heat loss curve at varying temperature differences
resistance at 59C (ohms) | 18.75
heating from pad at 59C (W) | 1.333
current at 66C | 632 |  |  |  | open source application for above idea: for each person's individual container, can make heat loss curve

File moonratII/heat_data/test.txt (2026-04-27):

26.10
360
26.23
390
26.35
420
26.50
450
26.65
480
26.78
510
26.87
540
26.96
570
27.06
600
27.17
630
27.28
660
27.41
690
27.53
720
27.66
750
27.76
780
27.88
810
28.01
840
28.18
870
28.31
900
28.42
930
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

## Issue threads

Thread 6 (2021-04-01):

MoonratII Enclosures, Controller with OLED Screen, Buttons, Cables and Incubator, and Battery Holder

RobertLRead, 2021-04-01:
This is an issue, probably for Harshit, to cover the design of the enclosure for the electronics.  However, it also includes the "bracket" for the battery, and a holder for the thermos jar. We might create sub issues here for these three pieces.

ForrestErickson, 2023-11-07:
@RobertLRead
@melanielaporte

I am reopening this to capture enclosure design for the moonratII phase of the project.
Place enclosure design files at: https://github.com/PubInv/moonrat/tree/main/moonratII/enclosure_mooonratII

## Enclosure Requirements
- [ ] Fit the moonratII printed wiring assembly at mounting points.
- [ ] Opening for the three buttons SW1, SW2 and SW3 with appropriate purchased Key Caps of the vendor of the switches.
- [ ] Opening for the OLED display centered on the display portion
- [ ] Opening for the buzzer.
- [ ] Opening for the power cable
- [ ] Opening for the USB cable
- [ ] Opening and strain relief for the cable to the incubator heater. Note cable might be to a molded connector or a IDC (Insulation displacement connector).
- [ ] 3D printable parts
- [ ] Design in open source CAD software (FreeCAD is preferred as their is already a start ).
- [ ] Design files for each part and an assembly drawing for the complete enclosure for the enclosure and an assembly drawing for the incubator.

## Reference
The moonratII PCB design files at: https://github.com/PubInv/moonrat/tree/main/moonratII/moonratII
Look for and save manufacturer drawings for purchased parts at: https://github.com/PubInv/moonrat/tree/main/moonratII/moonratII/parts

melanielaporte, 2023-11-12:
Issue #53 has a mechanical drawing for the switch key cap.

Closed 2024-02-20.

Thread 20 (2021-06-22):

Design of 3D printable "puck"

RobertLRead, 2021-06-22:
Note: This should have two loose "chambers" (not enclosed, just framed). The upper should hold the Petrifilms, and the lower should hold the heating cloths. I recommend a "waffle" construction. It should have "legs" which reach down to the bottom of the thermos to keep the other two areas suspended. Contact with the metal of the thermos should be relatively small, and relatively tight (maybe fit with a slight compression of the material so it doesn't rattle. Note that a modification of this puck could hold a full petri dish.Note that Petri dishes are normally 16 mm high and we can easily support a width of 120mm stacked several high.

ErickAlex, 2022-01-30:
Hi, Please let me know how I can contribute. I am a design engineer with 10+ years experience. I am also good with metal and woodworking if needed. I am based out of Houston, TX.

RobertLRead, 2022-01-31:
@ErickAlex Thank you. Can you please email me at <read.robert@gmail.com> ?  What we really need right now is an Arduino/electrical engineer for this project. But I would love to use you even if you are only do 3D modeling, and there are several interesting projects that might interest you.

Closed 2022-08-08.

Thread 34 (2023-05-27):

Feature Request: Fuses for Safety??

melanielaporte, 2023-05-27:
Do we need to have current limit in the product so the fuses do not blow??

RobertLRead, 2023-05-30:
I will set @FORREST ERICKSON ***@***.***> weigh in on
this, but think not.

Moonrat is a low-voltage, modestly low-amperage system. Fuses are usually
not required for that.

However, Lithium Ion batteries can start fires, and physical damage can
create a short circuit. Some sort of break if we draw too many amps is a
good idea; I think Lee knows some tricks beyond installing changable fuses.

On Sat, May 27, 2023 at 6:46 PM magnetictheory ***@***.***>
wrote:

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

--
Robert L. Read, PhD
Twitter: @RobertLeeRead @pubinvention
Public Invention: https://www.pubinv.org
Join Our Mailing list: ***@***.***
YouTube: https://www.youtube.com/channel/UCJQg_dkDY3KTP1ybugYwReg
Medium: ***@***.***

ForrestErickson, 2023-05-30:
A deliberate step in the produce design process is FEMA and acronym for Failure Effect Mode Analysis. And for Safety compliance such as UL 60950 .  However when I googled this I find it was a standard approximately for " audio/video, IT, and communication products".

So I asked ChatGPT my first ever real questions first about the history of UL 950 and eventualy got to this helpful (if correct) answer:

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

ForrestErickson, 2023-05-30:
Leaving a question at the web site hosting the EN 61010

http://dfv-technologie.com/clickandbuilds/DFVTechnologie2016/index.php/fr/contact

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

ForrestErickson, 2023-09-21:
As of 20230920 there is now a fuse in the schematic and on the PCB. IIRC it is a 6A fuse which should not cause nuance trips for the anticipated 2.5A heater load but should protect a batter pack against short circuit loads.

melanielaporte, 2023-11-12:
Complete.

Closed 2023-11-12.

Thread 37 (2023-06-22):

Component Notes for moonratII

ForrestErickson, 2023-06-22:
## Notes as we make the KiCad Schematic for moonratII

The tac switch:
https://www.amazon.com/Momentary-Tactile-Through-Breadboard-Friendly/dp/B07WF76VHT/

Need a foot print. Start with Button_Switch_THT:SW_PUSH_6mm perhaps.

An OLED display
https://www.aliexpress.us/item/2251832770994631.html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
Check that it works with drivers for a domestically sourced OLED display.

Buzzer from Version 1.
https://www.amazon.com/RuiLing-12x9-5mm-Raspberry-Electronic-Continous/dp/B07S85WRSZ/ref=sr_1_5

MOSFET
https://www.infineon.com/dgdl/irf540npbf.pdf?fileId=5546d462533600a4015355e39f0d19a1&redirId=112283
THis has Vth GS of 2-4 Volts.

Temperature Sensor TMP36
https://www.arduino.cc/en/uploads/Main/TemperatureSensor.pdf

ForrestErickson, 2023-06-22:
The OLED from aliexpress also seams to be the same (Module 12864) as this one at amazon:
https://www.amazon.com/UCTRONICS-SSD1306-Self-Luminous-Display-Raspberry/dp/B072Q2X2LL

ForrestErickson, 2023-06-22:
While this part is wrong it might be a part with which to start to make a footprint for the OLED display of our choice.
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

ForrestErickson, 2023-06-22:
@melanielaporte

Some possible long lead items to get from Asia:
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

[Shop1100385546 Store](https://www.aliexpress.com/store/1100385547)

[10pcs dip 6P 10P 20P 26P 34P 40P PIN 2.54MM pitch MALE SOCKET straight idc box headers PCB CONNECTOR DOUBLE ROW DC3 HEADER](https://www.aliexpress.com/item/3256804080177769.html?mp=1)
$0.96
15-day delivery on $5.00
+ Shipping：$1.97
1

[E-Smartworld Store](https://www.aliexpress.com/store/1101542808)

[1Pcs 2.54mm Pitch JTAG ISP Gray Flat Ribbon Data Cable FC-6/8/10/12/14/16/18/20/24/26/30/34/40/50 Pin FOR DC3 F/F IDC Box Header](https://www.aliexpress.com/item/3256804576275377.html?mp=1)
$2.73
15-day delivery on $5.00
+ Shipping：$1.34
1

[Locheuk Connector Store](https://www.aliexpress.com/store/1101281897)
Get discount

[2.54mm/0.1" Pitch PCB Screw Terminal Block Connector 2P 3P 4P 5P 6P 7P 8P 9P 10P 12P 16Pin Terminals 150V 6A for 26-18AWG Cable](https://www.aliexpress.com/item/2255800681269043.html?mp=1)
$3.75
15-day delivery on $5.00
+ Shipping：$2.91
2

[Win win.](https://www.aliexpress.com/store/1100787794)
Get discount

[0.96 inch IIC Serial 4pin White/Blue/Yellow Blue/Yellow OLED Display Module 128X64 12864 LCD Screen Board for arduino oled](https://www.aliexpress.com/item/2251832770994631.html?mp=1)
$1.47
15-day delivery on $5.00
+ Shipping：$2.32
10
Summary
Subtotal
$25.89
Shipping fee
$8.54
Total
$34.43

ForrestErickson, 2023-07-30:
@RobertLRead ,
Is the design asumption to have the two color OLED display with yellow on top and blue below?
I have a vague recollection of seeing that on the moonrat somewhere but do not remember for certain.
Image:
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

Lee
CC: @melanielaporte

ForrestErickson, 2023-07-30:
@melanielaporte ,
Note:
Specifications for UCTRONICS OLED display:
https://www.uctronics.com/display/uctronics-0-96-inch-oled-module-12864-128x64-yellow-blue-ssd1306-driver-i2c-serial-self-luminous-display-board-for-arduino-raspberr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

Dimension drawing for UCTRONICS OLED display:
https://www.uctronics.com/download/Mechanical_Drawing/U602602_Dimension_New.jpg

Interface instructions:
https://www.uctronics.com/download/Amazon/U602602.pdf

RobertLRead, 2023-07-30:
No it does use that but that was just what we had on hand. I have no strong
design preference on the OLED as long as it can draw a small temp graph.
On Sun, Jul 30, 2023 at 1:06 PM Forrest Lee Erickson <
***@***.***> wrote:

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
--
Robert L. Read, PhD
Twitter: @RobertLeeRead @pubinvention
Public Invention: https://www.pubinv.org
Join Our Mailing list: ***@***.***
YouTube: https://www.youtube.com/channel/UCJQg_dkDY3KTP1ybugYwReg
Medium: ***@***.***

ForrestErickson, 2023-07-31:
Regarding Digikey source for Tac switch Lee got an email:

6/27/2023 10:33 AM
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

ForrestErickson, 2023-11-04:
@melanielaporte

A quick review please and then I think you can close this out with a few notes about how the PCB satisfies the requirements above.

melanielaporte, 2023-11-12:
Completed and discussed.

Closed 2023-11-12.

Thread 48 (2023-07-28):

What Batter / Power Supply To Use?  Power Tool?  Wall Supply?

ForrestErickson, 2023-07-28:
Power tool batteries may be common world wide?
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

Wall supplies too?

ForrestErickson, 2023-07-28:
@RobertLRead ,
What do you know or have sources regarding the availability of power tool batteries in low income locations?

The Dewalt batter and adapter converter above would be a way to use such batteries that may be common where ever building happens.

Please advise,
Lee
cc: @melanielaporte

RobertLRead, 2023-07-28:
I think this is an interesting idea. I assume these are at least as available as the 12V USB power banks which we were planning to use, and probably recharge faster.

However, we have to be careful if power tool batteries are not standardized wrt voltage. If we go above 12V, we probably need to carefully manage the duty cycle of the power, because we want the heating to remain gentle---you don't want any thing very hot inside the incubation chamber, even if eventually the heat will even out, because a hot spot can sterilize the sample.

Also, USB-based charging is equally ubiquitous. So I'm unless power batteries are highly standardized, I'm not sure there is much advantage here. For example, when I was in Tanzania in the larger towns (Kigoma) you could by a full range of hardware, and I'm sure you could get drills. BUT I don't know that any one brand is completely ubiquitous across different nations; and if multiple brands are not interchangeable, that doesn't help us.

@ForrestErickson @melanielaporte

melanielaporte, 2024-02-20:
@ForrestErickson @RobertLRead Does this topic need another discussion for PCB v2 design and order?

melanielaporte, 2024-09-18:
@ForrestErickson @RobertLRead Does this topic need another discussion for the next design generation design?

ForrestErickson, 2024-09-19:
Regarding, "Does this topic need another discussion for the next design generation design?"
I think not. At lease until we find that the batteries used by the Guadalajara team are hard to come by.

I suggest Melanie close this as will not fix.

melanielaporte, 2024-12-06:
Will not do.

Closed 2024-12-06.

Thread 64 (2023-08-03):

Added Fuse, Need PCB Footprint, 3D Model Too.

ForrestErickson, 2023-08-03:
I replaced the series resistor on the power supply input with a polyfuse (It self resets when allowed to cool).
A PCB footprint is needed. Will have to make.

From the drawing:
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

For the part BSMD1812-300-16V
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

ForrestErickson, 2023-08-03:
There is a place holder added to the PCB to remind us.

ForrestErickson, 2023-08-22:
FYI I have added this same part to the controller schematic for the NASA-COG .

melanielaporte, 2023-09-29:
Fuse has been added and committed. Done.

Closed 2023-09-29.

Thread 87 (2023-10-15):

Buzzer Hole Spacing or 3D Model Wrong

ForrestErickson, 2023-10-15:
The buzzer hole spacing appears to be wrong on the 3D view.

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

Does the PCB match the part?
Is the 3D render correct to the part?

melanielaporte, 2023-10-15:
Check updated buzzer PCB position.

melanielaporte, 2023-10-21:
10/21 We reviewed and confirmed that the error is ONLY the 3D model and the PCB spacing is 7.6mm.
GPAD was built with this buzzer - https://www.digikey.com/en/products/detail/soberton-inc/WST-1210T/16354828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
We are going forward with the GPAD.
I will order 5 assembles and 5 raw boards, and 10 buzzer parts as back ups and for experiments.

melanielaporte, 2023-10-21:
To do: Lee will make a new 3D model TBD.

ForrestErickson, 2023-11-04:
Found a model here: https://grabcad.com/library/buzzer-12mm-continuo-1

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

Loaded into PublicInvention Library.

@melanielaporte  will will need to connect the MoonratII with the Public Invention KiCAD library at some point. It is not cirtical for the order of PCBs however.

melanielaporte, 2023-11-12:
Changed buzzer manufacturer to
- Distributor 1 JCLPCB C360615
https://jlcpcb.com/partdetail/ss-SUN_12095_5VPA76/C360615#:~:text=Datasheet-,Download,-Source
and
- Distributor 2 Adafruit P1536A

ForrestErickson, 2023-12-01:
@melanielaporte
I do not remember fixing this and suspect you did.
The buzzer 3D model is now correct.
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

Did you fix it?

Regardless you may close this issue.

Closed 2024-02-20.

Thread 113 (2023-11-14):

Find another TMP for the PCB with more resolution.

melanielaporte, 2023-11-14:

ForrestErickson, 2023-11-14:
@RobertLRead

Can you reference the temperature tolerance requirement for the incubator materials of which you spoke during the meeting?
FYI, The TMP36 data sheet says +/- 2degreeC accuracy
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

CC: @melanielaporte

RobertLRead, 2023-11-14:
These instructions specify 35C  +-1 C:

https://www.neogen.com/globalassets/pim/assets/original/10044/34871738398_int.pdf

Here is the 3M E. coil interpretation guide:

https://media.neogen.com/m/3ddc380f58cfa4ed

On Mon, Nov 13, 2023 at 7:43 PM Forrest Lee Erickson <
***@***.***> wrote:

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

--
Robert L. Read, PhD
Twitter: @RobertLeeRead @pubinvention
Public Invention: https://www.pubinv.org
Join Our Mailing list: ***@***.***
YouTube: https://www.youtube.com/channel/UCJQg_dkDY3KTP1ybugYwReg
Medium: ***@***.***

HJGV05, 2023-11-17:
I have done some research on the best sensors for the application and here are my conclusions:
- It is important and necessary to change the TMP family sensor (TMP35-37) since its accuracy is ± 2°C above room temperature (see attached data sheet), which is not feasible since Petrifilm's datasheet (https://www.neogen.com/globalassets/pim/assets/original/10044/34871738398_int.pdf) mentions that the sample incubation should be 24 hours ± 2 hours at 35°C ± 1°C.
- The best commercial analog sensor that meets the specifications are the sensors from the LM family, specifically the LM35 (data sheet attached). This sensor is a precision temperature sensor whose accuracy is ± 0.5°C at 25°C and ± 0.25°C at room temperature. In addition, the operation current is less than 60-μA, so the maximum self-heating of the sensor is less than 0.08°C,  which translates to less sensor heating noise in the output signal.
- The LM35 sensor does not require prior calibration, the library and documentation on Arduino is very extensive and easy to find (https://www.arduino.cc/reference/en/libraries/lm35-sensor/ ) and does not interfere with the current PCB schematic. However, its only drawback is that it requires a higher operating voltage than the TMP family, the recommended supply voltage is 4 V to 5.5 V, but it can be powered from 4 V to 30 V. While this is not a drawback for the current schematic, it is an important note in case that in the future it is desired to work with low-energy devices (powered with 3.3 V).
- For the previous point, it is recommended in the future to change the analog port for an I2C port (or include it as an additional one) so that integrated sensors for temperature, humidity and pressure can be used, such as the BME280 (data sheet attached), which has an I2C communication protocol and a supply voltage of 1.7 V to 3.6 V, and whose library for integration into the Arduino system is available through the open source company Adafruit. For more information on temperature sensor comparisons, please see https://randomnerdtutorials.com/dht11-vs-dht22-vs-lm35-vs-ds18b20-vs-bme280-vs-bmp180/
- As a last point, I am concerned about 3M's requirements for the preservation of petrifilm samples before use, since they must be stored at a temperature less than or equal to 8°C, has there been any discussion about how this requirement will be met?

[bme280.pdf](https://github.com/PubInv/moonrat/files/13392409/bme280.pdf)
[lm35.pdf](https://github.com/PubInv/moonrat/files/13392411/lm35.pdf)
[TMP35.PDF](https://github.com/PubInv/moonrat/files/13392412/TMP35.PDF)

RobertLRead, 2023-11-17:
This is fantastic research, Horacio! I think adding an I2C port would be
nice, but it might change the wire harness, and I'm not sure we want to do
that. We might be able to survive with the LM35 for this version.

I keep my Petrifilms in the fridge. We can inform researchers to do the
same, but generally speaking I don't believe there is a problem with
leaving them at room temperature for a few days (that is, close to a human
being, which pretty much guarantees they won't get hotter than a human can
tolerate.) I don't believe it is a requirement of this project to address
that problem.

Someday someone may build a chamber that can both heat AND cool. That would
be a valuable scientific instrument but is about 20 times harder than what
we are trying to do.

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

--
Robert L. Read, PhD
Twitter: @RobertLeeRead @pubinvention
Public Invention: https://www.pubinv.org
Join Our Mailing list: ***@***.***
YouTube: https://www.youtube.com/channel/UCJQg_dkDY3KTP1ybugYwReg
Medium: ***@***.***

ForrestErickson, 2023-11-17:
Just thinking out loud.

### Arduino A2D
The Arduino UNO has an A2D resolution of 1023 steps. If the reverence voltage is the nominal 5V this is 5/1023 step or 4.89mV.

### TMP36 and TMP37
The TMP36 specification says 10 mV/C for the conversion. This implies our conversion step size is 4.89mV/(10mV/C) = 0.489 degree C.
The specification says -.5 degree linearity over the temperature range.
Could we simply calibrate each measurement device in an ice water bath and store the calibration in EEPROM?

The TMP37 has twice the gain so the temperature step size would be 0.244 degree C.
https://www.analog.com/media/en/technical-documentation/data-sheets/tmp35_36_37.pdf

### Arduino A2D Reference
Like many embedded A2Ds the resolution can be improved by matching the conversion range to the expected sensor analog voltage. From the TMP36 TMP37 data sheet we can see that even for temperatures as high as 50C the sensor output voltage is less than 1V.
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

If we bias the Artuino UNO reference input pin to for example 1/2 Vcc we gain an additional factor two temperature resolution so we might have 0.122 degree C step size.

### PCB Implications
@melanielaporte  This would require we add two resistors to divide the supply voltage in half and connect the result to AREF input on the UNO.  A 0.1 capacitor there would be well advised too.
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
HJGV05, 2023-11-18:
@RobertLRead
Sure, with pleasure. This type of 12-pin harness is usually used especially by the Pioneer brand (e.g. https://www.ebay.com/itm/190365766282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). However, I think it would even be a better option to use cables with IDC connectors like the ones mentioned by Mr. Lee, but in their 12 or more pins version. The reason for this is that they are affordable compared to the cables available on Amazon, for example, and they are accessible to the global market. For reference, Aliexpress, which ships to several places in the world, has configurations of both male and female-female harness connectors configurable from 6 to 22 pins and from 10cm to 50 cm at a very affordable cost. Specifically speaking, a 10-pack of 2X6-pin male IDC connectors (12 pins in total) costs 1.68 USD (plus shipping which can be free depending on the quantity, see for example https://es.aliexpress.com/item/1005002397737993.html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 ) while a 2x6-pin 30cm harness costs 1.75 USD plus shipping (same situation, see https://es.aliexpress.com/item/1005006154430582.html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). I think this configuration and supplier is very useful because it provides a distribution channel available in several parts of the world, a situation that may be different through Amazon USA.

RobertLRead, 2023-11-19:
This is good research --- but I will allow you and Lee and Melanie to make
the final decision on this.

On Sat, Nov 18, 2023 at 5:26 PM Horacio García ***@***.***>
wrote:

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

--
Robert L. Read, PhD
Twitter: @RobertLeeRead @pubinvention
Public Invention: https://www.pubinv.org
Join Our Mailing list: ***@***.***
YouTube: https://www.youtube.com/channel/UCJQg_dkDY3KTP1ybugYwReg
Medium: ***@***.***

ForrestErickson, 2023-11-19:
Regarding the choice of cables.
Our choice will impact what we do with the incubator.

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

If the incubator is an off the shelf soup thermos as Robert has suggested from time to time we have to penetrate the lid or the body of the thermos to pass the cable through.  There are consequences some what different to each decision.
If we degrade the insulation factor by penetrating the main body we have degraded the whole system to a greater extent.

If we penetrate only the lid there may be less degradation of insulation but the cables will be subject to handling and rotation every time the lid is put on and off the main body.

The compromises or trad off will be how the cable goes through what ever penetration we make. How it is strain relived. How it is sealed.

I have only vague ideas.

Inside the incubator something must hold the sample and the heater and the temperature sensor.

Again, I have only vague ideas.

There is also a battery and battery holder to figure in to all this.

Other:
The molded trailer cables connect between the controller enclosure and the incubator. The molded trailer cables can resist water.
The Audio cable connectors are open to the back. and would not resist water if used as a method of connecting/ disconnecting.

CC: @melanielaporte

RobertLRead, 2023-11-19:
The problem of the lid twisting is solvable by twisting the body, not the
lid.

On Sat, Nov 18, 2023 at 10:50 PM Forrest Lee Erickson <
***@***.***> wrote:

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

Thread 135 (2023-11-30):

KeyCap Footprint, JLCPCB Required Changes for BOM and Placement Not Saved on 20231129

ForrestErickson, 2023-11-30:
@melanielaporte

I have refreshed my fork and updated my local clone. I opened the schematic and examined the KeyCap properties.

The changes you made to the footprint on the key cap to resolve the JLCPCB order problem did not get saved.
The footprint still says: See JLCPCB assembly notes for footprint
Where IIRC you ware changing this field to the manufacturers part number to clear that JLCPCB order problem

See:
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

I think it is that when you were editing in the Symbol Fields Table you did not prese the Apply Save & Continue button before pressing OK to close the dialog.
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

melanielaporte, 2023-11-30:
What appears in my Kicad
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

melanielaporte, 2023-11-30:
Uploaded JLCPCB files are located in [issue #132](https://github.com/PubInv/moonrat/issues/132)

ForrestErickson, 2023-12-01:
20231201 I again refreshed my fork and clone.  I had to resolve a file conflict (the step file for the TS6-THT-SQ.step.
Then a bunch of files came in.
Now when I open the the change is there.
I can only conclude that I did not properly refresh my fork before not noticing the conflict.

I have success!
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

Closing.

Closed 2023-12-01.

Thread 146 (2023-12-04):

Firmware, Add and Report I2C Address Scan at Boot

ForrestErickson, 2023-12-04:
The firmware should help identify hardware faults where possible for both manufacturing users and end users.

The firmware should scan the I2C bus for all devices and report those found on the serial UART (USB) port.
The Arduino UNO example libraries has an I2C scan sketch from which to star code.

The firmware of the GPAD has such or similar feature.
The firmware of the GPAD factory test has some additional features for consideration

ForrestErickson, 2023-12-16:
The OLED is an I2C device.

HJGV05, 2023-12-26:
Good day, it is a good idea to perform a diagnostic and component fault test script. However, I think it would be better to create a separate firmware that the user can run on the board, we can make a diagnostic script that reads and displays all the I2C components connected, check the temperature sensor reading, allow the use the buttons, send a small PWM output signal to test the heater setup and emit some test sound for the buzzer so that it is simple and light to implement without adding more complexity to the main program interface for the incubator, do you like this idea?

ForrestErickson, 2023-12-26:
@HJGV05

Regarding, ", I think it would be better to create a separate firmware that the user can run on the board,"
Yes a separate "**Factory Test**" firmware is likely to be of value because the user experience can be optimized for the factory test process.

There is a possibility that a **Trouble Shooting** test firmware is also needed for some kinds of problems. I have from time to time coded up special firmware focused on helping to diagnose problems. Such firmware is often trying to make seeing a problem with an oscilloscope possible.

I have just added some folders into which such work can be placed.

Closed 2024-02-20.

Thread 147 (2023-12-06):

Related to Issue #55: JLCPCB V-cut requires a larger board dimension

melanielaporte, 2023-12-06:
The problem: changing the PCB/assembly board width will change the enclosure dimensions.
Please update the schematic in Kicad and send new schematic drawing to the enclosure team.
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

ForrestErickson, 2023-12-06:
This will be fine as the added rails are also V cut (Assuming I understand what I see) We (Melanie) will simply snap them off.

Since this is my first work with V-CUT as a designer I am learning.

Closed 2023-12-06.

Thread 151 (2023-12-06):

Test project management board

melanielaporte, 2023-12-06:
?prj ? Project?

ForrestErickson, 2023-12-16:
?prj ?  Project?

Notice how in the GPAD project at the Hardware folder where there is a README.md page that describes the files in the folder.

> https://github.com/PubInv/general-purpose-alarm-device/tree/main/Hardware

One of those files is

> [Manufacturing Documentation for Version 2 PCB](https://github.com/PubInv/general-purpose-alarm-device/blob/main/Hardware/Documentation/ManufacturingUnitTestTroubleshootingRev2.md) Details how to assemble the Printed Wiring Assemblies as received from JLCPCB version 2 PCBs of March 2023. Includes testing and troubleshooting notes.

That is an example of the notes on finishing assembly and testing Lee made for the GPAD assemblies.

ForrestErickson, 2023-12-16:
Here is another Factory Test document under development now:
# Factory Test Plan, Control V1.1, Printed Wiring Assembly
Journal of tests for assemblies of October 2023.
PCB assembly by JLCPCB with some finish work in Maryville TN.
Five Assemblies assigned SN 9-14.

Notes made in issue #89 during the development of this test plan.

## Resources
12V power supply with current monitor.
Multi meter to measure voltage and resistance.  (Actual Multimeter (EMCO DMR-3800) )
PC with Arduino IDE to connect to USB programing port of Due
Firmware: https://github.com/PubInv/NASA-MCOG/tree/develop/elec/Control%20Board/Control_1v1/FactoryTest
Arduino Sketches:
1. DueWithThreeSSRs
2. GraphicsTest

## Test Procedure
### Before Test, Finish Assembly
Install on these units the feed through headers for the Due connections which make this assembly become a shield for a Due.

### Unpowered Test of PWA.

Summary and data capture table

Tester Name ____ F. Lee Erickson ________________
Date of Test _____ 20231026 _____________________

| Test ID 	| Test Name       	| Setup                                          	| Test Location 	| Requirements    	| Results SN 9 	| Results SN 10 	| Results SN 11 	| Results SN 12 	| Results SN 13 	|
|--------:	|-----------------	|------------------------------------------------	|---------------	|-----------------	|--------------	|---------------	|---------------	|---------------	|---------------	|
|       1 	| Inspection      	| Inspect correct orientation on polarized parts 	|               	|                 	|      D1 and D2 Probably backwards. |               	|               	|               	|               	|
|       2 	| +24 In No Short 	| Set ohm meter 20M. Com to GND                  	| TP20 (J12 Pin 1)   	|  > 10K 	|  34.6K  	|  34.6K        	|     34.5K  	|  34.6K       	|               	|
|       3 	| +12 In No Short 	| Set ohm meter 20M. Com to GND                  	| TP 2 (J11 Pin 1) |   > 10K 	 |    39.8K |  39.9K      	|   39.8K         |   39.8k      	|               	|
|       4 	| 5VHEAD net      	| Set ohm meter 20M. Com to GND                  	| J8 Pin 1 | Open or > 1 Meg 	|     Open |       Open   	|      Open     	|      Open   	|               	|
|       5 	| +5V net         	| Set ohm meter 20M. Com to GND                  	| J3 Pin 4 | Open or > 1 Meg 	|     12.1 Meg |      Open   	|        Open 	| 2.4K (Issue #126 https://github.com/PubInv/NASA-MCOG/issues/126) |       	|
|       6 	| +3.3V net       	| Set ohm meter 20M. Com to GND                  	| J3 Pin 5 | Open or > 1 Meg 	|   11.7 Meg |         Open    	|         Open     	|         Open     	|               	|

### Program Due with Firmware
Before connecting to the Controller V1.1 Assembly, program the Due with Load the factory test firmware "MAX31850_Tester.ino"

## Finish Assembly

#### Build Up MAX31850 Thermocouple Amplifier Sub Assemblies
Note that the side of the board to be up has the pads for configuring the addresses of the assemblies.
Cut the on board shunt on each MAX31850 PCB. Measure with multimeter that the shunt to GND is open.
Solder the header and screw terminal to the MAX31850 on the correct side.

1. Install the MAC13850 thermocouple amplifier assemblies to the Control V1.1 at JP9, JP10 and JP15.
Add a ?2.5mm? x 10 mm screw with nut as mechanice support and retention.
Observing polarity, connect thermocouples to the MAX31850 amplifire assemblies.
**NEED IMAGE HERE**

2. Added legs (8-32 x 2") with nuts.
3. Solder in the Due connectors, seven locations.  The long tails must go in the top and through to the bottom
4. Connect the Due to the Controller assembly.  The Due is under the Controller V1.1 assembly as a "shield".
5. Connect the Ethernet W5200 (or similar) sheild on the top of the Controller V1.1

### Apply power.
Note the +12V, the +24V and the Stack programable power supply are connected to a switchable outlet switch.
With the power outlet off,
Connect the +12V power at J11.
Connect the  +24V power at J12.
Connect SSR simulator LEDS at  SSR1, SSR2, SSR3.
??? Do not connect the Stack power supply at J10 ( or J27) at this time. ???

Apply power by switching on the AC power strip.
**Test ID7:** Note current in table on the +12V supply current monitor for excessive, above 100 mA.  THIS NUMBER WILL NEED TO BE CHECKED WITH DUE's THAT HAVE NEVER BEEN PROGRAMED.
Check that the BUILDIN_LED ner the LAN Shield and SSR2 and SSR3 connectors is blinking rapidly as an idication that the firmware is running.
Open the Arduino Serial Plotter (<Ctrl> <Shift> <L>) and touch some thermocouples.
### Temperature Measurements.
**Test ID8:** Typical Serial Plotter results. Touching some of the thermocouples to ensure they respond.
Note resutls in table
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

**Results continued...**
| Test ID 	| Test Name  | Setup | Test Location | Requirements  | Results SN 9 | Results SN 10 | Results SN 11 | Results SN 12 | Results SN 13 	|
|--------:	|------------ | -------- |---------- | ------------	|--------------	|----------	|----------- |--------------- |--------------- |
|      7 | Current, Temperature Only  | In line DC current meter |    Due input |  85 mA |             |             |             |         |
|      8 | Check thermocouples  | Connect three |   Serial Plolter |  Three traces |   OK   |             |             |             |         |
|      9 | future use  |  |      |               |             |             |             |         |            |

Load and run factory test firmware DueWithThreeSSRs.ino
Open the Arduino Serial Monitor. Observe the data.
**Test ID10**  Observe SSR1, SSR2, SSR3 LED Blinking.
**Test ID11** Observe Mini12864 Display back lit and displaying splash message and four measurements.
**Test ID12** Encoder Rotation Knob is back lit. Rotate the know and observe the serial port reporting changes.
**Test ID13** Encoder knob switch. Press the knob and observer serial port message about shutdown.
**Test ID14** PCB mount SHUT DOWN button. Press the button and observer serial port message about shutdown.

**Results continued...**
| Test ID 	| Test Name  | Setup | Test Location | Requirements  | Results SN 9 | Results SN 10 | Results SN 11 | Results SN 12 | Results SN 13 	|
|--------:	|------------ | -------- |---------- | ------------	|--------------	|----------	|----------- |--------------- |--------------- |
|      10 | SSR1, SSR2, SSR3 LED Blink  |  |      |               |             |             |             |         |            |
|      11 | Mini12864 Display           |  |      |               |             |             |             |         |            |
|      12 |Encoder Rotation Knob        |  |      |               |             |             |             |         |            |
|      13 |Encoder knob switch          |  |      |               |             |             |             |         |            |
|      14 | PCB button SHUT DOWN        |  |      |               |             |             |             |         |            |
|      15 | LAN CONNECTION              |  |      |               |             |             |             |         |            |
|      16 | Stack power to load         |  |      |               |             |             |             |         |            |
|      17 | Cumulocity reporting        |  |      |               |             |             |             |         |            |
|      18 | PxxxxxxxxxxxxxxxxxN         |  |      |               |             |             |             |         |            |

### Add Stack Power Supply Control
With power off.
Connect at J10 with power supply which has a load.
Load the OEDCS firmware into the unit under test.
Open the serial monitor.
Apply power to Stack power supply and +24V.
Observe the voltage on the load.
On serial port monitor confirm device connects to LAN
On serial port monitor confirm device current and voltage on stack load is normal.
Observe data on Cumulocity

Rejoice another great OEDCS has been born!

Closed 2024-02-20.

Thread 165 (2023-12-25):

Enclosure Top, PCB Mount Screw, Needs Definition

ForrestErickson, 2023-12-25:
Just trying to give you all a view into what I am doing.

Lee is trying to mature the FreeCAD enclosure some what more.  I have not finished a detail of the mounting of the PCB, the hole size and screw.

I have sketched out an enclosure which will mount the PWA (Printed Wiring Assembly), on the four corners but I have not worked on the details to get screws to engage the plastic mounting feature.

Here is the PCB mounting hole detail showing **3.5 mm** hole.  And a 7 mm diameter copper pad.
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

So I need a screw smaller than 3.5 mm (0.138")  Because I have had a carrier in the USA I often am forced to work in inch hardware so I do the conversion and note that a 1/8 screw might be a candidate. So I look for standard screw sizes
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
The #5 screw would have 1/8" OD (Outer Diameter). HOWEVER #5 screws are not common. #4 and #6 are common in the USA.

Since we hope MoonRat II will be use world wide perhaps a 3mm screw is best.  Procurement is more unusual, but I do have some and the length is not going to be unusual.  Available here for example: https://www.lowes.com/pd/Hillman-3mm-0-5-x-10mm-Phillips-Drive-Machine-Screws-12-Count/999994826  3-mm 0.5 x 10-mm Phillips-Drive Machine Screws

So I need the enclosure mount hole to receive the 3mm screw.
This chart gives insights I must have a hole which leaves some room for the flow of material displace by the threads.
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
If I take the average of the screw inner and outer diameter I get 5.675/2= 2.84mm.
So 2.84mm will be my first guess.

I update the enclosure design from 5 mm screw to 5 mm screw. (And the outer diameter to 7mm)
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
to
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

HOWEVER a better design will use a screw designed to engage plastic.
This reference is helpful: https://www.stanleyengineeredfastening.com/-/media/web/sef/resources/docs/other/threaded_fasteners_for_plastics.ashx
If I design for the "Delta PT 30"  the inside diamter goes down to 2.1 mm per this table:
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
This screw can be purchased from McMaster Carr:
[96817A322](https://www.mcmaster.com/96817A322)

ForrestErickson, 2023-12-26:
I have requested FreeCAD advise on how to constrain the sketch for the counter bores from the Facebook group at:
https://www.facebook.com/groups/416491481766626

Here in an assembly drawing is the detail on which I am asking advise.
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

ForrestErickson, 2023-12-27:
I have received some interesting suggestions from Facebook.

> Use the Hole tool instead of the Pocket tool. The Hole tool will let you create a variety of threaded holes with counterbore, countersink and more. Use the sketch you made for the holes and align the plane to the top of the post. Draw circles centered on top of each post, size doesn't matter. Select the hole tool and work thru the dialog to create the thread.

Closed 2024-02-20.

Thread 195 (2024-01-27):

Make +12 Trace Heavy, Version 2 PCB

ForrestErickson, 2024-01-27:
### Problem Description
This trace for power is too thin.

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

### Fix in Version 2.
Make it 0.040 inch wide.

### Rework for Version 1.
Add a wire from TBD to TBD

ForrestErickson, 2024-03-02:
Working in a branch Lee has done so.

### Layers
Top
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

Bottom
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

Closed 2024-03-02.

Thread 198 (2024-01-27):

Add Arduino UNO Stackable Header to JLCPCB BOM

ForrestErickson, 2024-01-27:
A labor intensive activity of the MoonRat II build of 2023 is adding "stackable headers" on the UNO connection pins.

To make the MoonRat II Printed Wiring Assembly more complete, we should add "stackable headers" to the BOM.

A search on JLCPCB for "stackable headers" produced this result with four hits but zero stock
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

ForrestErickson, 2024-01-27:
### Parts at JLCPCB but not in stock
**Compare PartDescription Manufacturer Stock  Price**

PRT-14311
ESP32 Thing Stackable Header Set
Extended Part
Sparkfun Electronics
0
1 + $0.0365

PRT-09280
SparkFun Accessories Arduino Stackable Header - 6 pin
Extended Part
Sparkfun
0
1 + $0.0365

PRT-11376
SparkFun Accessories Arduino Stackable Header - 10 Pin
Extended Part
Sparkfun Electronics
0
1 + $0.0365

PRT-09279
SparkFun Accessories Arduino Stackable Header - 8 Pin
Extended Part
Sparkfun
0
1 + $0.0365

ForrestErickson, 2024-01-27:
Lee sent email to JLCPCB on 20240127

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

ForrestErickson, 2024-01-27:
### Sent message to LCSC components

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

ForrestErickson, 2024-01-29:
Got reply from JLCPCB

```
01/28/2024 10:12 PM EST JLCPCB Support <[support@jlcpcb.com](mailto:support@jlcpcb.com)> wrote:

Dear Customer,

Thank you for your inquiry. In general, we recommend that customers choose their own components.

We have a variety of components available for soldering. By entering relevant keywords related to the components you are looking for, you will be able to browse through our extensive catalog and choose the most suitable options based on your requirements. Please visit this link: https://jlcpcb.com/parts.

Should you encounter any difficulties or require further assistance during your search, please do not hesitate to contact us.

Thank you for your understanding.

Best regards,

Kiki
```

Sent the further request.

```
Hello JLCPCB Support,
Thanks for getting back to me.

Regarding, "we recommend that customers choose their own components."
We would like to use parts already in your system so as to not increase your part number complexity.

These are parts in your system most interesting.
PRT-09280
PRT-11376
PRT-09279
Are this parts a mistake ?  I know how hard it is to keep mistakes out of part systems. If that is so tell me please.

For your information, I have tried to contact LCSC components with the same question.

However they have not yet replied to my request.

So can I choose: Arduino Stackable Header Kit - R3, PN: PRT-11417
https://www.sparkfun.com/products/11417
?

Please advise
Thanks,
(Forrest) Lee Erickson
CC: MoonRatII team.
```

ForrestErickson, 2024-01-29:
Email from JLCPCB Support

```
From: JLCPCB Support <support@jlcpcb.com>
To: Forrest Erickson <forresterickson@comcast.net>
Cc: roy@jlcpcb.com, ml5046@columbia.edu, read.robert@gmail.com
Date: 01/29/2024 7:37 AM EST
Subject: Re: New offline message [LC #12327960.S7IXP2V2NW]
Dear Lee,

Thank you for getting back to us.

Unfortunately, the three parts you are interested in are currently unavailable at JLCPCB.

We apologize for the lack of availability for your request.

For components that are out of stock in JLCPCB or LCSC Parts, please proceed to purchase them from Global Sourcing Parts or submit a request as outlined below. Kindly note that the process may take approximately 9-15 days.

Alternatively, you can choose to replace the out-of-stock components with other feasible options in https://jlcpcb.com/parts.

Thank you.

Best regards,

Kiki
KIKI Chen
Web:	JLCPCB.COM
Email:	kiki@jlcpcb.com

```

foo
bar

ForrestErickson, 2024-01-29:
Lee sent email to JLCPCB.

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

melanielaporte, 2024-03-02:
Removed from v2 because of long lead. Schematic unchanged.

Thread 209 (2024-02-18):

Notes on Assembly of MoonRatII Version 1.0 PWA

ForrestErickson, 2024-02-18:
## Capture notes on the assembly process in an issue as I go.
This can be put into a README.md or other markdown document later.
This content will be good for the Hardware X article.

### Load Blink sketch into IDE
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

### Select the COM port
You can see the COM port appear using the Windows Device Manater.
#### Before connecting the USB port
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

#### After connecting the USB port
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

Under Tools, Port: select the appropriate port.
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

Under tools, Board select the Board Manager, Arduino AVR, Arduino Uno
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

Select, Get Board Info and capture to **TBD???**
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

Press the Upload icon .
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

There is a green progress bar in the Status lower right.
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

The Status will show Done Uploading when finished.
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

ForrestErickson, 2024-02-18:
Each assembly will "enumerate" with a different COM port.   For these MoonRatII assemblies on the factory test computer this will become an opportunity for confusion as the device count increaset.
The first device became COM 10.
The second device became COM12.
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

ForrestErickson, 2024-02-18:
Place the MoonRatII shield on the UNO.

**SPECIAL NOTE**
The genuine Arduino UNO has a Type B USB connector which is big enough to interfere with the MoonRatII PCB and short against the switch SW1 pins.
Trim the pins flush as you can.
With vinyl tape, insulate the pins from touching the USB connector.
The USB connector prevents the MoonRatII from fully seating into the headers.

Future purchases should be of UNOs with the micro USB connector to avoid the possibility of electrical short and mechanical interference.

ForrestErickson, 2024-02-18:
## Check Against Power Short
Measure resistance to ground on power Jack J1
SN 01 19.9K
SN 04 19.9K

Plug into USB cable, power from USB.
The buzzer is buzzing and the amplitude changes with proximity of my fingers.
LED is blinking
No smoke signals.

Plug into wall transformer with current monitor
SN 01 50 mA
SN 04 50 - 70 mA depending on how loud the buzzer is.
No smoke signals.

ForrestErickson, 2024-02-23:
@RobertLRead
FYI there is an issue into which I was capturing my testing of Version 1.0 PWAs.

ForrestErickson, 2024-03-26:
In March Resume testing.
Lee connected the heater assembly to the SN01 and SN04 with a ribbon cable.
Lee connected the heater pad THROUGH A 100 OHM RESISTOR to the screw terminals at Heater assembly J1. This 100 Ohm resistor is to prevent the assembly from drawing more than the current the USB can supply (100 mA).

### Run Firmware.
Lee verified that:
On release of reset the display had the public invention splash screen.
Splash screen was followed by display of firmware version.
Then the SELECT SAMPLE menu came up.

Lee selected the Yeast and mold and pressed SW2 (Enter?)
The display began showing a graph of temperature.

I do not think the temperature is correct.

ForrestErickson, 2024-03-26:
Some of this work should be captured into the README.md article which forms a manufacturing test for Version 1 Assemblies.
See:
https://github.com/PubInv/moonrat/blob/main/moonratII/pcb_moonratII/manufacturing_test/README.md

melanielaporte, 2024-09-18:
@melanielaporte

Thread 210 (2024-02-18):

Future Purchase UNO with micro USB connector, Short to SW1 and Interference with Board

ForrestErickson, 2024-02-18:
The genuine Arduino UNO has a Type B USB connector which is big enough to interfere with the MoonRatII PCB and short against the switch SW1 pins.
Trim the pins flush as you can.
With vinyl tape, insulate the pins from touching the USB connector.
The USB connector prevents the MoonRatII from fully seating into the headers.

Future purchases should be of UNOs with the micro USB connector to avoid the possibility of electrical short and mechanical interference.
For example see: https://www.makertechpr.com/product-page/arduino-uno-r3-micro-usb-8-analog-inputs

Modify bill of material.

melanielaporte, 2024-03-02:
Change the schematic to an Uno with smaller micro USB connector.

ForrestErickson, 2024-03-02:
20240301 Changed the Schematic.

Closed 2024-03-02.

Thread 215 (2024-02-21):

Pushing SW1 crashes the UNO, and seems to draw too much current at the same time.

RobertLRead, 2024-02-21:
When I press teh SW1, the system resets. My Mac, which has an intelligent USB, shuts off the USB saying that it drew too much power.

I can see no reason why looking at the schematic. I am trying to understand by studying the PCB.

RobertLRead, 2024-02-21:
Checking with my multimeter, the resistor is indeed a 1K ohm resistor.

RobertLRead, 2024-02-21:
This was solved by adding electricians tape to the large square USB connector. I believe the shield was shorting against it. This is a fairly common problem with Arduino Shields.

I do not know precisely what action sould be taken here. I belive the card should cover that part of the UNO at all, and the barrel jack should be moved to the other side.

melanielaporte, 2024-02-21:
Ok, Lee and I will address the issue this weekend. You are welcome to attend.

ForrestErickson, 2024-02-21:
I too had found this and had been making photos and notes.
A solution will be to purchase UNOs which have the micro USB connector. The offical Arduino UNOs come with the large Type B connector which causes this problem.
The inexpensive clones can be purchase with the miro USB.
For example
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

ForrestErickson, 2024-03-02:
Updated schematic for the Aliexpress part above.

Closed 2024-03-02.

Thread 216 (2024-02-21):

ECO, Moonrat II Controller PCB version 1, Jumper D8 D10

melanielaporte, 2024-02-21:
## Summary
Change for PWM into Heater Transistor Q1.
The PID algorithms produce an analog (PWM) control signal. The Pin D8 is GPIO only.  D10 is an unused pin which supports PWM.

###  Hardware Rework
For circuit board Version 1.0: Add a jumper wire from D8 to D10

### Firmware Change
Change firmware to support PWM on pin D10.
**CAUTION: To prevent contention, Pin D8 MUST remain high impedance (INPUT).**

ForrestErickson, 2024-02-21:
### Configuration Records
Record here, by serial number of the MoonRatII Version 1 PCBs for the Jumper D8 to D10 rework.

| **Serial #** 	| **Disposition** 	| **Date of Rework** 	|
|--------------	|-----------------	|--------------------	|
| 1            	| Lee             	| 20240220           	|
| 2            	|                 	|                    	|
| 3            	|                 	|                    	|
| 4            	| Lee             	| 20240220           	|
| 5            	|                 	|                    	|

ForrestErickson, 2024-03-02:
20240301 Update schematic and Version 2 PCB.

Closed 2024-03-02.

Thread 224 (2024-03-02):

Order Rev 2 PWA and PCBs,

ForrestErickson, 2024-03-02:
## Files to Generate
- [x] Review Design for Manufacturing JLCPCB
- [x] Schematic Rev v2 PDF
- [x] PCB Rev 2 PDF
- [x] Update the [KiCanvas links](https://github.com/PubInv/moonrat/tree/main/moonratII/pcb_moonratII) to the live viewer (Kicanvas), schematic and PCB
- [x] Generate BOM (Bill of Material),  Break in to sub BOMs for JLCPCB, DigiKey, Aliexpress, Other.
- [x] Generate 3D files of PWA (Printed Wiring Assembly) (With and without the UNO?)
- [x] Export gerber and placement files (for JLCPCB)
- [x] Review gerber files
- [x] Order JLCPCB
- [x] Order Digikey
- [x] Order Aliexpress
- [x] Order Other?

ForrestErickson, 2024-03-02:
Review for Manufacturier requirements
KiCad before setup
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

ForrestErickson, 2024-03-02:
## Verify that the TMP36 is out put values that make sense.
At room temparature of about 73 degrees we had 0.75 V

Here is a graph where about mid way Lee pinched the TMP36 between fingers and the output rise a bit.
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

### Conclusion
The TMP36 is wired correctly

melanielaporte, 2024-03-16:
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

melanielaporte, 2024-03-16:
@ForrestErickson
We have changed the Uno type from Uno to R4 Minima. 6 R4 were ordered 20240316 for the Rev 2 prototypes and shipped to GDL team.
Future plans: order R4 for the US team as they are still working with the old Unos.

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
cc: @RobertLRead

Closed 2024-09-25.

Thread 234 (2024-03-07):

Rev 2 MoonratII Boards and Assemblies Order Information Capture 20240307

melanielaporte, 2024-03-07:
1. Our previous order #W20231130095 required an additional $25.29 for the v-cut.
This order, we have selected 2 boards, Paneled by Customer.
We would like the PCBs and assemblies to be similar to our previous order
2. MF12 (1x4 header) should be soldered to J2 (OLED display)
3. MF 4-6, 8 (round nuts) mounted to OLED display

If additional payment required, please advise.

melanielaporte, 2024-03-07:
Things necessary to make a successful order not obvious to a beginner
Uploading the .... files, Selected Research development
Friday - do a dummy order, screen capture each step @melanielaporte

melanielaporte, 2024-03-16:
JLCPCB email
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

melanielaporte, 2024-03-16:
Our response
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

melanielaporte, 2024-03-16:
JLCPCB email 20240316
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

melanielaporte, 2024-03-16:
@ForrestErickson

melanielaporte, 2024-03-21:
Issue with JLCPCB order: due to the PCB being ordered Economy instead of Standard board, added the v-cut is not possible.

@ForrestErickson There are 2 options. Which should we choose?
1. Go forward with the Economy PCBA Rev 2 order, requiring the GDL team to cut the board manually.
2. Cancel the Economy {CBA Rev 2 order and purchased a Standard Rev 2 PCBA today April 21st.
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

melanielaporte, 2024-03-23:
Doing it right now, will keep the team informed.

melanielaporte, 2024-03-23:
@ForrestErickson The site is down tonight, I will order in the morning, 03/23/2024.
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

melanielaporte, 2024-03-24:
New PCBA order has been placed, invoice sent.

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
@RobertLRead @ForrestErickson

ForrestErickson, 2024-03-25:
@melanielaporte
Can you summarized here the cost delta so we remember? IIRC it was not much but we should know that the "V" cut is a distinct cost in addition to the component and board and assembly costs.
Can you please  itemized this cost in the Hardware X article too?

If we had plenty of free time we could even make a copy of the MoonRatII schematic and PCB and break into two schematics and two PCBs. One each for the Controller and the Heater assembly and then work up an order with JLCPCB for the two assemblies seperate. Another order with the two assemblies "Panelized" to further understand the cost implications.

CC: @RobertLRead

melanielaporte, 2024-03-26:
JLCPCB production is finally a GO!

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

Closed 2024-09-25.

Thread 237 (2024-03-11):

Ship PWA to Harshit, enclosure design

melanielaporte, 2024-03-11:
Adding @harshit9602  to bring him into the loop.

melanielaporte, 2024-03-11:
@ForrestErickson Should I include a raw board and all components?

ForrestErickson, 2024-03-12:
Regarding, " Should I include a raw board ..."
Yes because it may be useful.

Regarding, "and all components?"  I am not sure what you mean.
Do you mean, " and a full printed wiring  assembly?".  The answer is yes. because testing fit for an enclosure needs components on the board to check for fit to the display and buttons and buzzer and against interference with all of the connectors.

And we should be examining our assumptions.  Will our enclosure designer have everything needed for representative testing?  Correct key caps is an important part of that but not the only part.
For the Rev 2 PWAs the big transistor Q1 has moved slightly to the left relative to the Rev 1 PWA.

Finally, if you can, You should solder a wire onto the PCB to improve the current carrying capability on the VCC net.
I will try to do so some time today but I have several zoom meetings and a telescope to the library activity this afternoon competing for my time.

Do you have some wire with which you could try to improve the connection from the down current side of the fuse, F1 to a connection near J6 pin 2?
This will require you to scratch off the green PCB coating called solder resist to solder to the surface of the copper trace near J6 pin 2.  A great thing to learn how to do and not obvious.

@harshit9602 Do you have the ability and tools to solder wire to PCB traces?

melanielaporte, 2024-03-16:
@ForrestErickson Soldered wire to PCB traces for @harshit9602's Rev 2 PWA set.

Closed 2024-03-16.

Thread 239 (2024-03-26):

Cell Phone Interference with Temprature Measurement, Rev 1 Assemblies

ForrestErickson, 2024-03-26:
Lee discovered that placing a cell phone near the cable connecting the controller and heater causes the measured temperature to be in error.
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

RobertLRead, 2024-03-26:
Interesting. Can this be fixed with shielding?  Should one move to a
digital temperature transmission?

On Tue, Mar 26, 2024 at 5:51 AM Forrest Lee Erickson <
***@***.***> wrote:

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

--
Robert L. Read, PhD
Twitter: @RobertLeeRead @pubinvention
Public Invention: https://www.pubinv.org
Join Our Mailing list: ***@***.***
YouTube: https://www.youtube.com/channel/UCJQg_dkDY3KTP1ybugYwReg
Medium: ***@***.***

ForrestErickson, 2024-03-26:
Regarding, " Can this be fixed with shielding?"

This morning I am not able to reproduce the problem.

No idea if the cell phone operation is some how different or something else.
The wires on my work bench are a rat's nest. I have not moved them much but some movement has happened with out a doubt.
Not sure where my arms need to be for example.

Just not sure what do try to make further testing and make the problem repeatable.

ForrestErickson, 2024-03-26:
I have configured my oscilloscope to measure the AC waveform on the A0 input.
Because it is a small signal the ground bounce (interference may be non trivial so I made a two channel differential measurement.

The red (Math) channel is A0 - Ground and so the ground hum (interference) is removed.
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

There are occasionally much greater bursts of interference than I captured here.

ForrestErickson, 2024-03-27:
## More investigation.
I made a phone call and observed interference.

Interference in measurement
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

Oscilloscope waveform. NOTE the vertical scale is significantly different on this measurement.
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

RobertLRead, 2024-09-25:
This MAY be irrelevant now that we have moved to using a digital thermometer. However, we should retest, so I am leaving this open.

Closed 2025-08-29.

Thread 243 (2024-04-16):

Wires problem

SilviaKarbid, 2024-04-16:
We have doubts about where to connect the cables we received because they are too large to connect to the PCB.
1. Are the screws in the image for the edge of the PCB or for the screen?
2. If they are for the screen, they seem a bit small.
3.The pins to solder to the PCB are missing. Do they come in the missing package or would you like us to purchase them here?
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

RobertLRead, 2024-04-16:
I think @ForrestErickson or @melanielaporte will have to answer this.  I assume we can discuss it tonight.

RobertLRead, 2024-04-16:
recall that the idea is that the cable be cut in half, and the presumably the cut halfs connected to the board (one side) and the heater appliance (on the other), with the male and female ends becoming a means of coupling and decoupling them.  Is it possible that the screw-clamp connector on the main board is meant to serve that purpose?

ForrestErickson, 2024-04-17:
## Choice of which cable
I remind everyone that the automotive lighting cable can be used OR the flat ribbon cable may be used but we should chose one or the other. They each have positive and negative consequences for ease of assembly and the strain relief which must be designed into the enclosure.
I assert we must fabricate and evaluate a design for each type of connection.

### To use the automotive lighting cable
The cable is to be cut in half. The wires may be too thick for all of the strands to fit into the screw terminals. I have not tried it  yet. If you can try let us know.
Some strands must be sacrificed till what remains fits.

Because power will be coming from the control assembly, it is important that the half of the cable with this end (pictured)
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
the end where all but one terminal is surrounded by insulation, be wired to the control board such that ground is the single exposed pin.  This is so that power can not be shorted  due to an accidental touch of the cable to anything.

The rest of the wiring must simply be the same on both the control assembly and the heater assembly.
The wiring must be documented so that we wire every single control assembly and heater assembly the same so that they are all interchangeable.

The other end of the cable with the five exposed contact pins is wired to the heater assembly.

## A "To Do"
Document the wiring when using the automotive lighting cable.

ForrestErickson, 2024-04-17:
Regarding, @harshit9602  statement, "Are the screws in the image for the edge of the PCB or for the screen?
If they are for the screen, they seem a bit small."

The intent is for screws to attach the screen. Please try them and get back to us on the fit.

ForrestErickson, 2024-04-17:
Regarding, @harshit9602 statement, "3.The pins to solder to the PCB are missing. Do they come in the missing package or would you like us to purchase them here?"

There are supposed to be headers with long pins soldered where indicated here.
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
@melanielaporte can you identify the part number and the Amazon link for purchasing these parts.

**Problem?**  IIRC Harshit does not have equipment with which to solder?

SilviaKarbid, 2024-04-18:
> The intent is for screws to attach the screen. Please try them and get back to us on the fit.

The screws are thin and don't fit the screen, but since the screen is soldered to the board, I think for now it can be left like this

ForrestErickson, 2024-04-18:
Hello @harshit9602 ,
Can you measure the OD of the screw thread?
Can you measure the ID of the threaded insert?

For the threaded insert, here is the data sheet: https://wmsc.lcsc.com/wmsc/upload/file/pdf/v2/lcsc/2205251700_Sinhoo-TH162050CTJ_C3020130.pdf

From the drawing I infer a 2M screw should work. See detail here:
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

Please advise.

harshit9602, 2024-04-18:
I dont think I follow what you are trying to ask. My approach right now is to design the enclosure that fits everything and then find a screw that would hold it in place and not the other way around. Also, i dont have calipers to measure OD and ID of screws

ForrestErickson, 2024-04-21:
@harshit9602
Regarding, "I dont think I follow what you are trying to ask."
I was trying to figure out if the screw is wrong or the mounting hole is wrong. The intent is for both to be 2M.
Of course something else may be wrong and we are miscommunicating.
A photo would help.

Thanks,

ForrestErickson, 2024-05-10:
Regarding "We have doubts about where to connect the cables we received because they are too large to connect to the PCB."

The screw terminals are on a 0.1" spacing.
A larger screw terminal on a 0.156" spacing may work better for the heavy gauge wire, but of course is a PCB redesign.

Here is an example of such a screw terminal:
https://www.aliexpress.us/item/3256804473999312.html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

From JLCPCB there are 5mm pitch screw terminals. Example:
https://jlcpcb.com/partdetail/Jiln-JL50050006G01/C2802619

melanielaporte, 2024-09-18:
@ForrestErickson Close?

ForrestErickson, 2024-09-19:
I think until we have an enclosure or enclosures fully designed we will remain uncertain on the wires which connect the controller to the incubator (heater)

RobertLRead, 2024-09-25:
We now know to increase size of screw clamp connectors for the automotive brake light connectors.

RobertLRead, 2024-09-25:
At present, the GND connection of the digital thermometer has not obvious place to be connected. In a future design, the resistor should be on the PCB (NOT a flying solder joint). Also, a connector for GND is needed. At present, the screw clamp connector could be reused for GND, but it would be hard to connect two wires here.

melanielaporte, 2025-08-29:
@RobertLRead Will test today.

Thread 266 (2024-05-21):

Overheating Problem URGENT

SilviaKarbid, 2024-05-21:
### Heater Sensor Overheating
The temperature sensor board we received seems to have an overheating issue. This is causing the sensor to malfunction and provide inaccurate readings. When testing the temperature sensor board at 12V, the PCB experiences excessive heating, making the temperature readings unreliable and not reflective of the actual temperature at the incubator.

### UNO InCompatibility
There also seem to be compatibility issues between the R3 and R4 boards, as the R4 board does not function properly when tested on both boards.
Has anyone tested the board to see if they are also experiencing any of the previously mentioned issues?
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

ForrestErickson, 2024-05-22:
Review with Silvia the issues
Regarding UNO InCompatibility
There also seem to be compatibility issues between the R3 and R4 boards, as the R4 board does not function properly when tested on both boards.

### Description of hardware during test.
The Controller is an UNO R3.
Device under test powered only from the USB. There was no connection to the power jack.
The R3 is able to read the temperature sensor.  And the readings make sense.  Used lighter (fame) near the sensor.

### Suspected Problem
The current through the Schoktee Diode is heating the diode.  The diode was for reverse polarity protection. and can be defeated (Shorted out).

### Fix to try
Short out D1 and retest.

Closed 2024-05-30.

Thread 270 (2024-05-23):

No Render, "Perforated_plate.scad",

ForrestErickson, 2024-05-23:
Rob,
I keep learning more about the Moonrat past.
During our zoom with Auja you showed the perforated platform on legs (the spindly ones) which was new to me.
I went looking and found in the folder now under legacy some SCAD files including "Perforated_plate.scad"
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

However when I open it in my SCAD, I get no render and a warning
"WARNING: No top level geometry to render "
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

Can you duplicate the problem? Is there a simple fix on my end?
 

RobertLRead, 2024-05-23:
Forgive me; I was working on that in OpenSCAD, and then I think @harshit9602 took over and designed the perforated plates. I don't know if he ever committed that design file. (The legs are too weak in any case.)

I could duplicate the work quickly in OpenSCAD if it become necessary (Harshit may have used a different tool.)  I will assign this to Harshit to have him check in the file (if he still has it).

ForrestErickson, 2024-05-29:
Robert wrote the following email:
Dear Lee, 
While in the  meeting with xxxxx, I updated the code here:
https://github.com/PubInv/moonrat/blob/main/legacy/moonrat/Perforated_plate.scad
The round perforated plate is 120mm in diameter. The legs make the disk about 13mm high. (The legs are too fragile, BTW.)
The current OpenSCAD does not add legs. I still think Harshit made the parts I actually have. But I could quickly make them OpenSCAD if I have to.

Lee updated his fork and confirms that the part now renders in OpenSCAD.
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

Closing this issue.

harshit9602, 2024-06-16:
Hey Robert,
Sorry for being away for so long. I was out on a company trip to Ohio on a
legal project. I am attaching the files that we can print and see if things
assemble as per need or not. if it needs more adjustment, i can do that.
For now someone else needs to print this and verify. I think Lee has a 3d
printer. Really sorry for the trouble

On Thu, May 23, 2024 at 10:00 AM Robert L. Read ***@***.***>
wrote:

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

harshit9602, 2024-06-17:
Harshit,

Please note change of subject line on this email.

Thanks for the files. I have placed the files into the repository at:
https://github.com/PubInv/moonrat/tree/main/moonratII/enclosure_mooonratII/Control_Enclosure_FreeCAD

I have opened the FreeCAD file and find that this is an enclosure top.
I have renamed the files to make the names more descriptive.

I see a mounting bos only for two of the four mounting locations of the PCB.
All four mounting holes should have screws.
Please also provide all original files. For example, If this is done in Solid Works please include those files.

It would be best if all files were under version control at the repository.
Do you need help learning the Git and Github and work flow for file version control?

Lee

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

ForrestErickson, 2024-06-17:
This should have been the subject line: MoonratII_Enclosure_Controler_top

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

Closed 2024-05-29.

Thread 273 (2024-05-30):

Input Voltage for the TMP sensor, affects the measure scale

kurama79, 2024-05-30:
# Arduino UNO R3 and Arduino UNO R4 WiFi default 5 volts pin issue

Here we test just the sensor to verify that the lectures of the temperature were right, the problem surges when we measure with a voltmeter the voltage input that it receives. For the calibration, it is necessary to consider the input voltage to set the correct scale and get good sensing. Then we proceed to make the next proofs.

## USB case
The Arduino board is connected to the USB port in the computer and these are the lectures:

### R3 ------------------------------------------------------------------
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

### R4 ------------------------------------------------------------------
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

As we can see the first one which is the Arduino R3 has a better and stable input voltage for the sensor and the Arduino R4 doesn't.

## 12 Volts Power Supply
The Arduino board is connected to 12 volts, and the voltmeter measures are:

### R3 ------------------------------------------------------------------
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

### R4 ------------------------------------------------------------------
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

In this case, the Arduino which is more confident is the R4.

## Solution
We propose adding the next function to the code to detect the Arduino board's real voltage in the 5-volt pin.

```
long readVcc()
{
    // Configure the ADC to use the intern reference channel
    ADMUX = _BV(REFS0) | _BV(MUX3) | _BV(MUX2) | _BV(MUX1);
    delay(2);  // Wait for a stable reference

    // Initialize the ADC conversion
    ADCSRA |= _BV(ADSC);
    while (bit_is_set(ADCSRA, ADSC));

    // Read the ADC
    uint8_t low = ADCL;
    uint8_t high = ADCH;
    long result = (high << 8) | low;

    // Vcc in millivolts
    long vcc = 1126400L / ADC;  // Utiliza 1.1 * 1024 * 1000
    //long vcc = (1.1 * 1024 * 1000) / result;  // Utiliza 1.1 * 1024 * 1000

  return vcc;
}
```
The above code "solves" the problem because we can use that real voltage to calibrate the sensor with the current voltage in the 5-volt pin.

### But... :(
This code doesn't work in Arduino R4, but the R4 has a more stable voltage when connected to a power supply over 6 volts, its 5-volt pin always has 4.98 volts.

So we propose an #ifdef conditional in the code where if the variables and default functions that measure the voltage in the Arduino board (R3 case) then we can run the above function, if not then we can consider the 4.98 volt to the calibration.

ForrestErickson, 2024-05-31:
Regarding the voltage on R3 and R4 and how the voltage changes from USB input to external Vcc input.

Lets review a bit to get a common understanding.
### Ratiometric
The A2D (Analog to Digital) conversion process is of a type called "ratiometric " This means that any change to the reference voltage of the A2D will cause a change in the converted digital value.
If this is new to you, here is some well written explanations
https://learn.sparkfun.com/tutorials/analog-to-digital-conversion/all

So if changes to the supply to the MoonRat and therefor the UNO make changes to the Vcc errors will occur in the converted temperature.

### Programable Reference
The Atmega328 has in internal reference from which the A2D can also be referenced.
See: https://www.arduino.cc/reference/en/language/functions/analog-io/analogreference/
This reference is 1.1 Volt.
Refer to the Atmega328 data sheet for any specification on tolerance and on temperature coefficient for this reference which may need to be taken into account.
This reference may help us a lot.
Data sheet URL: https://www.analog.com/media/en/technical-documentation/data-sheets/tmp35_36_37.pdf

### Voltage of TMP36 at ,= 50C
The TMP36 data sheet shows a typical output voltage versus temperature
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
For temperatures of interest to our incubation this voltage looks to be comfortably below the 1.1Volt refence so that that reference could be used.

## Conclusion Factory Calibration Is Probably A Requirement
While I have not tried to make an error budget and unless someone undertakes the task to do so and can demonstrate that we do not need to do so, I think it is a requirement that we build a factory calibration methodology into our device.

### Calibration One or Two Points
We would place the TMP36 sensor into a calibrated temperature environment and then adjust (a multiplicative offset I think) the returned value to report the correct value of the calibrated environment.
It would be even better to calibrate at two temperatures. 0C is probably a good temperature for a low end as ice water is easy to make.
Harder is the higher temperature. We could simply heat an environment to some thing like 45C and measure with an accurate external device the real temperature and then calibrate the MoonRatII to that temperature.

### Calibration and Storing Calibration
While I have not tried to work out code details, the Arduino MAP function is probably a very handy way to do this.
The firmware would need to store two calibration numbers into EEPROM. And probably another location to indicate that the numbers are valid calibration numbers.

ForrestErickson, 2024-05-31:
See more about the MAP function here:
https://www.arduino.cc/reference/en/language/functions/math/map/

Note that the function uses integers and truncates and so the numbers fed into it should probably be multiplied by ten before the MAP function and then a floating point divide by ten of the returned value from the MAP would preserve some accuracy.

However I am only speculating.

melanielaporte, 2024-12-07:
Irrelevant since we're not using the TMP36? @RobertLRead @ForrestErickson

Closed 2025-08-27.

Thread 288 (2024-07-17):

Professional portrait/biography/affiliation

melanielaporte, 2024-07-17:
The following information is needed and will be published in the paper.
Please comment below.
**Note: all included will be publicly visible
- 1 professional headshot (do not include body)
- professional biography, 100 word maximum
- university affiliation

ForrestErickson, 2024-07-19:
I know I have and suspect other volunteers have a photo on the Public Invention org web page.
See:  https://www.pubinv.org/inventors/

The photo there is the one to be used for me.

melanielaporte, 2024-07-19:
Thanks Lee, the paper still requires a 100 word or less biography from you. I assume your affiliation is Public Invention. Add your biography below in a comment

ForrestErickson, 2024-07-19:
(Forest) Lee Erickson
Public Inventor of the General Purpose Alarm Device (GPAD) Project
B.S. Physicist University of Minnesota.
I am the luckiest person to have ever lived because when I was ten years old, I was taken to the moon by Michael Collins, Buzz Aldrin and Neal Armstrong (as were about five billion other persons watching television.)

I have had a career doing elementary analog circuit design for audio, video and deflection systems and embedded system with some focus on electro- magnetic compatibility. I worked for a high volume consumer electronic company where I learned the importance of design for manufacturing and project management of medium- to large-multidisciplinary teams. I also ran my own company for 12 years where I had to take on almost all roles from time to time.

With Public Invention I have helped with the General Purpose Alarm Device (GPAD) project especially with Schematic Capture and PCB Design and testing. I wrote and simulated firmware for factory testing of the Version 1 PCB. From my Public Invention involvement, I have improved my understanding of how to use GitHub (and GitLab) for managing product development from my team mates. My short term interests are to document well the GPAD as a template to help Public Invention and others.

I am a refugee from the winters of Minnesota and live in East Tennessee where snow is sufficiently infrequent that it is mostly received as decorative when it happens. My supper power is NOVEL SPELLING ( and diverse spelling). My Github is found at: https://github.com/ForrestErickson

melanielaporte, 2024-07-23:
Your 100 word biography: I am the luckiest person to have ever lived because when I was ten years old, I was taken to the moon by Michael Collins, Buzz Aldrin and Neal Armstrong (as were about five billion other persons watching television.)

I have had a career doing elementary analog circuit design for audio, video and deflection systems and embedded system with some focus on electro- magnetic compatibility. I worked for a high volume consumer electronic company where I learned the importance of design for manufacturing and project management of medium- to large-multidisciplinary teams. I also ran my own company for 12 years

Closed 2024-07-23.

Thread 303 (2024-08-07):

Severe Electrical Flakiness, TMP36 changes reading when I2C connected to display.

RobertLRead, 2024-08-07:
I am still investigating, but it is clear we have a severe electrical problem with our temperature read.

In the first place, the code seems to presuppose we are using a TMP37, but we are really using a TMP36. When used in fully assembled mode, the Moonrat temperature readings very by as much as 20 degrees C.  This is directly caused by the voltage reads on Pin A0 fluctuating.

However, after disassembling the board and connecting only the GND, 5V, 3.3V, and A5 lines, the temperature sensor does NOT fluctuate, but it relatively steady. It reacts to increase in temperature (generating by me placing my thumb on the sensor) by a direct increase in voltage represent about 5 degrees as it should.

However, the simple act of unplugging and plugging the I2C connections into the dissasembled board (that is,our PCB not mounted onto an R4 minima, but placed beside it and individaully wired, causes a change in the voltage level from approximate 163 to 173. Each digital tick is 0.5 millivolts, so this represents 50 millivolts, which on a TMP36 would correspond to 5 degrees C change in reported voltage.  In the image below you can see the change in the "reading" which is a direct reading of the analog input pin (no match or conversion applied.)

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

I do not yet understand this, but it seems clear that the Display (which is our I2C element) is drawing too much current or produce an unexpectedly high capacitance on the line or doing something else naughty at an electrical level.  I will conti

RobertLRead, 2024-08-07:
My Fluke 87 V doe not observe a difference in the voltage level of the output of the TMP36 sensor as the SCL and SDA wires are plugged in and unplugged. This suggest to me that the voltage of the sensor is not changing, but somehow the analog to Digital converter is failing, possible due to a lowered voltage as the I2C instrument draws power.

RobertLRead, 2024-08-08:
Note: This is just a silly note: when debugging by placing the PCB shield unstacked from the Arduino R4. This needs the to have A4 and A5 to be connected, apparently because these are overloaded to be SCL/SDA.

RobertLRead, 2024-08-08:
After connecting the A4 and A5 pins, D5, D6, and D7, and the SDA and SCL pins, as well as 5V and GND (with the shield not plugged into the system, incredibly the system now seems stable. When using a cell phone next to it I perceived some minor interference in the case of a lowered voltage value which was temporary. I cannot explain why it is working better now than previously.

RobertLRead, 2024-08-08:
After putting the shield back on, the erratic nature of the temperature readings has come back. In the output below, the raw readings oscillate between 140 and 181!!!

I have no explanation for this. Possibly the proximity of the shield to the mimina itself casues a problem. Possibly capacitance added by the wires (which i remove when I stack the shield) makes it behave better.

I am very confused by this.

Frequency Output: 165.00

reading: 146
volts: 0.71
21.29 degrees C
filter: 21.60

Frequency Output: 170.00

reading: 146
volts: 0.71
21.29 degrees C
filter: 21.59

Frequency Output: 170.00

reading: 142
volts: 0.69
19.34 degrees C
filter: 21.55

Frequency Output: 169.00

reading: 140
volts: 0.68
18.36 degrees C
filter: 21.50

Frequency Output: 169.00

ForrestErickson, 2024-08-08:
## Capture of test conditions
Please capture the exact serial number of the Moonrat II hardware under test.
Please capture the exact firmware with which this test was made, for each test.
Please make a photograph of the setup(s) where you can reconstructing it (them). A photograph to capture what you mean by shield on and shield off would help.

## Which Analog Input
Regarding, "However, after disassembling the board and connecting only the GND, 5V, 3.3V, and A5 lines, the temperature sensor does NOT fluctuate, "
The A5 line is not the ADC for the TMP36 and so cannot work to measure temperature.  Why is A5 involved?

RobertLRead, 2024-08-08:
I should have said A0.  The temperature is read from A0.

There is no serial number on my board. There is a black smudge of ink that appears to have once been a serial number; it comes off when I rub it with my thumb.

I am now adding a set of facts which may be unrelated but make no sense.

1. When I plugged the shield in, the values A0 voltage values where wildly erratic, differing by 40%.
2. When I wire all of the wires (except AREF , 3.3V, IOREF and BOOT, the system appears to be stable and gives approximately the correct valued.s
3. There are occasionally high fequency noise on the A0 line, as shown by the image below. These happen about once per second, which is the frequency which which we go through the loop and is likely the A0 read frequency. This is the cyan colored trace below. (Note voltage scales of traces differ, this is about 0.77 volts, which is approximate 27 Degree C, which is approximately the temperature of my office.
4.
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
5. Plugging capacitors of various sizes between ground and A0 does decrease the amplitude of this noise. However, I have no reason to believe this noise is effecting the temperature read.

The biggist unexplained problem right now is that when the shield is plugged in it is wildly erratic and yet when it is wired by hand it is stable.  I have no explanation for this.  I have moved the shield on top of the R4 (to the extent the wires allow me to) to see if physical proximity makes a difference and it does not appear to make a discernible difference.

RobertLRead, 2024-08-08:
Here are two photos showing the shield off the R4, completely wired with jumper wires, which seems to have a stable read of the TMP36 voltage on A0.

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

RobertLRead, 2024-08-09:
Note: When on a call with Lee Erickson using my Iphone while it was using Bluetooth hearing aids, it caused the A0 inputs to drop to nearly zero, as shown by the blue line here:
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

ForrestErickson, 2024-08-09:
@RobertLRead
Regarding,
> Note: When on a call with Lee Erickson using my Iphone while it was using Bluetooth hearing aids, it caused the A0 inputs to drop to nearly zero, as shown by the blue line here:

and

> When NOT using Bluetooth, but on the phone, it produced a different but similarly interfered trace:

Please add a base line oscilloscope graph to the above, with NO cellphone and NO bluetooth connection for the same setup.

ForrestErickson, 2024-08-09:
##  Firmware During Robert's Test  of 20240808
https://github.com/PubInv/moonrat/blob/main/moonratII/firmware_moonratII/production_R4/MoonTestV5/MoonTestV5.ino

ForrestErickson, 2024-08-09:
@RobertLRead

If time is critical for your trip, why are  you using the R4?
Use an R3. for which IIRC, @HJGV05 reported different **and better** behavior.

RobertLRead, 2024-08-09:
@ForrestErickson I think it is worth trying quickly to see if it solves some of these problems. When I began I was using an R3 (though I think it was  knock-off imitation that was sent to me) and had the same problems. I am resistant to not solving this now that you have given me such good advice, but it may indeed be worth trying.

RobertLRead, 2024-08-09:
Note: When I added a debugging statement which STOPPED writing to the OLED display during the loop, the obvious oscillation in voltage in both the 5V line and A0 line disappeared (see image below). The temperature became much steadier.  I hypothesize that this could be either A) a sag in the voltage due to drawing too much current or B) some sort of EMI can crosstalk. I will now attempt to test those hypotheses.

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

RobertLRead, 2024-08-09:
By calling "display.display" mulitple times, w can definitely create significant noise on the A0 line:

`  } else {
       display.clearDisplay();
       display.display();
       display.clearDisplay();
       display.display();
       display.clearDisplay();
       display.display();
    }`

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

RobertLRead, 2024-08-09:
I sent this email to the team:

Dear Team,
I have been working though a number of problems with the help of Lee. I have created a new version, which addresses significant problems, and makes some decisions which are merely taste.
https://github.com/PubInv/moonrat/blob/main/moonratII/firmware_moonratII/production_R4/MoonRatRob6/MoonRatRob6.ino

I will describe this thoroughly in issues, the README, and internal documentation within the code.  But I wanted to explain this all in one place, although there are multiple overlapping problems.

1. The code I got assumes we have a TMP37; we have a TMP36. I don't know how this ever code have worked, as the math for the computation of temperature is quite different.
2. It is DEFINITELY the case that using the I2C bus to communicate to the OLED causes the A0 voltage to have noise. I believe (with high probability) that this can be eliminated by just not updating the OLED near the time or reading. Whether this is because of a voltage sag or electromagnetic interference, I don't know. I have change the code to make it more stable; it would have looked to the team in Mexico like random noise. I have not completely solved this problem (I have currently "unstacked" our PCB assembly shield from the R4), but in this confiiguration it is better.
3. It is DEFINITELY the case that a cell phone can cause DRASTIC changes to the A0 voltage when near the board. This is not necessarily a problem that prevents it being used, but is something we need to be aware of.

I have reorganized Horacio's code a bit, in ways that I think are simpler.
I now must:
1. Test with the system "stacked".
2. Test with a 12V input
3. Test actual heat production
4My main goal now is to have a system to take to Tanzania. However, we have much more work to do before we can "release" this design. I don't believe we can invite people to use it until we have solved all of these EMI problems. That may require switching to a digital thermometer, which is what I used in the Moonrat which is in Ecuador---I did not know it would be such a problem here.

RobertLRead, 2024-08-09:
When I stack the board on top of the R4, the A0 signal becomes ridiculously populated with high frequency noise. Although this code in theory be smoothed with a capacitors, I do not find it hopeful---I would rather eliminate the noise than smooth it. I will compare this with an R3 after this.
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

RobertLRead, 2024-08-09:
Initial evaluation suggests the Arduino R3 does not suffer from the same instability in the voltage on A0.

ForrestErickson, 2024-08-10:
@RobertLRead regarding, " Test actual heat production"

You will need to remove the 100 Ohm resistor in series with the heating pad in the unit. That was put there so that I could, in principle, test everything off of the USB supply at low current (low heating).
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

ForrestErickson, 2024-08-10:
@RobertLRead
Regarding, "When I stack the board on top of the R4, the A0 signal becomes ridiculously populated with high frequency noise."
As time permits,

1. Please repeat this test with only a BLINK sketch.  NO setup of any pin except the builtinLED. Characterized the interference on A0.
2. Then make a sketch with blinks the LED and reads A0 once a second, as the LED blinks. Characterized the interference on A0.
3. Then make a sketch with blinks the LED and reads A0 and reports the value of A0 out the serial port once a second, as the LED blinks. Characterized the interference on A0.

Characterize with oscilloscope waveforms as above.

melanielaporte, 2024-09-18:
@RobertLRead Issue needs solution update.

Closed 2025-08-27.

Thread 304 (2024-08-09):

Development and Management of WOKWI Simulations for MoonRatII

ForrestErickson, 2024-08-09:
# Summary
A WOKWI Simulation or Simulations of the MoonRatII Version 2 PCB wiring my be of great value

## Request
Have any of you created a schematic in WOKWI that has good fidelity to the MoonRatII Version 2 PCB ?
Lee suspects there may be more than one.
Can we share this work soon so? I hope to help Robert with the troubleshooting he is doing right now on a unit he hopes to take into the field very soon?

If there is already in this repository a WOKWI simulation please help me find it.

Thanks,
Lee Erickson

HJGV05, 2024-08-09:
Hello Mr Lee!

I hope you are fine, sure, here is the last Wokwi project we created: https://wokwi.com/projects/390933163302682625

 It was attached to the script versions, but since we used some libraries that are not available in Wokwi (like the eFLL library) we did not continue updating it. I hope it helps!

Best Regards,

Horacio García

ForrestErickson, 2024-08-09:
@HJGV05
It appears that the EFLL libaray can be added through the WOKWI library manager.
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

and
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

ForrestErickson, 2024-08-09:
I have copied the most current code into a new WOKWI at:
https://wokwi.com/projects/405744143993619457

It fails to compile:
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

I assume this is due to the UNO Version 4 but am not certain.

RobertLRead, 2024-08-09:
I made some changes as defined below, which allow it do compile; I interpret this as being either WOKWI does not today support the R4 at all, or we have not properly configured it to do so.  (Please observed commented-out lines below!
I do not assume this works; I just got it to compile. @ForrestErickson

`#elif defined(R4) //Configuration for Arduino UNO R4
 // analogReference(AR_DEFAULT);  // Internal reference
 analogReference(DEFAULT);  // Internal reference
  delay(10);  // Awaiting reference stability
  // float sensorValue = map(analogReference(), 0, 5.0, 0, 255.0);  // Internal reference mapping
  float sensorValue = map(DEFAULT, 0, 5.0, 0, 255.0);  // Internal reference mapping
  long vcc = (1000 * 1.1 * 1023) / sensorValue;

#else
#error Serial.println("Unsupported board selection.");
#endif
  return vcc;
}

void setup() {

#if defined(R4)
//  analogReadResolution(10);
//  analogReference(AR_DEFAULT);
#else`

Closed 2025-08-27.

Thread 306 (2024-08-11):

TMP36 output voltage steady in the presence of reference voltage sags....

RobertLRead, 2024-08-11:
When the MoonratII is power by a USB cable but connected to a 12V battery with a switch, switching the battery on and OFF does NOT change the output of the TMP36 voltage as measured by an oscilloscope on an Arduino R3.

However, using both a voltmeter and an oscilloscope, the 5V pin of the Arduino R3 voltage changes from 4.66 V to 4.99 volts. This has an immediate effect on the digitally measured temperatre, as evidenced by the screen shot below, which shows the voltage being switch off.
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
Note the ratios 4.99/4.66 and 166/156 are the same (1.070) to the third decimal place, confirming @ForrestErickson 's statement that the ADC converted measures a ratio.

We may futhermore conclude that this is only correct if the 5V voltage does not sag due to a load; however, when the system is powered at 12V, this is approximately correct.

Although this fragility is distressing, it may not matter if we power the incubator with a 12V power supply.

ForrestErickson, 2024-08-11:
While I assume you are using the R3 Arduino you should state so.
Please also state the exact firmware used.

Then, the first think I am going to do is look at the voltage on the reference to be set for 1.1V.
From the documentation

> INTERNAL: a built-in reference, equal to 1.1 volts on the ATmega168 or ATmega328P and 2.56 volts on the ATmega32U4 and ATmega8 (not available on the Arduino Mega)

This will require a gain change for calculating the temperature.

ForrestErickson, 2024-08-11:
By the way I see no firmware in the folder where I think it is supposed to be:
https://github.com/PubInv/moonrat/tree/main/moonratII/firmware_moonratII/production_R4/MoonTestV5
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

RobertLRead, 2024-08-11:
My new R3 work is (and will be) here:

https://github.com/PubInv/moonrat/tree/main/moonratII/firmware_moonratII/production/moonratIIR3Rob

Being uncertain of myself, I put my latest R4 code here:

https://github.com/PubInv/moonrat/blob/main/moonratII/firmware_moonratII/production_R4/MoonRatRob6/MoonRatRob6.ino

However, I am now focuing on the R3, as it gives me some hope of building a system that I can take to Tanzania.

melanielaporte, 2024-12-07:
This issue is irrelevant since we are using the R4, correct? @RobertLRead

Closed 2025-08-27.

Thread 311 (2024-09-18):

Change for DS18b20 Digital Temperature Sensor

ForrestErickson, 2024-09-18:
**Is your feature request related to a problem? Please describe.**
_A clear and concise description of what the problem is. Ex. I'm always frustrated when [...]_
The analog sensor is a victim of interference and is unusable on the Arduino R4.
Migrate the design from the analog temperature sensor to a digital sensor

**Describe the solution you'd like**
_A clear and concise description of what you want to happen._
Change for DS18b20 Digital Temperature Sensor

SilviaKarbid, 2024-09-25:
Hi Lee, we added the DS18b20 sensor. The sensor has a 4.7k resistor between the signal and the voltage, and it was soldered directly to the signal output and the 5V power output, as seen in the images. We obtained a much more accurate reading with less variation between measurements.
![Uploading WhatsApp Image 2024-09-24 at 7.46.59 PM (1).jpeg…]()

SilviaKarbid, 2024-09-25:
The new sensor code is uploded in the new code.

Closed 2024-09-25.

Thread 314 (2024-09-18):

Enclosure Controller: At present there is no way to securely screw down the top and Printed Wiring Assembly (PWA)

RobertLRead, 2024-09-18:
This may be done by adding holes to the bosses in the bottom part.

melanielaporte, 2025-08-28:
Solved.

Closed 2025-08-28.

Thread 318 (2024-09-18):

Paper authorship: attach your professional portrait, biography, and affiliation

melanielaporte, 2024-09-18:
The following information is needed and will be published in the paper.
Please comment below.

Required:
- Full name to be listed on the paper
- One professional headshot (no body shots) – If you prefer a different photo than the one listed on the [Public Invention site](https://www.pubinv.org/inventors/), please upload it below.
- University affiliation
- Optional but important - [ORCID](https://orcid.org/)
- Professional biography (100 words max)

melanielaporte, 2024-09-18:
FULL NAME: Robert L. Read

AFFILIATION: Public Invention, 1709 Norris Dr., Austin, TX 78704

ORCID: 0000-0003-4749-7045

BIO: Robert L. Read has a BA in Computer Science from Rice University and PhD in Computer Science from the University of Texas at Austin. After holding director-level positions in software firms, he was a Presidential Innovation Fellow in 2013 and co-founded the 18F technology incubator in the US Federal Government. In 2018, he founded Public Invention, a US 501c3 public charity whose motto is “Invent in the public, for the Public.” Public Invention organizes teams of volunteers to work on free, open humanitarian research and engineering projects, recently including ferrofluid, tetrahedral robots, human medical ventilation, oxygen generation, and pure mathematics.

melanielaporte, 2024-09-18:
Silvia Aurora Casillas Romero is a PhD student in Electrical Engineering. Her current field of study is artificial intelligence, and she has a solid background in programming, frequency filter design, 3D modeling, and artificial intelligence. Silvia holds a Master's degree in Electrical Engineering, during which she worked on projects related to hydroponics. She is currently interested in deepening her knowledge of the development of artificial intelligence systems.
University aff: Cinvestav Unidad Guadalajara

melanielaporte, 2024-09-18:
L. Enrique Ruiz-Fernandez is an AI developer specializing in robotics. He is currently completing his Ph.D. in Robotics, holds a Master's degree in Electrical Engineering, and a Bachelor's degree in Control Engineering. His research focuses on autonomous navigation and collision avoidance for drones. With a strong background in control theory and electronics, he creates innovative solutions for complex engineering challenges. Additionally, he teaches key engineering courses, sharing his expertise with future engineers.
University aff: Cinvestav Unidad Guadalajara and Universidad de Guadalajara

melanielaporte, 2024-09-18:
(Forest) Lee Erickson
Public Inventor of the General Purpose Alarm Device (GPAD) Project
B.S. Physicist University of Minnesota.
I am the luckiest person to have ever lived because when I was ten years old, I was taken to the moon by Michael Collins, Buzz Aldrin and Neal Armstrong (as were about five billion other persons watching television.)

I have had a career doing elementary analog circuit design for audio, video and deflection systems and embedded system with some focus on electro- magnetic compatibility. I worked for a high volume consumer electronic company where I learned the importance of design for manufacturing and project management of medium- to large-multidisciplinary teams. I also ran my own company for 12 years where I had to take on almost all roles from time to time.

With Public Invention I have helped with the General Purpose Alarm Device (GPAD) project especially with Schematic Capture and PCB Design and testing. I wrote and simulated firmware for factory testing of the Version 1 PCB. From my Public Invention involvement, I have improved my understanding of how to use GitHub (and GitLab) for managing product development from my team mates. My short term interests are to document well the GPAD as a template to help Public Invention and others.

I am a refugee from the winters of Minnesota and live in East Tennessee where snow is sufficiently infrequent that it is mostly received as decorative when it happens. My supper power is NOVEL SPELLING ( and diverse spelling). My Github is found at: https://github.com/ForrestErickson

HJGV05, 2024-09-25:
Horacio Garc\'ia--V\'azquez} was born in Colima, M\'exico in 1995. He received the B. E. degree in Mechatronic Engineering  from the Colima Institute of Technology in 2018 and the M. Sc. degree in Electrical Engineering from the Center of Research and Advanced Studies (CINVESTAV-IPN) in 2020. He is currently pursuing the Ph. D. degree in Electrical Engineering at CINVESTAV-IPN.~His research interests include the output regulation problem, multi--agent systems, hybrid control systems and drones navigation.

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

melanielaporte, 2024-09-25:
Thank you @HJGV05!

Closed 2024-10-30.

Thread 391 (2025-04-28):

Enclosure, Controller Rev2

melanielaporte, 2025-04-28:
**Describe the solution you'd like**
_A clear and concise description of what you want to happen._

MVP upgrade: design universal heater board cage to hold heater board into any outside container. Cage will be located under the container top

Enclosure testing: mechanical form and fit buttons raise the enclosure up from the PCB about 12mm to fit the headers
- https://github.com/PubInv/moonrat/issues/314
- https://github.com/PubInv/moonrat/issues/313

Design button from scratch
- https://github.com/PubInv/moonrat/issues/315
- https://github.com/PubInv/moonrat/issues/352

Update for R4, step file
- https://github.com/PubInv/moonrat/issues/272
- https://github.com/PubInv/moonrat/issues/323

Prusa Slicer Returns Warning on case_incubator.FCStd,  #264
- https://github.com/PubInv/moonrat/issues/198

Add mounting holes on bottom of enclosure
- Print 3D test enclosure units
- Order professionally designed 3D print from Xometry

melanielaporte, 2025-08-28:
Solved, 20250828.

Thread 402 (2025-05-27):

Hardware, case_incubator, add PWA mounting feature, add external mounting holes

melanielaporte, 2025-05-27:
**Is your feature request related to a problem? Please describe.**
_A clear and concise description of what the problem is. Ex. I'm always frustrated when [...]_
 The current case_incubator does not accommodate the PWA lead lengths.

## Describe the solution you'd like
- Add two mounting holes and a screw to attach the PWA to the `case_incubator` platform.
- Trim lead lengths to a TBA (to be announced) value.
- Add a method to mount the `case_incubator` inside an incubator.

## Action Items for 3D Models
- [x] Redesign controller
- [x] `Heater platform → case_incubator`: Add two mounting holes and trim lead lengths or extend the platform
- [x] Check interior Petrifilm holder

## Options for Attaching `case_incubator` Platform to Thermos Metal Top (Interior)
- Drill mounting holes and use screws
- Use a hot glue gun
- Attach with Velcro

## GDL Team Credit
**_Open question: How should the GDL team be credited?_**

## Measurements
- Board thickness: 0.0265" or 1/16"
- Longest green connector lead: 0.7"
- Lead protrusion on solder side of board: 1.9 m

## Actions Taken
- Selected a 2.4 mm mounting boss thickness based on the estimated length of the longest lead.
- Added two mounting holes to the platform to secure the Heater Board PWA.
- Extended the platform feet and created four boss bore holes to accommodate screws, enabling secure attachment of the Heater Board PWA and platform to the underside of the Thermos.

melanielaporte, 2025-08-07:
Solution: redesigned case_incubator with screws instead of requiring the use of hot glue to attach to the Thermos interior.

Closed 2025-08-07.

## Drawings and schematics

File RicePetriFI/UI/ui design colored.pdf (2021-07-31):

## colored

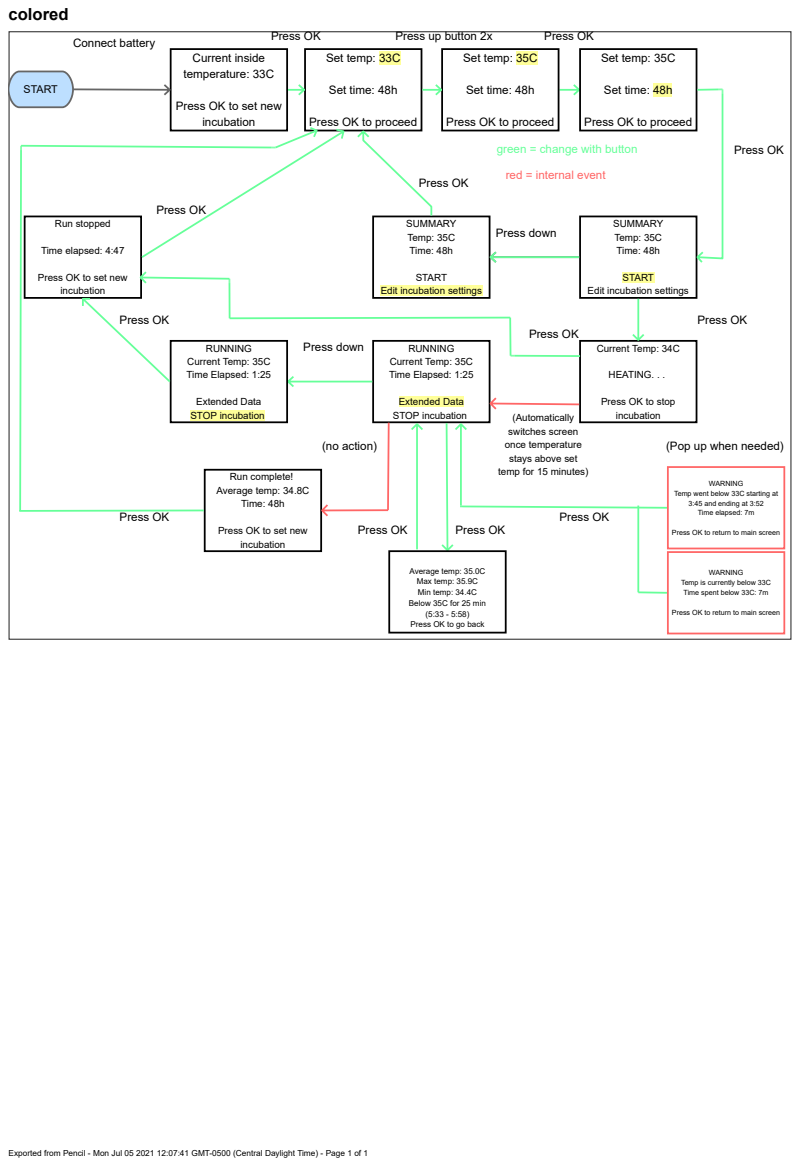
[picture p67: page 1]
Connect battery; Press OK; START; RUNNING Current Temp: 35C Time Elapsed: 1:25; Extended Data STOP incubation; Set temp: 35C; Set time: 48h; Set temp: 33C; Current inside temperature: 33C; Run complete! Average temp: 34.8C Time: 48h; SUMMARY Temp: 35C Time: 48h; Current Temp: 34C; HEATING. . .; Press up button 2x; Press down; Run stopped; Time elapsed: 4:47; WARNING; (no action); (Pop up when needed)

Press OK to set new
incubation

Press OK to proceed

green = change with button
red = internal event

Edit incubation settings

Press OK to stop

(Automatically
switches screen
once temperature
stays above set
temp for 15 minutes)

Temp went below 33C starting at
3:45 and ending at 3:52
Time elapsed: 7m

Press OK to return to main screen

Average temp: 35.0C
Max temp: 35.9C
Min temp: 34.4C
Below 35C for 25 min
Press OK to go back

Temp is currently below 33C
Time spent below 33C: 7m

Exported from Pencil - Mon Jul 05 2021 12:07:41 GMT-0500 (Central Daylight Time) - Page 1 of 1

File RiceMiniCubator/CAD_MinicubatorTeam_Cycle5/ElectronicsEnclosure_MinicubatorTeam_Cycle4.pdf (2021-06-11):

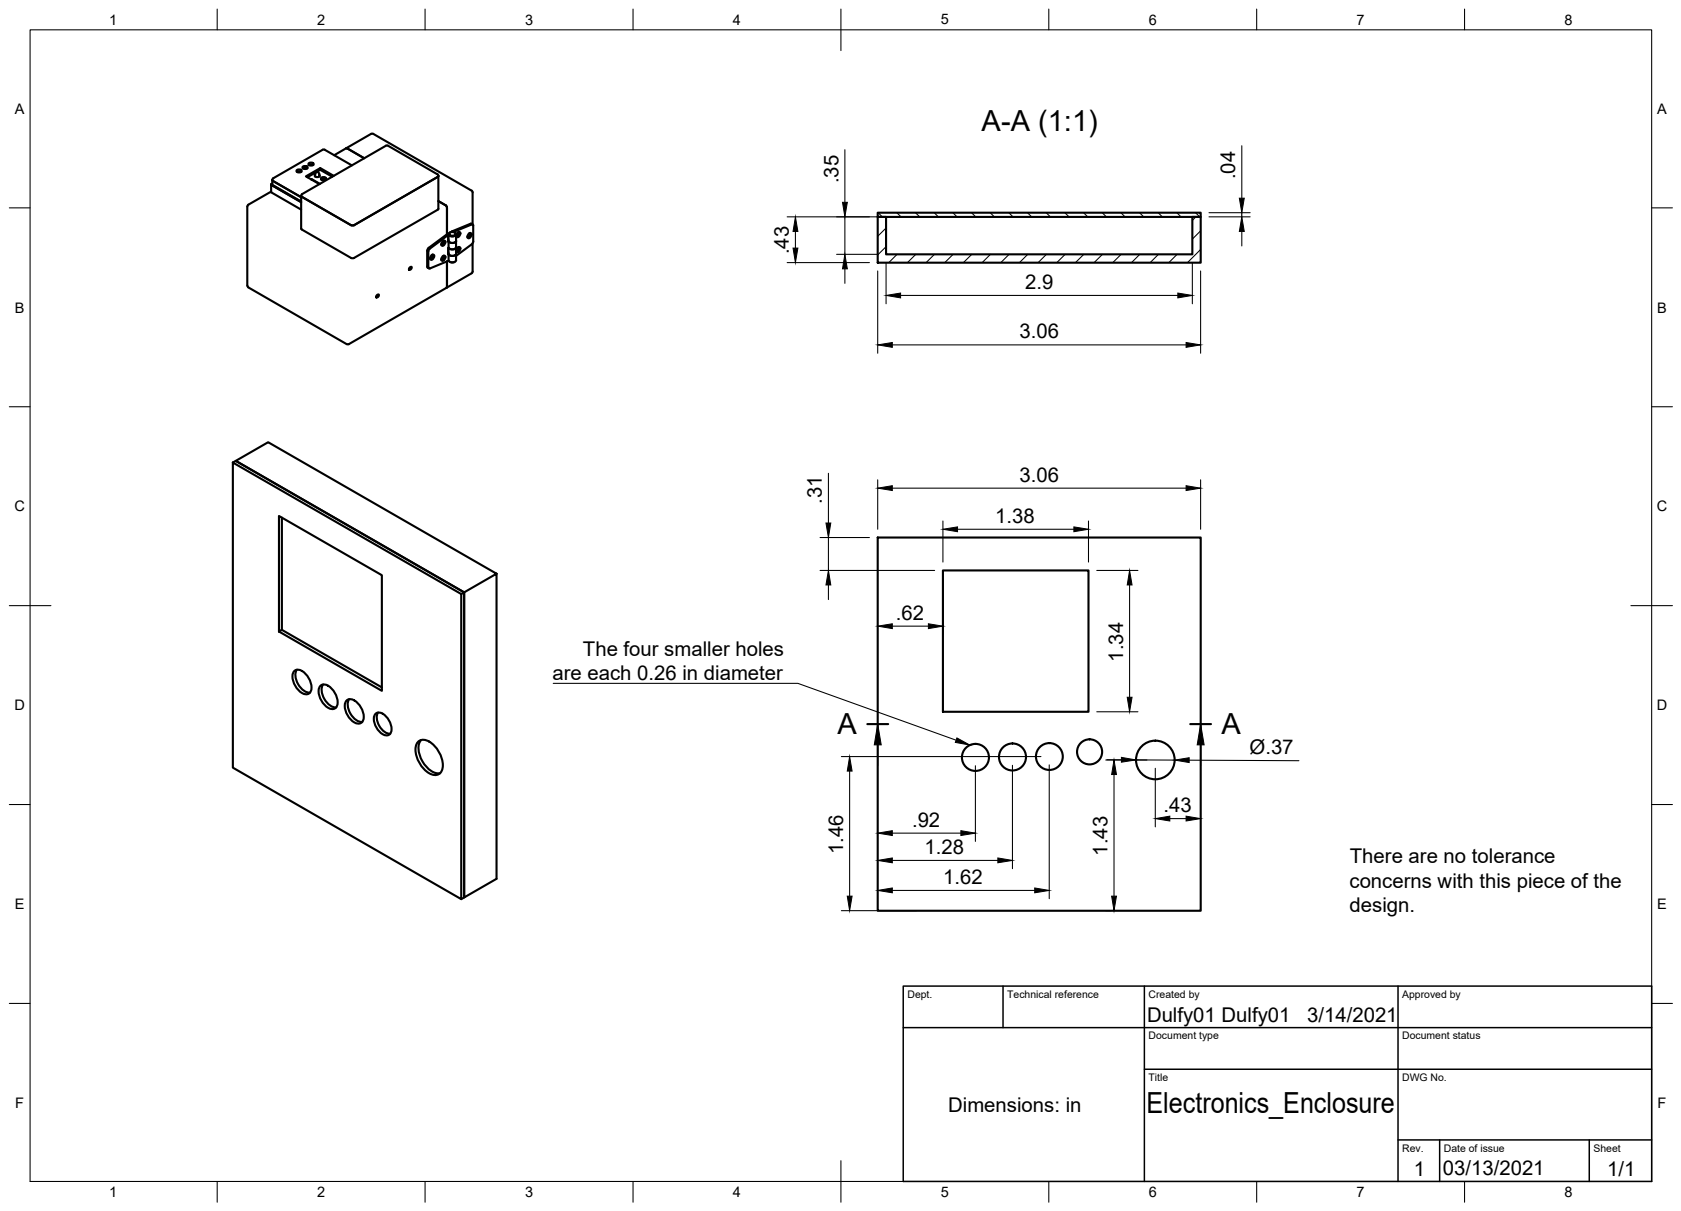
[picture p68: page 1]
Title; DWG No.; Rev.; Date of issue; Sheet; are each 0.26 in diameter; Dimensions: in

The four smaller holes

There are no tolerance
concerns with this piece of the
design.

Dept. | Technical reference | Created by Dulfy01 Dulfy01 3/14/2021 | Approved by

Document type | Document status

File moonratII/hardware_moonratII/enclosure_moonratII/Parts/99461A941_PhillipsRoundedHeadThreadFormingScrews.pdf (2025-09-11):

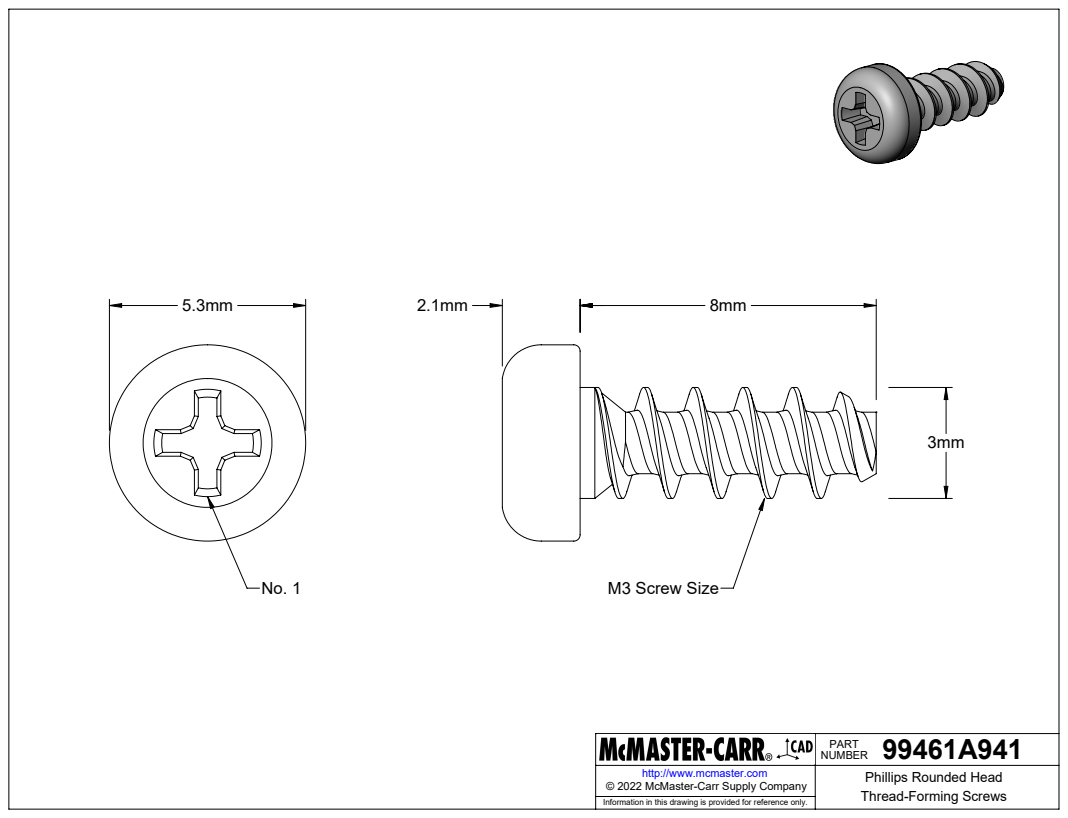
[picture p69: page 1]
M3 Screw Size

99461A941 PART NUMBER

http://www.mcmaster.com | Phillips Rounded Head Thread-Forming Screws © 2022 McMaster-Carr Supply Company

Information in this drawing is provided for reference only.

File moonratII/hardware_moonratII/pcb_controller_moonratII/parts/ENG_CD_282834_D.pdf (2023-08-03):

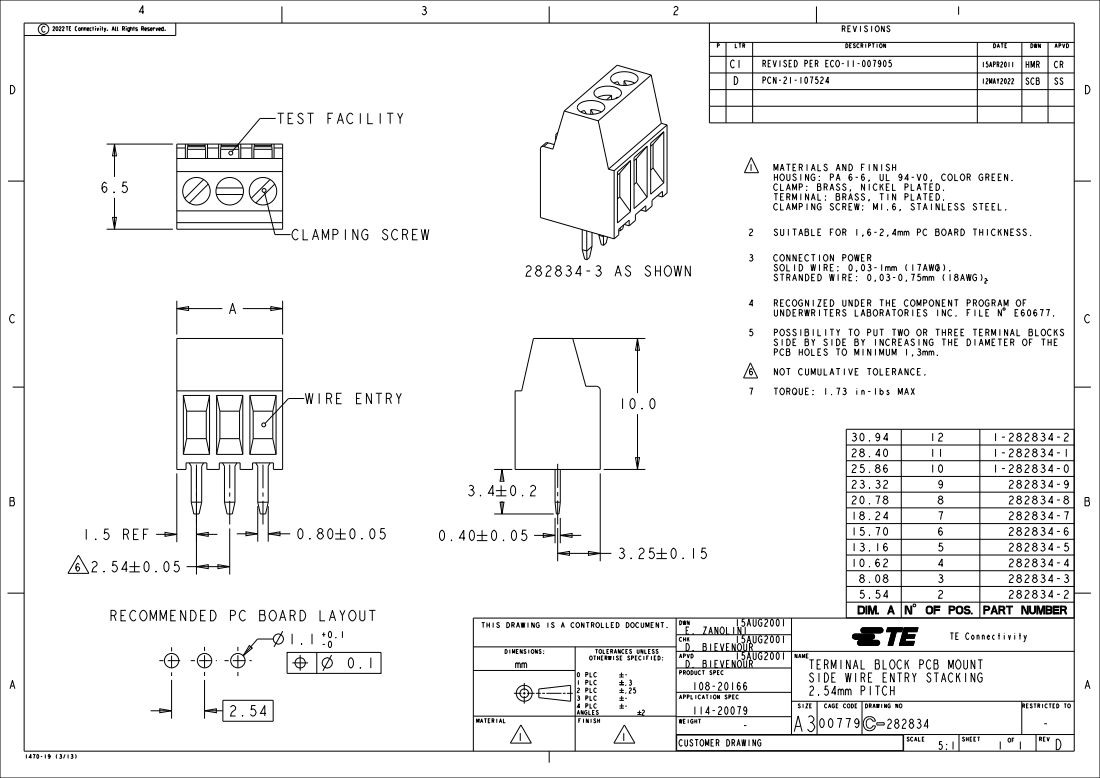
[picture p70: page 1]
0 PLC 1 PLC 2 PLC 3 PLC 4 PLC; SIZE; CAGE; CODE; DRAWING NO; APPLICATION SPEC; THIS DRAWING; IS A CONTROLLED; DOCUMENT.; TE Connectivity; CUSTOMER DRAWING; E. ZANOLINI D. BIEVENOUR D. BIEVENOUR; Connectivity. All; Rights Reserved.; REVISED PER ECO-11-007905; 15APR2011; HMR; 1.5 REF; 1 MATERIALS; AND FINISH; TERMINAL:; BRASS, TIN PLATED.; CLAMPING SCREW:; STAINLESS; STEEL.; 2 SUITABLE; FOR; BOARD THICKNESS.; 3 CONNECTION; POWER; SOLID; WIRE: 0,03-1mm (17AWG).; STRANDED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

HOUSING: PA 6-6, UL 94-V0, COLOR GREEN.
CLAMP: BRASS, NICKEL PLATED.

25.86 | 10 | | 1-282834-0
23.32 | 9 | | 282834-9
20.78 | 8 | | 282834-8
18.24 | | 7 | 282834-7
15.70 | | 6 | 282834-6
13.16 | | | 5 | 282834-5
10.62 | | | 4 | 282834-4
8.08 | | | 3 | 282834-3
5.54 | | | 2 | 282834-2

RECOMMENDED PC BOARD LAYOUT

NAME
TERMINAL BLOCK PCB MOUNT
SIDE WIRE ENTRY STACKING
2.54mm PITCH

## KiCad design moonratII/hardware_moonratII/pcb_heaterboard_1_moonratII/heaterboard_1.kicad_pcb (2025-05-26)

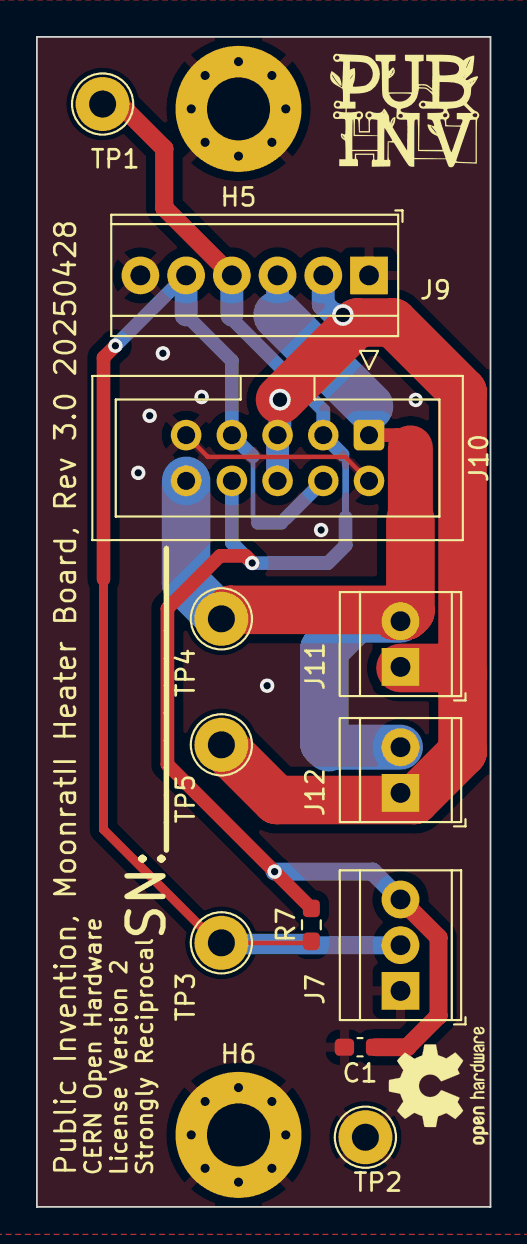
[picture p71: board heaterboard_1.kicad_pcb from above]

Board: 2 copper layers, 25.2 x 65.0 mm, 15 parts (0 on the bottom side), 5 nets.

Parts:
C1: 0.1uF; C_0603_1608Metric_Pad1.08x0.95mm_HandSolder
H5, H6: MountingHole_Pad_3.5mm; MountingHole_3.5mm_Pad_Via
J7: Screw_Terminal_01x03; GeneralPurposeAlarmDevicePCB_282834-3_1x03_P2.54mm_Horizont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
J9: Screw_Terminal_01x06; GeneralPurposeAlarmDevicePCB_282834-6_1x02_p254mm_Horizontal
J10: Conn_02x05_Odd_Even; IDC-Header_2x05_P2.54mm_Vertical
J11, J12: Screw_Terminal_01x02; GeneralPurposeAlarmDevicePCB_282834-2_1x02_P2.54mm_Horizont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
R7: 4K7; R_0603_1608Metric_Pad0.98x0.95mm_HandSolder
SM1: Logo_Open_Hardware_Small; OSHW-Logo2_7.3x6mm_SilkScreen
TP1: +5P; TestPoint_Loop_D2.54mm_Drill1.5mm_Beaded
TP2: TP_GND; TestPoint_Loop_D2.54mm_Drill1.5mm_Beaded
TP3: TempOut_IB; TestPoint_Loop_D2.54mm_Drill1.5mm_Beaded
TP4: HeaterDrive_IB; TestPoint_Loop_D2.54mm_Drill1.5mm_Beaded
TP5: VCCQ; TestPoint_Loop_D2.54mm_Drill1.5mm_Beaded

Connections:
+5P: C1.1, J7.3, J9.4, J10.3, J10.8, R7.2, TP1.1
/HeaterDrive_IB: J9.3, J10.1, J10.10, J11.2, J12.2, TP4.1
/TempOut_IB: J7.2, J9.5, J10.4, J10.7, R7.1, TP3.1
GND1: C1.2, H5.1, H6.1, J7.1, J9.1, J9.6, J10.2, J10.9, TP2.1
VCCQ: J9.2, J10.5, J10.6, J11.1, J12.1, TP5.1

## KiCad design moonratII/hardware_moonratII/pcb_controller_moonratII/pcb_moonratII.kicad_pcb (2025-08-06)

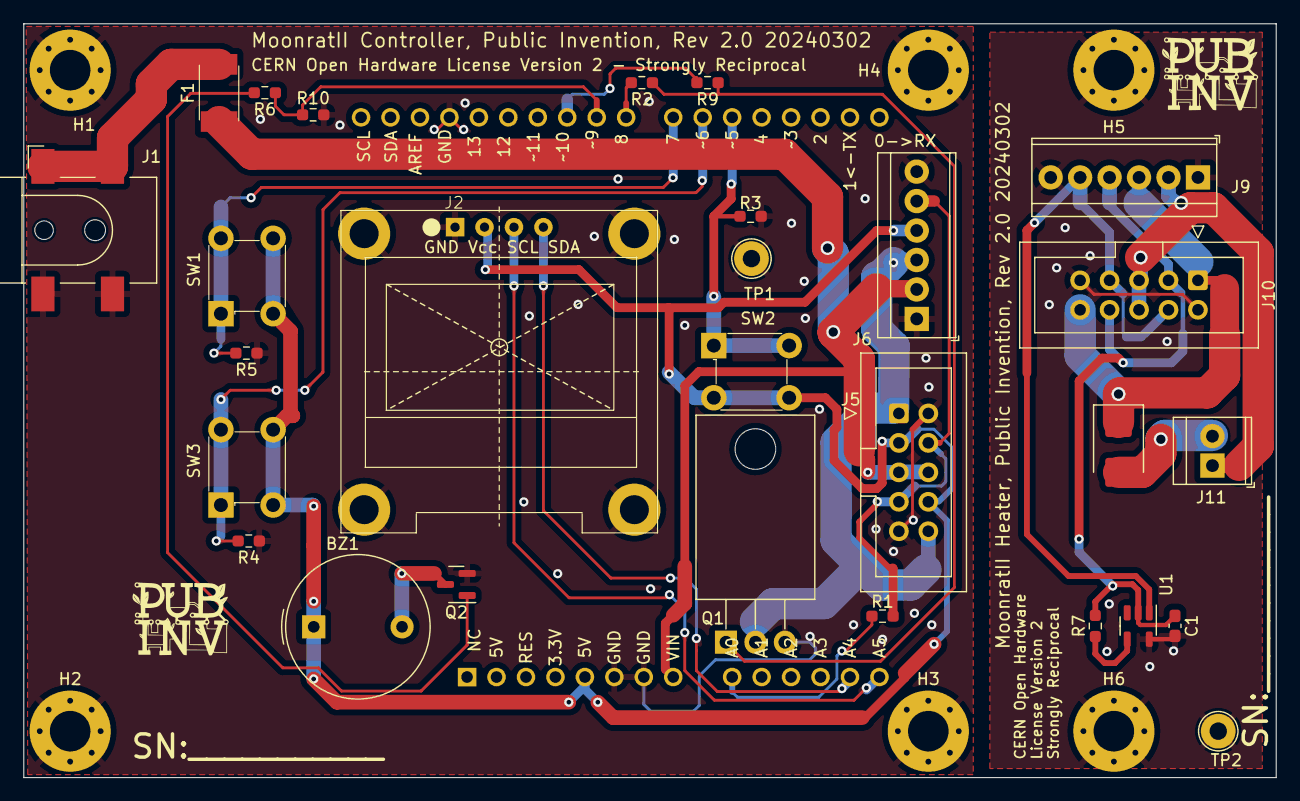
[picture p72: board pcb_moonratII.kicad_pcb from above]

Board: 2 copper layers, 108.0 x 65.0 mm, 35 parts (1 on the bottom side), 25 nets.

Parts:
A1: Arduino_UNO_R3 with uUSB and Cable; Arduino_UNO_R3_NoMountingHoles3D_Text_Top_&_Bottom
BZ1: Buzzer_D12mm_H9.6mm_LS7.6mm; Buzzer_12.2mm_9.7mm_7.62mm
C1: 0.1uF; C_0603_1608Metric_Pad1.08x0.95mm_HandSolder
D1: Schottky 2A; D_SMB
F1: Polyfuse 6A; Fuse_BSMD_1812
H1, H2, H3, H4, H5, H6: MountingHole_Pad_3.5mm; MountingHole_3.5mm_Pad_Via
J1: Barrel_Jack_Switch_SMT; BarrelJack_CLIFF_FC681465S_SMT_Horizontal
J2: HS96L03W2C03_0.96_Oled; OLED_HS96L03W2C03_0.96_WithNuts
J5, J10: Conn_02x05_Odd_Even; IDC-Header_2x05_P2.54mm_Vertical
J6, J9: Screw_Terminal_01x06; 1x6P 20A -40℃~+105℃ 300V Green 12~30 Straight pin 5.08mm 2.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
J11: Screw_Terminal_01x02; TerminalBlock_TE_282834-2_1x02_P2.54mm_Horizontal
Q1: IRF540N; TO-220-3_Horizontal_TabDown
Q2: BSS138; SOT-23
R1, R7: 1R; R_0603_1608Metric_Pad0.98x0.95mm_HandSolder
R2: DNI; R_0603_1608Metric_Pad0.98x0.95mm_HandSolder
R3, R4, R5, R6, R9: 1K; R_0603_1608Metric_Pad0.98x0.95mm_HandSolder
R10: 10K; R_0603_1608Metric_Pad0.98x0.95mm_HandSolder
SW1, SW2, SW3: 6mm 2 Pin Tact NO Breadboard Friendly; Switch_Tactile_THT_6x6mm
TP1, TP2: TP_GND; TestPoint_Loop_D2.54mm_Drill1.5mm_Beaded
U1: TMP36GRTZ-REEL7; SOT-23-5

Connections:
+5P: C1.1, J9.4, J10.3, J10.8, R7.2, U1.2 (+Vs)
+5V: A1.5 (+5V), BZ1.1 (-), J2.2, J5.3, J5.8, J6.4, SW1.3 (K), SW1.4 (A), SW2.3 (K), SW2.4 (A), SW3.3 (K), SW3.4 (A)
BTN_DOWN: A1.22 (D7), R5.2, SW1.1, SW1.2
BTN_SELECT: A1.20 (D5), R3.2, SW2.1, SW2.2
BTN_UP: A1.21 (D6), R4.2, SW3.1, SW3.2
BUZZER_ON: A1.24 (D9), R6.1, R10.1
GND: A1.6 (GND), A1.7 (GND), A1.29 (GND), H1.1, H2.1, H3.1, H4.1, J1.2, J1.3, J2.1, J2.5, J2.6, J2.7, J2.8, J5.2, J5.9, J6.1, J6.6, Q1.3 (S), Q2.2 (S), R3.1, R4.1, R5.1, R10.2, TP1.1
GND1: C1.2, H5.1, H6.1, J9.1, J9.6, J10.2, J10.9, TP2.1, U1.5 (V_{SS})
HEATER_ON: Q1.1 (G), R2.1, R9.1
HeaterDrive: J5.1, J5.10, J6.3, Q1.2 (D)
HeaterDrive_IB: D1.1 (K), J9.3, J10.1, J10.10
unnamed: A1.23 (D8), R2.2
unnamed: A1.25 (D10), R9.2
unnamed: BZ1.2 (+), Q2.3 (D)
unnamed: D1.2 (A), J11.2
unnamed: F1.2, J1.1, J1.4
unnamed: Q2.1 (G), R6.2
unnamed: R7.1, U1.4 (/SHUTDOWN)
SCL: A1.14 (SCL/A5), J2.3
SDA: A1.13 (SDA/A4), J2.4
TEMP_IN: A1.9 (A0), R1.1
TempOut: J5.4, J5.7, J6.5, R1.2
TempOut_IB: J9.5, J10.4, J10.7, U1.1 (Vout)
VCC: A1.8 (VIN), F1.1, J5.5, J5.6, J6.2
VCCQ: J9.2, J10.5, J10.6, J11.1

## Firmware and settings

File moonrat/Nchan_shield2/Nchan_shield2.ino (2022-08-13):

//  Moonrat Control Code
//  Copyright (C) 2021 Robert L. Read and Halimat Farayola
//
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
// Note: When used with a 12V power supply, this code currently "overshoots"
// the target temperature due to the time it take for heat to flow from the
// heating element into the chamber and the sensor.
// Although we could solve this problem in a number of ways, the most versatiCompule
// would appear to be to use a PID controller where (without the integrative component.)
// This allows the rate of heating to be a negative feedback.

// TODO: This problem has two control problems that are quite distinct, and should
// be treated so to avoid overshoot. The first is a "warm up" phase which should 
// be done at full-blast until we get within a few degrees of the target, then
// at some proportional power to prevent overshoot. The second phase
// should use the PID controller to try to hold the temperature as close
// to the target as possible. 

#define NCHAN_SHIELD 1
// #define RICE_PETRI_FI 2
// #define HALIMAT_VERSION 3

#define LOG_VERBOSE 5
#define LOG_DEBUG 4
#define LOG_WARNING 3
#define LOG_MAJOR 2
#define LOG_ERROR 1
#define LOG_PANIC 0
#define LOG_LEVEL 3

// These are Menu items
#define TEMPERATURE_M 0
#define GRAPH_1_M 1
#define SET_TEMP_M 2
#define STOP_M 3

#include <PID_v1.h>
#include <Adafruit_I2CDevice.h>
#include <Adafruit_I2CRegister.h>
#include <Adafruit_SPIDevice.h>
#include <Adafruit_BusIO_Register.h>
#include <stdio.h>
#include <math.h>
// Note: This is not currently in use!!!
// #include <Adafruit_GrayOLED.h>
#include <gfxfont.h>
#include <Adafruit_GFX.h>
#include <Adafruit_SPITFT.h>
#include <Adafruit_SPITFT_Macros.h>
#include <Adafruit_SSD1306.h>
#include <splash.h>
// EEPROM for arc32 - Version: Latest
#include <EEPROM.h>
#include <SPI.h>
#include <Wire.h>
// For our temperature sensor

// This hardware uses a "onewire" digital temperature sensor
#ifdef NCHAN_SHIELD

// The transitor drains through 
// The display at the "bottom" of the board. Count the header pins
// starting from the bottom:
// H0: Transistor PIN closest to Bottom (GND)
// H1: Unused
// H2: 12V
// H3: A0
// H4: +5V
// H5: GND

#define INPUT_PIN A0
#include <OneWire.h>
#include <DallasTemperature.h>
OneWire oneWire(INPUT_PIN);
// Pass our oneWire reference to Dallas Temperature.
DallasTemperature sensors(&oneWire);
#endif

//display variables
#define WIDTH 128
#define HEIGHT 64
#define SPLIT 16 // location of the graphing area (vertially, down from the top)
#define LEFT_MARGIN 9
#define LINE_HEIGHT 9
#define OLED_RESET 4
Adafruit_SSD1306 display(WIDTH, HEIGHT, &Wire, OLED_RESET);

//pin variables
#define HEAT_PIN 9 // This needs to be a PWM pin!  
#define BTN_SELECT 5
#define BTN_UP 6
#define BTN_DOWN 7

#define BZR_PIN 9

//temperature variables
#define TEMP_PIN A0  //This is the Arduino Pin that will read the sensor output
int sensorInput;    //The variable we will use to store the sensor input

#define MAX_TEMPERATURE_C 40

// #define USE_DEBUGGING
// #define USE_DEBUGGING 1
// #define USE_LOW_TEMP 1
#ifdef USE_LOW_TEMP
uint16_t targetTemperatureC = 30;// Celcius
#else
uint16_t targetTemperatureC = 35;// Celcius
#endif

// Variables to represent the state of the machine
// BASIC_STATE (this is different from the GUI State)
#define PREPARING 0
#define INCUBATING 1
#define FINISHED 2
int basic_state = INCUBATING;

// When Incubating, when are in two modes: warm-up phase or balance phase.
// The warm-up phase occurs when you we are first turned on or badly too cool.
// the balance phase is when we want slow stable mainteance of the target temperature.
// I am aribritraily defining warm-up phase as 4C below target phase.
#define WARM_UP_TEMP_DIFF_C 4.0
int warm_up_phase = true;

// This is a change to use PWM on our transistor, and further more
// to use a PID controller to set this parameter.
//Define Variables we'll be connecting to
#define USE_PID_AND_PWM 1
double Setpoint = 0.0 ,
       Input = 0.0,
       Output = 0.0;

// Think we can create a different set of factors for the startup period.
// Basically we will have zero integration, a high Kd, and a high Kp.
double SLOW_DOWN_FACTOR = .05;

// Once we get within 4 degrees of the target temp, we will switch from the 
// Startup parameters to the normal parameters.
// These are specifically stable for 12V power supply near the temperature range.
//Specify the links and initial tuninng parameters

double SKp = 10.0 / SLOW_DOWN_FACTOR, SKi = 0.0 / SLOW_DOWN_FACTOR, SKd = 1.0 / SLOW_DOWN_FACTOR;

// NOTE: These prameters seem to work pretty well once the stable temperature is 
// reached, but overshoot badly if you start, so we really need a two phase solution!!
// double Kp = 7.0 / SLOW_DOWN_FACTOR, Ki = 3.0 / SLOW_DOWN_FACTOR, Kd = 2.0 / SLOW_DOWN_FACTOR;
double Kp = 7.0 / SLOW_DOWN_FACTOR, Ki = 3.0 / SLOW_DOWN_FACTOR, Kd = 2.0 / SLOW_DOWN_FACTOR;



PID* myPID = 0;

// This is the "Control Variable". It's range is 0-255, and it
// is the a PWM value for our heating circuit.
double target_duty_cycle = 0.0;

int rawTemp = 0;
float temperatureC;        //The variable we will use to store temperature in degrees.
bool heating = false;

// This is switched ONLY when turning heater on or off.
bool currently_heating = false;
uint32_t time_incubation_started_ms = 0;
uint32_t time_heater_turned_on_ms = 0;
uint32_t time_spent_heating_ms = 0;
uint32_t time_spent_incubating_ms = 0;
uint32_t time_of_last_entry = 0;


// This is ten minutes, this should give us more
// than 48 hours. We record data in the eprom at this rate 
// once the begin is done.
unsigned long BASE_DATA_RECORD_PERIOD = 600000;

// For DEBUGGING, we may use a faster rate, of every 10 seconds
#ifdef USE_DEBUGGING
unsigned long DATA_RECORD_PERIOD = (BASE_DATA_RECORD_PERIOD / 60);
#else
unsigned long DATA_RECORD_PERIOD = BASE_DATA_RECORD_PERIOD;
#endif


//time variables
#define FIVE_MINUTES 300000

#define FORTYEIGHT_HOURS 172860000 //forty eight hours
#define TICK_LENGTH 125
//graph variables
int graphTimeLength = 24;//2 hours long bexause plotting every 5 mins
/*graphTimeLength2=511;*/

int center = SPLIT + ((64 - SPLIT) / 2); // (of ex axis?)
int graphwidth = 128 - LEFT_MARGIN;
int xaxisleft = LEFT_MARGIN * 2;
int xaxismid = LEFT_MARGIN + (graphwidth / 2) - 4;
int xaxisright = 128 - 24;


//int countery=0;
//int timerpulse=0;

//menu variables
int menuSelection = 0;
bool inMainMenu = true;
bool up ;
bool down ;
bool sel ;

const int BAUD_RATE = 9600;

//eeprom variables
// This basically implements a ring buffer...
// NOTE: I treat the EEPROM as 16-bit words.
#define TARGET_TEMP_ADDRESS 511
// Because we keep the "INDEX" at location, we chave to be careful
// about our accounting and our meaning.
// INDEX is the number of samples we have at any point in time.
// Our functions to read and write must remove the 0-indexed element
// in which a sample is not stored.
#define INDEX_ADDRESS 0 //location of index tracker in EEPROM
#define MAX_SAMPLES 509 //maximum number of samples that we can store in EEPROM
uint16_t value1;//first two bits of eeprom storage
uint16_t value2;//last bits of EEprom

//other variables
uint32_t milliTime = 0; // time of incubation start
bool incubating = true;
bool entryFlag = false; //set to true when data should be put in EEPROM ie every 5 minutes
int ticksSinceHeat = 0;
int b = 1; //initialize serial print index


void enter_warm_up_phase() {
  // These are the "balance" points
//  myPID = new PID(&Input, &Output, &Setpoint, SKp, SKi, SKd, DIRECT);
//  myPID = new PID(&Input, &Output, &Setpoint, Kp, Ki, Kd, DIRECT);
  myPID->SetTunings(SKp, SKi, SKd);          
//  myPID->SetOutputLimits(0, 255);
//  myPID->SetMode(AUTOMATIC); 
  warm_up_phase = true;
  Serial.println(F("Entered Warmup Phase!"));
}
void leave_warm_up_phase() {
  // These are the "balance" points
//  myPID = new PID(&Input, &Output, &Setpoint, Kp, Ki, Kd, DIRECT);
  myPID->SetTunings(Kp, Ki, Kd); 
//  myPID->SetOutputLimits(0, 255);
//  myPID->SetMode(AUTOMATIC);
  warm_up_phase = false;
  Serial.println(F("Left Warmup Phase!")); 
}

//gets the contents of the EEPROM at each indec
float readIndex(int index) {
  if (index > MAX_SAMPLES) {
    return -1;
  }
  uint16_t bitData = rom_read16((index+1) * 2);
  return sixteenToFloat(bitData);
}

// DISPLAY FUNCTIONS --------------------------------------------------
//dispays the current temperature i.e. when menu option 'temparature' is selected
void showCurStatus(float temp, float duty_factor) {
  display.clearDisplay(); //removes current plots
  display.setCursor(0, 0);
  display.setTextSize(1);
  display.print(F("T (C):"));
  display.println(temp);
  display.print(F("F (%):"));
  display.println(duty_factor * 100);
  display.display();
}

void showSetTempMenu(float target) {
  display.clearDisplay(); //removes current plots
  display.setCursor(0, 0);
  display.setTextSize(1);
  display.println(F("Up (U) to increase,"));
  display.println(F("Dn (D) to decrease,"));
  display.print(F("T (C):"));
  display.println(target);
  display.display();
}

// here we dump to the serial port for debugging and checking 
void dumpData() {
   Serial.println(F("DATA DUMP:")); 
   uint16_t num_samples = rom_read16(INDEX_ADDRESS); 
   Serial.print(F("# samples: "));
   Serial.println(num_samples);
   if (num_samples > MAX_SAMPLES) num_samples = MAX_SAMPLES;
   for (int i = 0; i < num_samples; i++) {
    float currenttemp = readIndex(i);
    Serial.print(i);
    Serial.print(F(" "));
    Serial.println(currenttemp);
   }
   Serial.println(F("Done with output!"));
}

/*
   Shows a graph of the temperature data over a period of time
*/

void showGraph(int eeindex) {

//  int graphMaxTemp = targetTemperatureC + 2; //initializing max temp
//  int graphMinTemp = targetTemperatureC - 2; //initializing min temp
//  int graphMaxTemp1 = targetTemperatureC + 20; //initializing max temp
//  int graphMinTemp1 = targetTemperatureC - 20; //initializing min temp
//  int maxtarget = targetTemperatureC + 2; //max range for target temp
//  int mintarget = targetTemperatureC - 2; //min range for target temp
  //TODO find out have to shift x axis values
  //Graph

  int num_samples_drawn = min(graphwidth,eeindex);
// I guess these are supposed to be in hours...
  float timeleft = 0; //(xaxisright-xaxisleft)*FIVE_MINUTES;
float timemid = (((float)(num_samples_drawn) / 2) * DATA_RECORD_PERIOD) / 3600000; //(xaxisright-xaxismid)*FIVE_MINUTES;
float timeright = ((float)(num_samples_drawn) * DATA_RECORD_PERIOD) / 3600000; //xaxisright*FIVE_MINUTES;

    int diff1;
  int diff2;
  
  // index begins at the end minus graph width
  int startIndex = (eeindex > graphwidth) ? eeindex - graphwidth : 0;
  //plots 119 points fron the EEPROM Contents at a period of 5 minutes
  // This logic should render the last 119 samples, I suppose
  float maxTempToGraph = -1.0;
  float minTempToGraph =  5000.0;
  for (int i = startIndex; i < eeindex; i++) {
     float currentTemp = readIndex(i); 
     minTempToGraph = min(minTempToGraph,currentTemp);
     maxTempToGraph = max(maxTempToGraph,currentTemp);
  }


  int graphMaxTemp = ceil(maxTempToGraph);
  int graphMinTemp = floor(minTempToGraph);
  
  display.clearDisplay();
  display.setTextSize(2);
  display.setCursor(0, 0);
  display.print(F("# sam:"));
  display.println(eeindex);
  
  display.setTextSize(1);
  display.setCursor(1, SPLIT);
  display.println(graphMaxTemp);
  display.setCursor(1, 56);
  display.println(graphMinTemp);
  display.setCursor(LEFT_MARGIN * 2, 56);
  display.println(timeleft);
  display.setCursor(xaxismid, 56);
  display.println(timemid);
  display.setCursor(xaxisright, 56);
  display.println(timeright);

    // Pixels per degree
    float scale = (64.0 - SPLIT) / (float) (graphMaxTemp - graphMinTemp); //creates scale y axis pixels

  float meanTemp = (((float) graphMaxTemp + (float) graphMinTemp) / 2.0);
  float middle = meanTemp - (float) graphMinTemp;
  int j = 0;
  for (int i = startIndex; i < eeindex; i++) {
    float currentTemp = readIndex(i); 
    float ypos = (currentTemp - graphMinTemp);

    int x = LEFT_MARGIN + j;
    int y = (64 - (scale * ypos));
    int midy = (64 - (scale * middle));  
    display.drawPixel(x, y, SSD1306_WHITE); //plots temparature
    display.drawPixel(x, midy, SSD1306_WHITE);
    j++; 
   }

  display.display();
}

/* Displays the menu.

   Menu Options:
   - Show Temperature : switches to temperature display mode
   - Show Graph : switches to graph dispay mode
   - Start/Stop : starts or stops data collection
   - Set Target : sets the target incubation temperature
   - Export : send temperature data through serial port to a pc
   - Reset : resets temperature data
*/
void showMenu() {
  display.setTextColor(SSD1306_WHITE);
  display.clearDisplay();
  //print title
  display.setCursor(0, 0);
  display.setTextSize(2);
  display.print(F("Menu"));
  display.setTextSize(1);
  //displays time since incubation started
  display.setCursor(56, 7);

  // It's really useful to see the current temp at all times...
  double curTemp = read_temp();
  display.print(curTemp);
  display.print(" ");
  char currentTime[80];
 // String currentTime = 
  getTimeString(currentTime);
  // chop off the seconds...
  currentTime[5] = '\0';
  display.println(currentTime);
  //menu option for current temperature
  display.setTextSize(1);
  display.setCursor(LEFT_MARGIN, SPLIT);
  //menu option for current temperature
  display.println(F("Temperature"));
  display.setCursor(LEFT_MARGIN, SPLIT + LINE_HEIGHT);
  //menu option for detailed graph
  display.println(F("Graph 1"));
  display.setCursor(LEFT_MARGIN, SPLIT + 2 * LINE_HEIGHT);
  //menu option for graph over 48 hours
//  display.println(F("Graph 2"));
//  display.setCursor(LEFT_MARGIN, SPLIT + 3 * LINE_HEIGHT);
  //menu option for entering the target temparature. Entered by clicking the up/down buttons
  display.println(F("Set Temperature"));
  display.setCursor(LEFT_MARGIN, SPLIT + 3 * LINE_HEIGHT);
  if (incubating) {
    display.println(F("Stop"));
  } else {
    display.println(F("Start"));
  }
  //print cursor
  display.setCursor(0, SPLIT + menuSelection * LINE_HEIGHT);
  display.fillCircle(3, SPLIT + menuSelection * LINE_HEIGHT + 3, 3, SSD1306_WHITE);
  display.display();
}

// UTILITY FUNCTIONS --------------------------------------------------
void incubationON() {
  if (incubating) return;
  time_incubation_started_ms = millis();

}
void incubationOFF() {
  if (!incubating) return;
  uint32_t time_now = millis();
  time_spent_incubating_ms = time_now - time_incubation_started_ms;
}
uint32_t time_incubating() {
  return (incubating) ?
         millis() - time_incubation_started_ms :
         time_spent_incubating_ms;
}

uint32_t time_of_last_PWM;
int current_PWM;
double weighted_voltage_ms = 0.0;


float duty_factor() {
#ifdef USE_PID_AND_PWM
  return (double) (((millis() - time_of_last_PWM) * current_PWM/255.0) + weighted_voltage_ms)/ (double) time_incubating();
#else
  return (float) time_heating() / (float) time_incubating();
#endif
}

uint32_t time_heating() {
  return (currently_heating) ?
         time_spent_heating_ms +  (millis() - time_heater_turned_on_ms) :
         time_spent_heating_ms;
}
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
void loop() {
  delay(100);


  uint32_t loop_start = millis();
  // Test reading the buttons...
//  if (LOG_LEVEL >= LOG_VERBOSE) {
//    Serial.print(F("Incubating: "));
//    Serial.println(incubating);
//    Serial.print(F("Currently Heating: "));
//    Serial.println(currently_heating);
//  }

  boolean dumpdata = false;
  //read keyboard entries from the serial monitor
  char T;
  if (Serial.available()) {
    T = Serial.read(); //getting string input in varaible "T"

    Serial.print(F("T ="));
    Serial.println(T);
    up = (T == 'u');
    down = (T == 'd');
    sel = (T == 's');
    dumpdata = (T == 'x');
  } else {
    sel = digitalRead(BTN_SELECT);
    up = digitalRead(BTN_UP);
    down = digitalRead(BTN_DOWN);
  }

  if (dumpdata) {
    dumpData();
  }

//  if (LOG_LEVEL >= LOG_DEBUG) {
//    Serial.print(inMainMenu);
//    Serial.print(menuSelection);
//    Serial.print(F("-"));
//    Serial.print(sel);
//    Serial.print(up);
//    Serial.print(down);
//    Serial.println();
//  }
  // I don't know what this is supposed to do...
  int multiple = 0;
  if (!inMainMenu && sel) {
    returnToMain = true;
  }

  //controls menu selection
  if (inMainMenu) {
    //read buttons and menu
    if (up && menuSelection > 0) {
      menuSelection--;
    }
    else if (down && menuSelection < 3) {
      menuSelection++;
    }
    else if (sel) {
      inMainMenu = false;
    } 
    showMenu();
  }  else {
       switch (menuSelection) {
        case TEMPERATURE_M :
           showCurStatus(temperatureC, duty_factor());
          break;
        case GRAPH_1_M : {
          uint16_t index = rom_read16(INDEX_ADDRESS);
          showGraph(index);
        }
          break;
        case SET_TEMP_M : {  
        // This is wrong; we whould be showing instructions
          showSetTempMenu(targetTemperatureC);
          if (up) {
            if (targetTemperatureC > MAX_TEMPERATURE_C) {
              targetTemperatureC = MAX_TEMPERATURE_C;
              targetTemperatureC++;
            }
            targetTemperatureC++;
            setTargetTemp(targetTemperatureC);
          }
          if (down) {
            targetTemperatureC--;
            setTargetTemp(targetTemperatureC);
          }    
        }    
          break;
        case STOP_M : {
                  Serial.println(F("Toggling Incubation!"));
          if (!incubating) {
            // In this case, we want to restart the EEPROM...
            rom_reset();
            Serial.println(F("EEPROM RESET!"));
          }
          incubating = !incubating;
          milliTime = 0;
          inMainMenu = true;
        }
          break;
      }
      if (returnToMain) {
        returnToMain = false;
        inMainMenu = true;
      }
    }
  // We have to process menu changes without delay to have
  // a good user experience; but reading the temperature can
  // be delayed.
  if (loop_start <  (last_temp_check_ms + PERIOD_TO_CHECK_TEMP_MS  ))
    return;

  // otherwise we need to processe temperature stuff
  last_temp_check_ms = loop_start;

  temperatureC = read_temp();
  if (LOG_LEVEL >= LOG_DEBUG) {
    Serial.print(F("Temp (C): "));
    Serial.println(temperatureC);
    if (LOG_LEVEL >= LOG_VERBOSE ) {
      Serial.print(F("Target Temp (C): "));
      Serial.println(targetTemperatureC);
      Serial.print(F("Time spent incubating (s):"));
      Serial.println(((float) time_incubating()) / 1000.0);
      Serial.print(F("Time spent heating (s):"));
      Serial.println(((float) time_heating()) / 1000.0);
    }
  }
// Test warm_up_phase or not...
  if ((temperatureC < (targetTemperatureC - WARM_UP_TEMP_DIFF_C))
    && !warm_up_phase)
  {
    enter_warm_up_phase();
  }
  if ((temperatureC >= (targetTemperatureC - WARM_UP_TEMP_DIFF_C))
    && warm_up_phase)
  {
    leave_warm_up_phase();
  }
 
  int numEEPROM = 0;

  uint32_t time_now = millis();
  uint32_t time_since_last_entry = time_now - time_of_last_entry;

 // Here we write into the EEPROM for Data logging
#ifdef USE_DEBUGGING
    Serial.println(F("DEBUGGING MODE!"));
#endif

  if (time_since_last_entry > DATA_RECORD_PERIOD) {
    //  entryFlag = false;
    Serial.println(F("Writing New Entry"));
    writeNewEntry(temperatureC);
    time_of_last_entry = time_now;
  }

  // Here is the actual heat algorithm...
  int USE_PID;
#ifdef USE_PID_AND_PWM
  USE_PID = 1;
#else
  USE_PID = 0;
#endif

  if (USE_PID) {
    Setpoint = (double) targetTemperatureC;
    Input = temperatureC;
    if (LOG_LEVEL >= LOG_VERBOSE) {
      Serial.print(F("SetPoint"));
      Serial.println(Setpoint);
      Serial.print(F("Input:"));
      Serial.println(Input);
    }
    myPID->Compute();
    if (LOG_LEVEL >= LOG_VERBOSE) {
      Serial.print(F("Output:"));
      Serial.println(Output);
      Serial.println(target_duty_cycle);
    }
    target_duty_cycle = Output;
    setHeatPWM(target_duty_cycle);
  } else {

    //if temp below target turn heat on
    //if temp above target + gap turn heat off
    //if the incubating has started then start heating if the temperature is too low.
    // Note: This should probably protected as a "strategy".
    if (incubating) {
      if (temperatureC > (targetTemperatureC + 0.25)) {
        heatOFF();
      }
      else {
        if (temperatureC < (targetTemperatureC - 0.25)) {
          heatON();
        } else { // no change

        }
      }
    }
    else {
      heatOFF();
    }
  }

  if (LOG_LEVEL >= LOG_DEBUG) {
    if (time_incubating() > 0) {
      float duty_f = ((float) time_heating()) / ((float) time_incubating() );
//      Serial.print(F("Duty Factor: "));
//      Serial.println(duty_f);
//      Serial.println(duty_factor());
      if (LOG_LEVEL >= LOG_VERBOSE) {
        Serial.println(F("Warm Up: "));
        Serial.println(warm_up_phase);
        Serial.println(time_heating());
        Serial.println(time_incubating());
      }
    }
  }
  
  //countery=countery+1;
  //timerpulse=timerpulse+digitalRead(HEAT_PIN);
  //start buzzing after 48 hours until the user stops incubating
  int timern = ceil(milliTime / 1000);
  // I think this buzzes every minute...but the logic of this is wrong,
  // and I don't have a buzzer installed!
  // I think we need a new state to represent incubation ended..
  if (incubating && (timern % 60 == 0)) {
    //buzz();
    //Serial.println(float(timerpulse/countery));
  }

}

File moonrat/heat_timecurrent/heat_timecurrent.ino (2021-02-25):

#include <Adafruit_I2CDevice.h>
#include <Adafruit_I2CRegister.h>
#include <Adafruit_SPIDevice.h>
#include <Adafruit_BusIO_Register.h>
#include <stdio.h>
#include <math.h>
#include <Adafruit_GrayOLED.h>
#include <gfxfont.h>
#include <Adafruit_GFX.h>
#include <Adafruit_SPITFT.h>
#include <Adafruit_SPITFT_Macros.h>
#include <Adafruit_SSD1306.h>
#include <splash.h>
// EEPROM for arc32 - Version: Latest 
#include <EEPROM.h>
#include <SPI.h>
#include <Wire.h>

//display variables
#define WIDTH 128
#define HEIGHT 64
#define SPLIT 16 //location of x axis
#define LEFT_MARGIN 9
#define LINE_HEIGHT 9
#define OLED_RESET 4
Adafruit_SSD1306 display(WIDTH, HEIGHT, &Wire, OLED_RESET);

//pin variables
#define HEAT_PIN 8
//#define BTN_UP 6
//#define BTN_DOWN 7
//#define BTN_SELECT 5
#define BZR_PIN 9

//temperature variables
#define TEMP_PIN A0  //This is the Arduino Pin that will read the sensor output
int sensorInput;    //The variable we will use to store the sensor input
int targetTemperature = 95;//in fahrenheit
int rawTemp = 0;
float temperature;        //The variable we will use to store temperature in degrees.
bool heating = false;

//time variables
#define FIVE_MINUTES 300000

#define FORTYEIGHT_HOURS 172860000 //forty eight hours
#define TICK_LENGTH 125 
//graph variables
int graphTimeLength = 24;//2 hours long bexause plotting every 5 mins
/*graphTimeLength2=511;*/
int graphMaxTemp = targetTemperature+2; //initializing max temp
int graphMinTemp = targetTemperature-2; //initializing min temp
int graphMaxTemp1 = targetTemperature+20; //initializing max temp
int graphMinTemp1 = targetTemperature-20; //initializing min temp
int maxtarget= targetTemperature+2; //max range for target temp
int mintarget= targetTemperature-2; //min range for target temp
int center= SPLIT+ ((64-SPLIT)/2);
int graphwidth= 128-LEFT_MARGIN;
int xaxisleft=LEFT_MARGIN*2;
int xaxismid=LEFT_MARGIN+(graphwidth/2)-4;
int xaxisright=128-24;
float timeleft=0;//(xaxisright-xaxisleft)*FIVE_MINUTES;
float timemid=(((float)(graphwidth)/2)*FIVE_MINUTES)/3600000;//(xaxisright-xaxismid)*FIVE_MINUTES;
float timeright=((float)(graphwidth)*FIVE_MINUTES)/3600000;//xaxisright*FIVE_MINUTES;
//int countery=0;
//int timerpulse=0;

//menu variables
int menuSelection = 0;
bool inMenu = true;
bool up ;
bool down ;
bool select ;


//eeprom variables
#define INDEX_ADDRESS 0 //location of index tracker in EEPROM
#define MAX_ADDRESS 1023 //highest possible address in arduino UNO EEPROM
#define MAX_SAMPLES 511 //maximum number of samples that we can store in EEPROM
uint16_t value1;//first two bits of eeprom storage
uint16_t value2;//last bits of EEprom 

//other variables
uint32_t milliTime = 0;
uint32_t heatTime = 0;
bool incubating = false;
bool entryFlag = false; //set to true when data should be put in EEPROM ie every 5 minutes
int ticksSinceHeat = 0;
int b=1;//initialize serial print index


//gets the contents of the EEPROM at each indec
float readIndex(int index){
  if(index > MAX_SAMPLES){
    return -1;
  }
  uint16_t bitData = rom_read16(index*2);
  return sixteenToFloat(bitData);
}

// DISPLAY FUNCTIONS --------------------------------------------------
//dispays the current temperature i.e. when menu option 'temparature' is selected
void showNumber(float number){
  display.clearDisplay(); //removes current plots
  display.setCursor(28,24);
  display.setTextSize(2);
  display.println(number);
  display.display();
}

/*
 * Shows a graph of the temperature data over a period of time
 */

void showGraph(int eeindex){
  //TODO find out have to shift x axis values
  //Graph 
  if (eeindex>graphwidth){
 
    timeleft=timeleft+0.08333333333333;
    timemid=timemid+0.0833333333333;
    timeright=timeright+0.0833333333333;
  }
  display.clearDisplay();
  display.setTextSize(2);
  display.setCursor(0,0);
  display.println("GRAPH");
  display.setTextSize(1);
  display.setCursor(1, SPLIT);
  display.println(graphMaxTemp);
  display.setCursor(1, 56);
  display.println(graphMinTemp);
  display.setCursor(LEFT_MARGIN*2, 56);
  display.println(timeleft);
  display.setCursor(xaxismid, 56);
  display.println(timemid);
  display.setCursor(xaxisright, 56);
  display.println(timeright);
  int diff1;
  int diff2;
  int scale;
  int i=0;
  int j=0;
  // index begins at the end minus graph width
  if (eeindex>graphwidth){
    i=eeindex-graphwidth;
  }
  //plots 119 points fron the EEPROM Contents at a period of 5 minutes
  for(; i < eeindex; i++){
    float currenttemp=readIndex(i);
    int oldmaxtemp= graphMaxTemp;
    int oldmintemp= graphMinTemp;
    //changes max/min temp depending on current temp
    if (currenttemp>50){ //so that empty eeprom vals are not entered
      if (currenttemp>graphMaxTemp){  
        graphMaxTemp=ceil(currenttemp);
        display.setCursor(1, SPLIT);
        display.println(graphMaxTemp);
      }
      else if (currenttemp<graphMinTemp){
        graphMinTemp=floor(currenttemp)-1;
        display.setTextSize(1);
        display.setCursor(1, 56);
        display.println(graphMinTemp);
        //Serial.println(readIndex(i));
        
      }
    }
    diff1=graphMaxTemp-oldmaxtemp;  
    diff2= oldmintemp-graphMinTemp;
   
    
    int ypos = (int)(currenttemp - graphMinTemp);//subtract y coordinate from value of x axis
    scale= (int)((64-SPLIT)/(graphMaxTemp-graphMinTemp)); //creates scale y axis pixels
    //Serial.println(int(readIndex(i)));
    int middle= graphMinTemp +((graphMaxTemp-graphMinTemp)/2);
    //display.setCursor(1, center);
    //display.println(middle);
    if(ypos < 0)
      ypos = 0;
    
    display.drawPixel(LEFT_MARGIN + j,(64-(scale*ypos)), SSD1306_WHITE);//plots temparature
    //display.drawPixel(LEFT_MARGIN + i,(16+(diff1*scale)), SSD1306_WHITE); //draws horizontal line at max target, 2 degrees below target temp
    //display.drawLine(LEFT_MARGIN + i,(64-(diff2*scale)), SSD1306_WHITE);//draws horizontal line at min target, 2 degrees above target temp
    //display.drawFastHLine(LEFT_MARGIN,(64-(diff2*scale)),128-LEFT_MARGIN, SSD1306_WHITE);
    j+=1;
  }
  
  display.display();
}
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

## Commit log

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2020-08-06 fixed timer, added buzzer
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2020-08-13 corrected parts list
    [PartsList.xlsx]
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2021-01-27 Add files via upload
    box for circuit components and display
    [arduino_mount.scad]
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2021-05-13 Add files via upload
    Design for 3D printing
    [Assembly_solidworks.SLDASM, Base_holder_solidworks.SLDPRT]
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2021-07-31 Added more documentation to folders and adjusted file structure.
    [Heat Loss Experiment Data.xlsx, PetriFI Breadboard.fzz, PetriFI Perfboard.fzz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]
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2023-05-18 Update main README.md to link to images with smaller width. Add GIF files for schematic and PCB from the fritz design.
    [schematic.fzz]
2023-06-22 Initial KiCad schematic for moonratII based on Helma schematic at https://github.com/PubInv/moonrat/blob/master/moonrat/schematic.jpg
    [moonratII.kicad_pcb, moonratII.kicad_sch]
2023-06-22 Add the BOM generating spread sheet copied from the GPAD project.
    [moonratII_V1_BOM.xls]
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2023-07-27 Add annotations to reference designators on schematic. Create initial PCB and place components.
    [moonratII.kicad_sch]
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2023-07-30 Named more nets, Add reverse voltage protection.
    [moonratII.kicad_sch]
2023-07-30 Add many JLCPCB and other vendor part numbers. Add cables.
    [moonratII.kicad_sch]
2023-07-30 Pull in parts to PCB. Make some initial placement.
    [moonratII.kicad_pcb, moonratII.kicad_sch]
2023-07-30 Generated raw BOM and PL and pull into the BOM.xls. Still needs work.
    [moonratII_V1_BOM.xls]
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2023-07-31 Add remaning new footprint files, add parts files.
    [moonratII.kicad_pcb, moonratII.kicad_sch]
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2023-08-03 Add more PCB 3D models. Place and lock down mounting holes.
    [BarrelJackSMD v3.step, KF128-2.54-2P.step, KF128-2.54-6P.step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]
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2023-10-15 Add a FreeCAD file for an enclosure top.
    [enclosure_moonratii_Top.FCStd]
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2023-10-15 Fixed error in SO4B & add new OLED footprint to schematic & PCB
    [moonratII.kicad_pcb, moonratII.kicad_sch]
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2023-10-16 Fixed OLED footprint, BOM maintenance
    [moonratII.kicad_pcb, moonratII.kicad_sch]
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2023-11-04 Deleted board to board headers. Placed components before getting to route
    [moonratII.kicad_pcb, moonratII.kicad_sch]
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2023-11-06 Fixed footprint for SW 1, 2, 3. Significant update on bottom copper ground
    [moonratII.kicad_pcb, moonratII.kicad_sch]
2023-11-06 Performing design rule checks. Added ground between SCL & SDA traces to reduce the opportunity for cross talk.
    [moonratII.kicad_pcb, moonratII.kicad_sch]
2023-11-06 Update to fix schematic errors and warnings.
    [moonratII.kicad_sch]
2023-11-06 PCB: Solved 2 DNR errors and added teardrops.
    [moonratII.kicad_pcb]
2023-11-06 Solved 2 more PCB DNR errors.
    [moonratII.kicad_pcb]
2023-11-09 Cleared all PCB DRC errors and connection items.
    [moonratII.kicad_pcb]
2023-11-09 Cleared all DRC errors and warnings. Added 3 footprints
    [moonratII.kicad_pcb, moonratII.kicad_sch]
2023-11-12 Issue 70 completed: Add license info & open hardware & PI logo/symbols and related to schematic and PCB (Kicad)
    [moonratII.kicad_pcb, moonratII.kicad_sch]
2023-11-12 Issue 53: Added key caps to switches in schematic
    [moonratII.kicad_sch]
2023-11-15 Issue 114: Corrected U1 footprint. Changed from SOIC-8 to SOT-23-5.
    [moonratII.kicad_pcb, moonratII.kicad_sch]
2023-11-19 Add 3D models for OLED display, spacer and screws which are too short.
    [Pantalla OLED 0.96'' 128x64.stp, homemade_2mmx3mmx3mmSpacer-PartBody.step, homemade_2mmx3mmx3mmSpacer-PartBody.stl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]
2023-11-19 Fix 3D models buzzer. Some tweeks to enclosure top but still not up to date.
    [enclosure_moonratii_Top.FCStd]
2023-11-19 Update PCB with footrpint with OLED display 3D model.
    [moonratII.kicad_pcb]
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2023-11-20 Add footrpint for OLED using the SMD round nuts to be soldered into PCB.
    [SMDRoundNut-PartBody_SMD_RoundNutM2x4x5x1.5.step, SMDRoundNut.FCStd]
2023-11-20 Add M2x6 panhead screw to footrpint for OLED.
    [92005A023_Steel Pan Head Phillips Screw.STEP]
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2023-12-06 Added the buzzer dimensions to mechanical drawing issue 141
    [moonratII.kicad_pcb, moonratII.kicad_sch]
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2023-12-25 Fix error on PCB mount, delete a circle. Fix offset on switch and buzzer.
    [enclosure_moonratii_Top.FCStd]
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2024-02-07 Clear all DRC errors. Clear most warnings.
    [moonratII.kicad_pcb]
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2024-02-28 update heater pin out and buzzer pin output
    [moonratII.ino]
2024-02-28 moonratII update V10
    Changes in this version:
    The pins were modified to match the PCB layout.
    The software and simulation version was added.
    The buzzer pin was added.
    The functions were improved.
    [moonratII.ino]
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2024-02-29 Revert "Make vcc heavy"
    [moonratII.kicad_pcb, moonratII.kicad_sch]
2024-03-02 Fix issues 210, 211, 215, 195, and 216.
    [moonratII.kicad_pcb, moonratII.kicad_sch]
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2024-03-02 Change date of schematic and PCB for rev 2. Tweek to PCB after changing BoardSetupContratins.
    [moonratII.kicad_pcb, moonratII.kicad_sch]
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2024-03-03 Add resistor so buzzer off during reset.
    [moonratII.kicad_pcb, moonratII.kicad_sch]
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2024-07-05 Add files via upload
    Top and basis v2 of monrat enclousure II
    [base.FCStd, tapa.FCStd]
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2024-09-16 Add files via upload
    Version 2 of enclosure's base, with arduino R3 and R4 hole for connection.
    [base_v2_arduinoporthole.stl]
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2024-10-11 Fixing counter & Tunning PID
    This code resolved some issues; the counter is set in hours, but the timer stops in minutes [Fixed]. The PID controller gains are new, tested, and tuned based on the prototype behavior.
    [new_complete.ino]
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2024-11-02 separating time persistence, display not working
    [Persistence.cpp]
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2024-12-06 Modified BOM, schematic, and created assembly in Freecad of PWA and enclosure.
    [90591A250_NO THREADS_Zinc-Plated Steel Hex Nut.STEP, 94387A215_NO THREADS_JIS Steel Pan Head Screws.STEP, moonratII.kicad_sch]
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2024-12-07 Deleted controller from heater board Schematic and PCB files. Deleted proxy from Assy_Enclosure_Rev2_PWA.FCStd file.
    [Heater_board_Rev2.kicad_pcb, Heater_board_Rev2.kicad_sch]
2024-12-07 Aligned top left mounting hole, deleted and readded nut and screw, deleted enclosure text in file moonratII/enclosure_mooonratII/Assy_Enclosure_Rev2_PWA.FCStd.
    [90591A250_NO THREADS_Zinc-Plated Steel Hex Nut.STEP, 94387A215_NO THREADS_JIS Steel Pan Head Screws.STEP]
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2025-01-15 fixing a bug in the menu
    [MoonRat.ino]
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2025-03-16 Replaced Arduino Uno R3 with R4 on controller board.
    [Heater_board_Rev2.1.kicad_pcb, Heater_board_Rev2.1.kicad_sch]
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2025-04-21 Creating heaterboard_1 folder in order to create an updated heater PCB only.
    [92005A023_Steel Pan Head Phillips Screw.STEP, B3F-6050--3DModel-STEP-273799.STEP, BarrelJackSMD v3.step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]
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2025-04-29 heaterboard_1/heaterboard_1.kicad_sch Adding DS18B20 digital thermometer and 4.7 resistor to schematic, add datasheet.
    [heaterboard_1.kicad_sch]
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2025-04-29 heaterboard_1.kicad_sch Using bulk editor, all part numbers and vaules correct.
    [heaterboard_1.kicad_sch]
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2025-05-05 heaterboard_1/heaterboard_1.kicad_sch Correcting changed reference designators.
    [heaterboard_1.kicad_sch]
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2025-05-05 heaterboard_1/heaterboard_1.kicad_pcb Adding new test points and parts from schematic to the PCB.
    [heaterboard_1.kicad_pcb]
2025-05-06 heaterboard_1/heaterboard_1.kicad_pcb Deleting all traces associated with the Control Board. Heater Board: placing connectors and testpoints.
    [heaterboard_1.kicad_pcb]
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2025-05-06 heaterboard_1/heaterboard_1.kicad_pcb Corrected the silkscreen date and version for the Heater Board.
    [heaterboard_1.kicad_pcb]
2025-05-16 heaterboard_1.kicad_pcb Added open source symbol to the PCB silkscreen layer and unified title block for board silkscreen and schematic.
    [heaterboard_1.kicad_pcb, heaterboard_1.kicad_sch]
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2025-05-20 heaterboard_1.kicad_pcb and _sch files Cleared all design errors and warnings.
    [KF128-2.54-2P.step, KF128-2.54-6P.step, heaterboard_1.kicad_pcb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]
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2025-05-26 heaterboard_1.kicad_sch, change H5 and H6 to exclude from BOM. Generate CSV BOM file. Modify .gitignore so as to put CSV under version control.
    [heaterboard_1.csv, heaterboard_1.kicad_sch]
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2025-08-06 pcb_moonratII.kicad_pcb,updated 3D models for keycaps and buzzer.
    [pcb_moonratII.kicad_pcb, pcb_moonratII.kicad_sch]
2025-08-06 pcb_moonratII.step, updated 3D models for keycaps and buzzer.
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2025-08-08 cover.FCStd, cleared Wire Not Closed error on OLED and mounting hole centered.
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2025-08-20 cover.FCStd, fully contrained switches, OLED, and buzzer.
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2025-08-28 moonratII/, Moved heaterboard_1/ into moonratII/; tagged 3 files as OBSOLETE for future deletion.
    [92005A023_Steel Pan Head Phillips Screw.STEP, B3F-6050--3DModel-STEP-273799.STEP, BarrelJackSMD v3.step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]
2025-08-29 moonratII/, corrected folder name from enclosure_mooonratII to enclosure_moonratII.
    [MoonratII_Enclosure_Controler_top.FCStd, MoonratII_Enclosure_Controler_top.SLDPRT, MoonratII_Enclosure_Controler_top.STL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]
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2025-08-29 Rename moonratII/hardware_moonratII/pcb_controller_moonratII/GeneralPurposeAlarmDevicePCB.pretty/1x2P 20A -40℃~+105℃ 300V Green 12~30 Straight pin 5.08mm 2.5 1 2 Plugin,P=5.08mm Screw terminal ROHS.k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
    Changing name to shorter name
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2025-08-31 fixing some bugs found when writing paper.
    [MoonRat.ino]
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2025-09-10 cover.FCStd, Eye ball clearance for Stackable Sockets.
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2025-09-11 cover.FCStd, develoope Boss higher. Reduce for shallow counterbore for 8mm long screws.
    [base_Rev2_Freecad1.0.FCStd]
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2025-11-17 cover_v2_20251116-Body_Cover, enlarged and left shifted switch holes, as well as widened power jack opening.
    [base.step, cover_v2_20251116-Body_Cover.stl]
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2025-12-01 Project closeout preparation: updated file names to short form.
    [DELETE_Assembly_Bracket_Heater.FCStd, controller_base.FCStd, controller_base.stl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]
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

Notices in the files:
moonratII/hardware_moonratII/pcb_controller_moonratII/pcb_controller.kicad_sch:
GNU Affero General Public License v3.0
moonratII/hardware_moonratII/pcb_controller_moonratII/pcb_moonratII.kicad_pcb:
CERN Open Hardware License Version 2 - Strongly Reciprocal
